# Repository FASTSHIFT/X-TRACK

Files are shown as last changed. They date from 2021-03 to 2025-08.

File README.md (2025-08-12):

# X-TRACK
> 开源GPS自行车码表。
> 
> 拥有可显示实时位置的离线地图。
> 
> 支持记录和显示实时轨迹以及导出标准GPX格式的轨迹文件。
> 
> 全新设计的["页面生命周期管理"](https://github.com/FASTSHIFT/X-TRACK/tree/main/Software/X-Track/USER/App/Utils/PageManager)和["消息订阅发布框架"](https://github.com/FASTSHIFT/X-TRACK/tree/main/Software/X-Track/USER/App/Utils/DataCenter)。
>
> 演示视频：https://www.bilibili.com/video/BV1GB4y1K7VV
>
> 二代版本：https://www.bilibili.com/video/BV1aS421X779

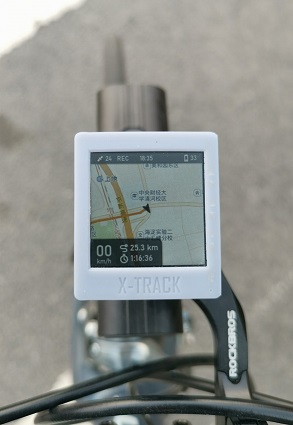
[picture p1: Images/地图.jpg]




## GUI
> [LVGL V8](https://github.com/lvgl/lvgl)

## 硬件配置
* 1.主控: AT32F435CGU7 (主频:288MHz RAM:512KB ROM:1MB)
* 2.屏幕: ST7789 IPS 1.54inch SPI接口 240x240分辨率 60Hz刷新率
* 3.储存器: Micro SD CARD 32GB 
* 4.输入设备: 旋转编码器
* 5.RTC: MCU内置RTC时钟
* 6.加速度计: LSM6DSM (支持硬件计步输出)
* 7.地磁计: LIS3MDL
* 8.GPS: ATGM336H (BDS + GPS + GLONASS + GALILEO + QZSS + SBAS)
* 9.电池: Li-ion 3.7V 683030 700mAh
* 10.电源管理: LP5907-3.3 + MCP73831
* 11.外壳: 3D打印 光固化

## 功能
* 1.支持速度、距离、时间、卡路里、航向显示
* 2.拥有**离线地图**，支持显示实时位置，支持缩放
* 3.支持计步
* 4.支持经纬度、海拔显示
* 5.支持RTC自动根据GPS校准
* 6.支持记录轨迹，可导出[GPX格式](https://zh.wikipedia.org/wiki/GPX)的文件
* 7.支持掉电自动保存数据(JSON格式文件)
* 8.四小时续航 (持续工作，始终亮屏)
* 9.支持在[PC模拟器](https://github.com/FASTSHIFT/X-TRACK/tree/main/Software/X-Track/Simulator)模拟，脱离硬件调试(配置为**Release x86**)
* 10.支持显示实时轨迹
* 11.待续...

## 实物演示
### 测速
https://user-images.githubusercontent.com/26767803/120889722-1f8d8e80-c631-11eb-8294-df79f151dedb.mp4

### 历史轨迹显示([GPXSee](https://github.com/tumic0/GPXSee))
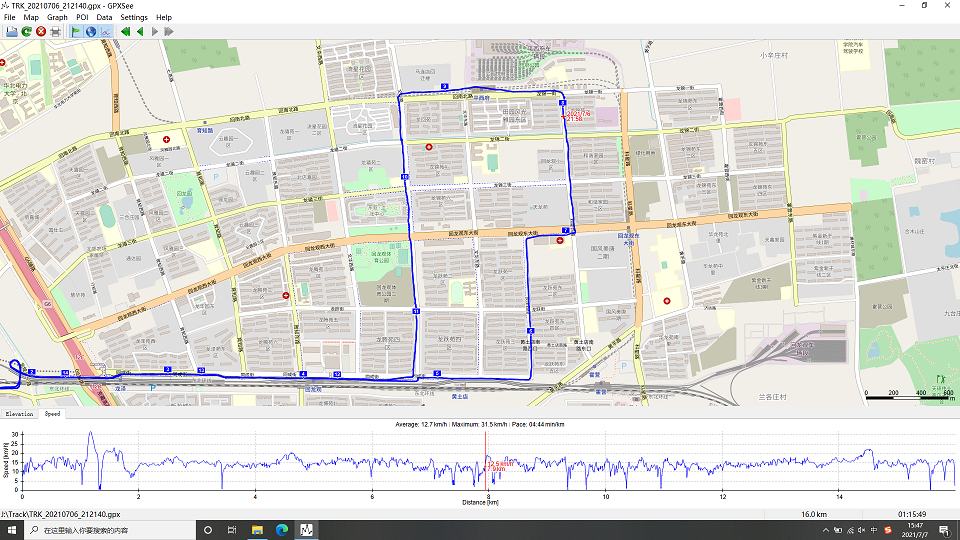
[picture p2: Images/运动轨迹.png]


## 常见故障
见文档: [常见故障排查](https://github.com/FASTSHIFT/X-TRACK/tree/main/Hardware#%E5%B8%B8%E8%A7%81%E6%95%85%E9%9A%9C%E6%8E%92%E6%9F%A5)

更细节的问题可以咨询DeepWiki -> 

## 致谢
> 感谢[@davidce](https://www.geek-workshop.com/home.php?mod=space&uid=204)贡献的参考设计“[自制基于arduino的GPS地图导航系统3.0](https://www.geek-workshop.com/thread-8835-1-1.html)”。

> 感谢[@W-Mai](https://github.com/W-Mai)改进的[地图下载链接生成工具](https://github.com/W-Mai/XLocateDownloader/releases/download/1.0.0/MapDownloader.zip)、[地图下载器](https://github.com/W-Mai/XLocateDownloader)、[LVGL图片转换器(Python版)](https://github.com/W-Mai/lvgl_image_converter)、[批量文件重命名工具](https://github.com/W-Mai/filename_renamer)。

> 感谢[@Trigger-CN](https://github.com/Trigger-CN)的[UI设计](https://github.com/FASTSHIFT/X-TRACK/tree/main/ArtDesign)。

> 感谢[@MouriNaruto](https://github.com/MouriNaruto)的LVGL Visual Studio模拟器[lv_sim_visual_studio](https://github.com/lvgl/lv_sim_visual_studio)。

> 感谢[@dj140](https://github.com/dj140)编写[地图下载教程](https://github.com/FASTSHIFT/X-TRACK/blob/main/Tools/README.md)。

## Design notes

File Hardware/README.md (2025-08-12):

## 编译
* 参见: [编译说明](https://github.com/FASTSHIFT/X-TRACK/blob/main/Software/README.md)

## 硬件修改
* PCB打样的厚度选择**0.8mm**或**1mm**。
* 去除**D4**二极管，防止充电时自动开机，导致充电变慢和发热。
* 注意**D2**二极管方向，方向是和其他二极管相反的。否则会发生开机一段时间自动关机的情况。
* GPS模块需要由**HT1818Z3G5L**更换为**ATGM336H**(购买链接在下方)，否则外壳放不下。关于接线，GPS模块的**TX**脚接板子的**T焊盘**,**RX**脚接板子的**R焊盘**。注意GPS的天线**不要**碰到旁边的法拉电容，否则导致模块发热且收不到信号。
* 地磁计**LIS3MDL**和加速度计**LSM6DSM**在该系统中作用不大，又由于芯片涨价导致整机成本过高，可以不安装。
* MCU:**AT32F435CGU7**或**AT32F403ACGU7**
如果定不到货，可以尝试[@johnsbark](https://github.com/johnsbark)设计的[改进版硬件](https://github.com/FASTSHIFT/X-TRACK/tree/main/Hardware/X-TRACK%20%E6%94%B9%E8%BF%9B%E7%89%88)方案（红框内的MCU都可以进行尝试）。

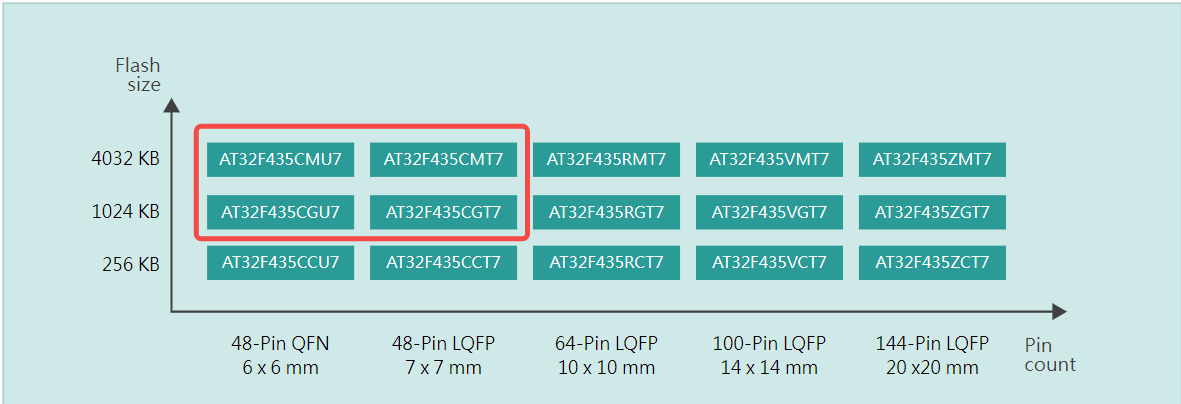
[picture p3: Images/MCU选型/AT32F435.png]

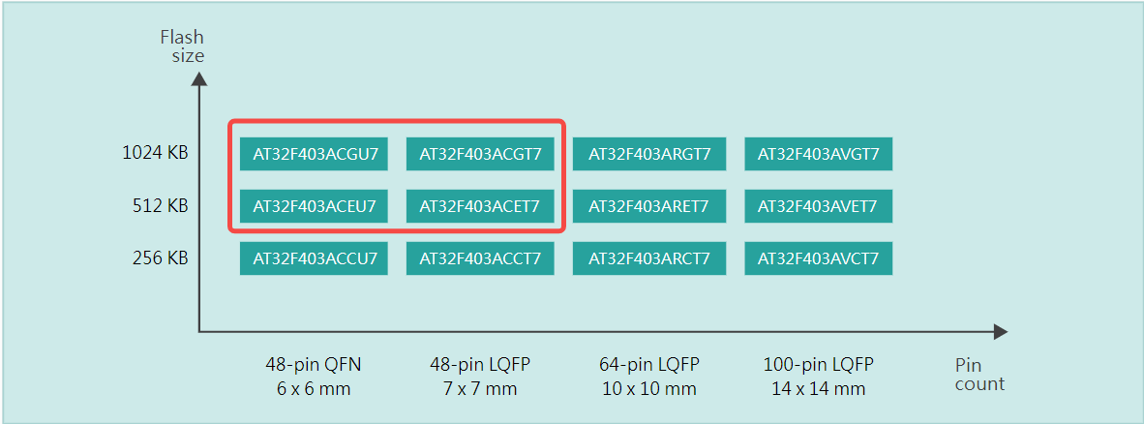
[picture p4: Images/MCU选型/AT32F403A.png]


* 关于其他品牌MCU替换的性能需求: 主频 >150M，RAM >=200K，FLASH >=512K，SPI速度 >=50Mbps。 

## 特殊器件购买链接
* 电池 (选择 683030) https://detail.tmall.com/item.htm?id=634173891714
* 旋转编码器 https://item.taobao.com/item.htm?id=598028191617
* 屏幕 (选择 裸屏) https://item.taobao.com/item.htm?id=600653923469
* 调试口 (选择 4P弯针) https://item.taobao.com/item.htm?id=522574977704
* 码表底座 (选择 竖向按装拓展片孔距M3*20~21mm[塑胶材料 3g]) https://item.taobao.com/item.htm?id=599529362799
* GPS模块 (ATGM336H) https://item.taobao.com/item.htm?id=603186739934
* AON3400 (AO3400 N沟道MOS管) https://item.taobao.com/item.htm?id=522574089119
* 侧盖螺丝 https://item.taobao.com/item.htm?id=522574685586
* Pad (焊接电池线的焊盘，非实体元件)

## 焊接
* [焊接教程](https://github.com/FASTSHIFT/X-TRACK/blob/main/Hardware/%E7%84%8A%E6%8E%A5%E8%B0%83%E8%AF%95%E6%8C%87%E5%8C%97.md)

## 常见故障排查
> GPS连不上
* 到开阔地带进行定位
* 进入系统信息页面查看GPS栏是否能获取到UTC时间
* 如果一直无法获取UTC时间，则检查GPS模块和MCU的硬件连接，确保通信波特率为9600
* 检查GPS天线朝向，参考下图

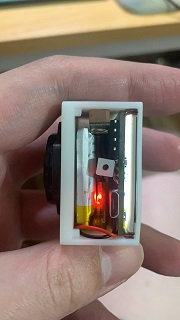
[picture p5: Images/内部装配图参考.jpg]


> 地图不显示
* 在首次定位成功前，默认加载的地图区域是北京，等待定位成功或者修改**SystemSave.json**里的经纬度配置
* 检查状态栏是否有SD卡图标
* 检查地图文件路径是否为`/MAP/z/x/y.bin`
* **不要使用旧版地图工具**

> 地图概率性显示异常/文件丢失
* SD卡到MCU的线路可能有虚焊或者短路，尝试重新焊接SD卡和MCU
* 尝试更换不同品牌或不同容量的SD卡

> 不开机、关不了机、程序烧录失败
* 长按编码器开关机（关机需要长按5秒以上）
* 检查供电是否正常，MCU和其他器件上的VCC脚上的电压是否是3.3V
* 检查所有二极管方向是否正确

> 长按编码器发出“嘟嘟”两声；无法启动轨迹记录
* 如果在主界面的选择光标停留在最中间的按钮，如果长按发出此声音表示：GPS未连接，无法开启轨迹记录。如果长按发出“哆来咪”，则表示：GPS已连接，轨迹记录开始。
* 到开阔区域等待GPS定位成功，再启动轨迹记录。

> 开机了但黑屏
* 检查屏幕排线和MCU间是否短路或虚焊
* 检查背光是否有电压

> SD卡无法读取
* 在系统信息页面查看"Storage"项，是否能正常读取到SD卡容量和类型
* 检查SD卡座和MCU间是否有短路或虚焊
* 检查SD卡格式是否为FAT32

> SD卡内没有生成**SystemSave.json**配置文件
* **SystemSave.json**在第一次关机后自动生成

> 地图坐标有恒定偏移
* 尝试修改SD卡根目录下的**SystemSave.json**里的**useWGS84**选项[配置地图坐标系统](https://github.com/FASTSHIFT/X-TRACK/tree/main/Software#%E7%B3%BB%E7%BB%9F%E9%85%8D%E7%BD%AE%E6%96%87%E4%BB%B6)

> 速度不准
* 不同厂家的GPS模块性能不一，测得的速度可能会有小幅度跳动(<±2KM/h)
* 检查GPS天线朝向，参考第一点
* 更换GPS模块

> PC模拟器上无法显示地图/显示颜色异常
* MAP地图文件夹放在X-TRACK工程的根目录`~/X-TRACK/MAP/`
* 修改**SystemSave.json**里的经纬度配置到希望显示地图的地方
* 确认生成的地图文件命名格式为`/z/x/y.png`
* 修改**SystemSave.json**的`"sysConfig.mapExtName"`项目，将`"bin"`改为`"png"`

> 怎么在PC端显示轨迹
* 找到SD中的`Track`目录下的对应日期的`.gpx`文件，导入[gpx.studio](https://gpx.studio/zh/app)即可展示轨迹。

更多问题可以咨询DeepWiki -> 

## 2.0寸屏版本
https://github.com/FASTSHIFT/X-TRACK/tree/2.0-inch by[@HanfG](https://github.com/HanfG)

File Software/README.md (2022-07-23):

## 编译说明
* MCU固件: 务必使用**Keil v5.25**或以上的版本进行编译（旧版本编译器不能完全支持**C++ 11**的语法），在Keil中编译器版本设置为ARM Compiler 5。
* 编译前需要安装[Artery](https://www.arterytek.com/cn/index.jsp)官方Pack，**为了确保顺利编译请安装[Software/Pack](https://github.com/FASTSHIFT/X-TRACK/tree/main/Software/Pack)目录下的指定版本**。

* 如果安装Pack后，Keil依然报以下这类错误，可能是之前安装了 Keil v4 兼容包 (MDK v4 Legacy Support) 导致的，请尝试**卸载此包或重新安装 Keil v5**。

`Error #540: 'Keil::Device:StdPeriph Drivers:ADC:1.0.1' component is not available for target 'X-Track'`
 
  ### 注意
  **不要修改芯片选型**，因为修改芯片选型后启动文件会重新生成，堆栈大小会恢复默认值，而使用默认的栈大小会导致**栈溢出**。现象是启动后立即蓝屏，提示发生**HardFault**(如下图所示)，串口会输出详细的错误信息。如果确实需要修改芯片选型，请参考工程原始的启动文件进行修改。



## VS模拟器配置
* 编译：使用`Visual Studio 2019`编译，配置为`Release` `x86`模式，`Debug`模式需要额外安装[ASAN](https://docs.microsoft.com/en-us/cpp/sanitizers/asan?view=msvc-170)插件。
* 文件配置：

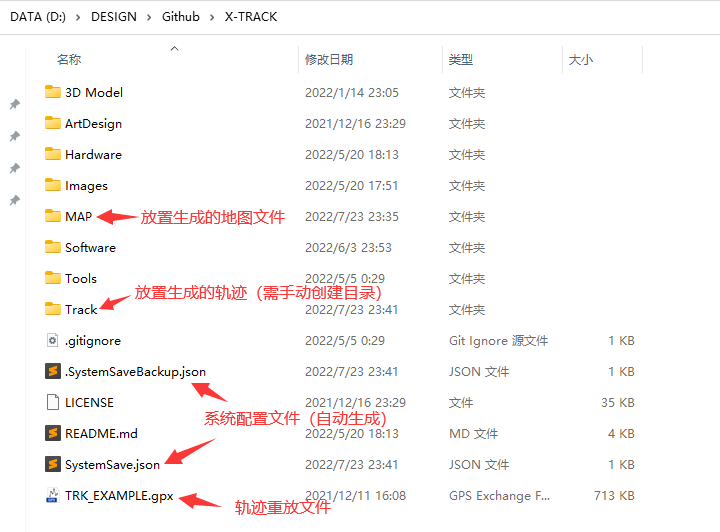
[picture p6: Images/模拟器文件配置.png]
images


## 系统配置文件
系统会在根目录下自动生成`SystemSave.json`的文件，用于储存和配置系统参数:
```javascript
{
  "sportStatus.totalDistance": 0,              // 总里程(m)
  "sportStatus.totalTimeUINT32[0]": 0,         // 总行驶时间(ms)，低32位
  "sportStatus.totalTimeUINT32[1]": 0,         // 总行驶时间(ms)，高32位
  "sportStatus.speedMaxKph": 0,                // 最高时速(km/h)
  "sportStatus.weight": 65,                    // 体重(kg)
  "sysConfig.longitude": 116.3913345,          // 上次开机记录的位置(经度)
  "sysConfig.latitude": 39.90741348,           // 上次开机记录的位置(纬度)
  "sysConfig.soundEnable": 1,                  // 系统提示音使能(1:开启，0:关闭)
  "sysConfig.timeZone": 8,                     // 时区(GMT+)
  "sysConfig.language": "en-GB",               // 语言(尚不支持多语言切换)
  "sysConfig.arrowTheme": "default",           // 导航箭头主题(default:全黑，dark:橙底黑边，light:橙底白边)
  "sysConfig.mapDirPath": "/MAP",              // 存放地图的文件夹路径
  "sysConfig.mapExtName": "bin",               // 地图文件扩展名
  "sysConfig.mapWGS84": 0                      // 坐标系统配置(0:GCJ02, 1:WGS84)
}
```

## 目录结构
```
 X-Track
    ├─ArduinoAPI                -- 通用 Arduino API 抽象层
    ├─Doc                       -- 芯片相关文档
    ├─Libraries                 -- 硬件驱动程序
    │  ├─Adafruit_GFX_Library   -- Adafruit_GFX轻量级图形库
    │  ├─Adafruit_ST7789        -- ST7789屏幕驱动
    │  ├─ButtonEvent            -- 按键事件库
    │  ├─cm_backtrace           -- ARM Cortex-M 系列 MCU 错误追踪库
    │  ├─LIS3MDL                -- LIS3MDL地磁计驱动
    │  ├─LSM6DSM                -- LSM6DSM陀螺仪加速度计驱动
    │  ├─MillisTaskManager      -- 合作式任务调度器
    │  ├─SdFat                  -- 文件系统
    │  ├─StackInfo              -- 栈空间使用统计库
    │  └─TinyGPSPlus            -- NMEA协议解析器
    ├─MDK-ARM_F403A             -- AT32F403A Keil工程
    ├─MDK-ARM_F435              -- AT32F435  Keil工程
    ├─Simulator                 -- Visual Studio LVGL PC模拟器
    ├─Tools                     -- 实用工具
    └─USER                      -- 用户程序
        ├─App                   -- 应用层
        │  ├─Common             -- 通用程序
        │  │  ├─DataProc        -- 应用后台数据处理
        │  │  ├─HAL             -- 硬件抽象层定义/Mock实现
        │  │  └─Music           -- 操作音管理
        │  ├─Config             -- 应用配置文件
        │  ├─Pages              -- 页面
        │  │  ├─Dialplate       -- 表盘页面
        │  │  ├─LiveMap         -- 地图页面
        │  │  ├─Startup         -- 开机页面
        │  │  ├─StatusBar       -- 状态栏
        │  │  ├─SystemInfos     -- 系统信息页面
        │  │  └─_Template       -- 页面模板
        │  ├─Resource           -- 资源池
        │  │  ├─Font            -- 字体
        │  │  └─Image           -- 图片
        │  └─Utils              -- 通用应用层组件
        │      ├─ArduinoJson    -- JSON库
        │      ├─DataCenter     -- 消息发布订阅框架
        │      ├─Filters        -- 常用滤波算法库
        │      ├─GPX            -- GPX生成器
        │      ├─GPX_Parser     -- GPX解析器
        │      ├─lv_allocator   -- 自定义allocator
        │      ├─lv_anim_label  -- 文本动画组件
        │      ├─lv_ext         -- lvgl功能扩展
        │      ├─lv_img_png     -- PNG显示组件
        │      ├─lv_poly_line   -- 多段线控件
        │      ├─MapConv        -- WGS84/GCJ02 地图坐标转换器
        │      ├─new            -- new/delete 重载
        │      ├─PageManager    -- 页面调度器
        │      ├─PointContainer -- 坐标压缩容器
        │      ├─ResourceManager-- 资源管理器
        │      ├─StorageService -- KV储存服务
        │      ├─Stream         -- Arduino Stream 流式库
        │      ├─TileConv       -- 瓦片坐标转换器
        │      ├─Time           -- 时间转换算法库
        │      ├─TonePlayer     -- 异步方波音乐播放器
        │      ├─TrackFilter    -- 流式轨迹坐标拐点/线段提取器
        │      └─WString        -- Arduino WString 字符串库
        ├─HAL                   -- 硬件抽象层
        └─lv_port               -- lvgl与硬件的接口
```

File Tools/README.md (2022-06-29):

# 地图下载说明

## 1.下载安装[Crimson/地图下载器](https://gitee.com/CrimsonHu/java_map_download/)

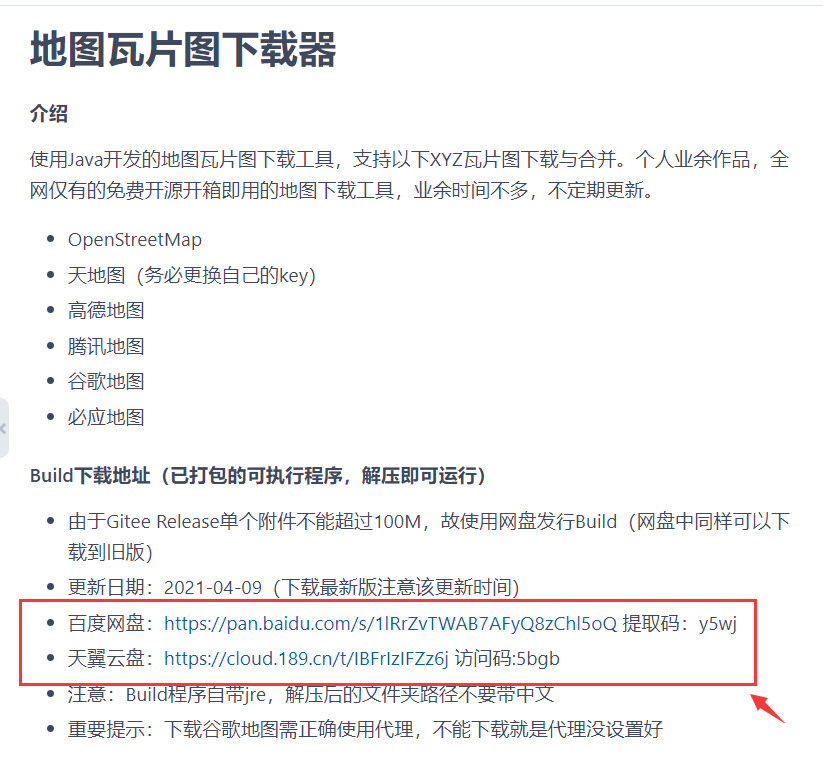
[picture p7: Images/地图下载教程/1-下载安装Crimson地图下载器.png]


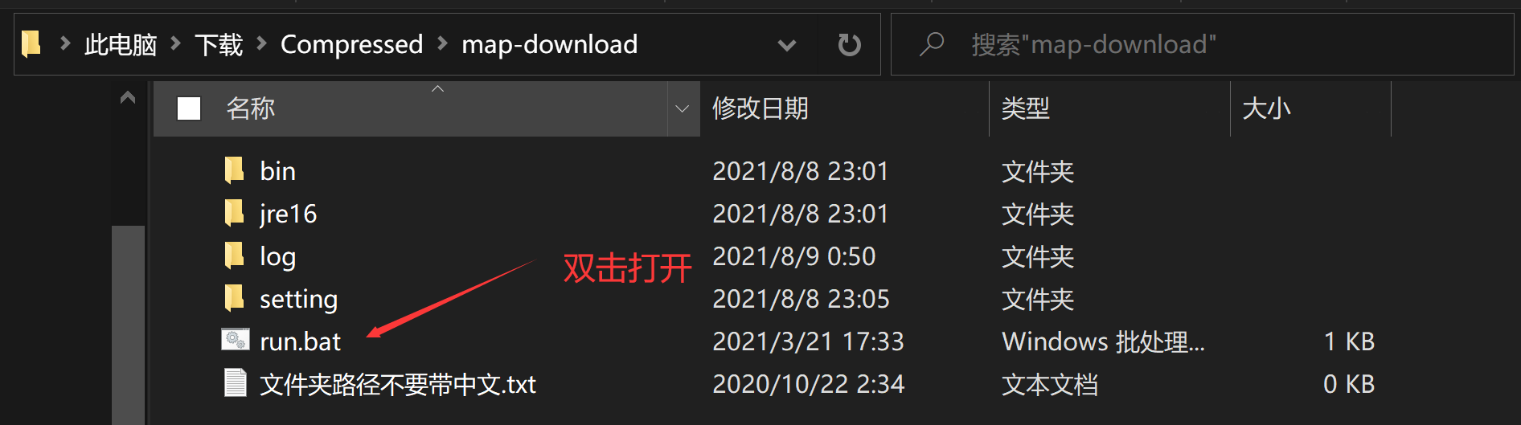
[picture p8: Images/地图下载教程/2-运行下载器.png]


## 2.选择要下载的地图区域
 * 选择自己所在区域下载即可，**切勿选择过大范围**，下载区域设置小一些后续下载会快很多。
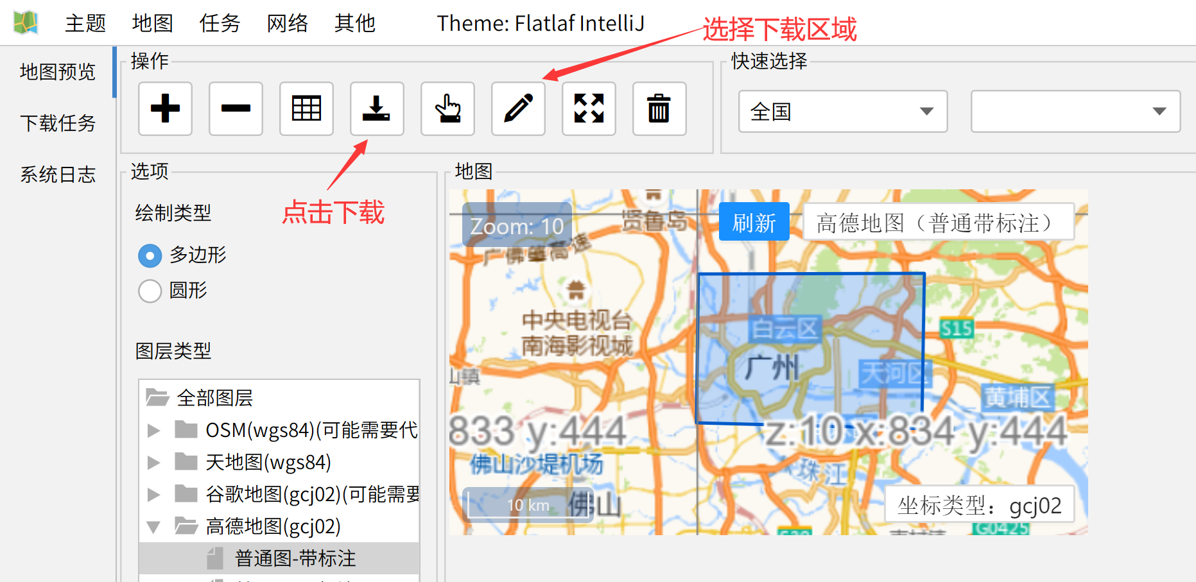
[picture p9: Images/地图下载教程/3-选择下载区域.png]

## 3.下载地图
 * 下载地图等级根据自己喜好选择，等级越高地图越详细，但是文件也越大（建议只勾选**0~16级**，如果出现0~2级下载失败的情况，可以不勾选）。命名格式为`/z/x/y.png`格式，保存路径新建一个`MAP`文件夹
 
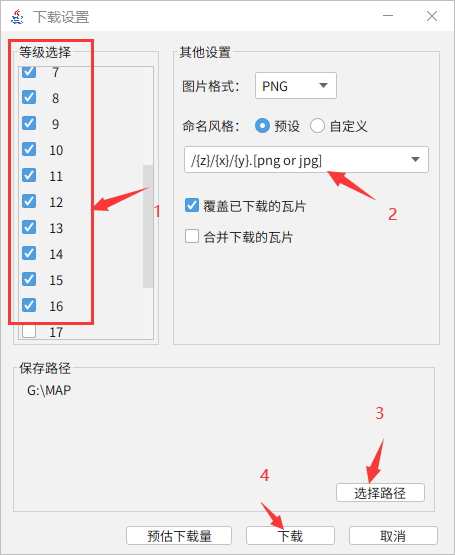
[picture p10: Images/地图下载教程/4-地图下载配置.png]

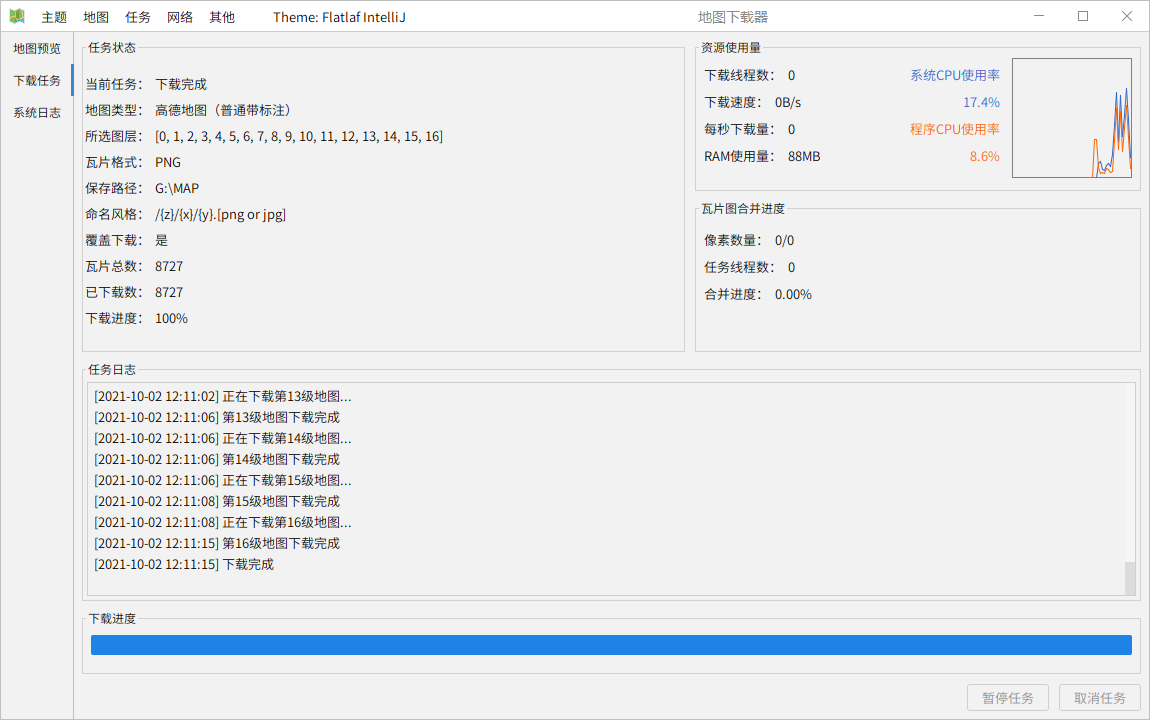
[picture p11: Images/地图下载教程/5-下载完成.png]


## 4.转换地图文件
* 下载完成后，使用`Tools`文件夹下的`TilesConverterForLVGL.exe`进行转换（[使用教程](https://github.com/FASTSHIFT/X-TRACK/tree/main/Images/MapConverter%E4%BD%BF%E7%94%A8%E6%95%99%E7%A8%8B)）
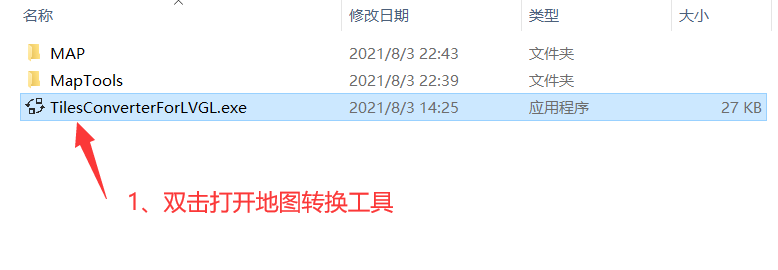
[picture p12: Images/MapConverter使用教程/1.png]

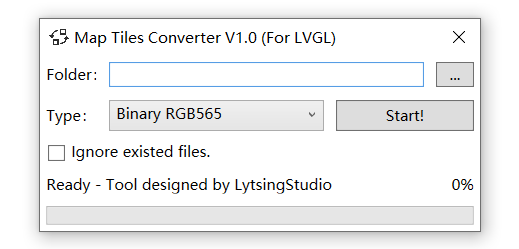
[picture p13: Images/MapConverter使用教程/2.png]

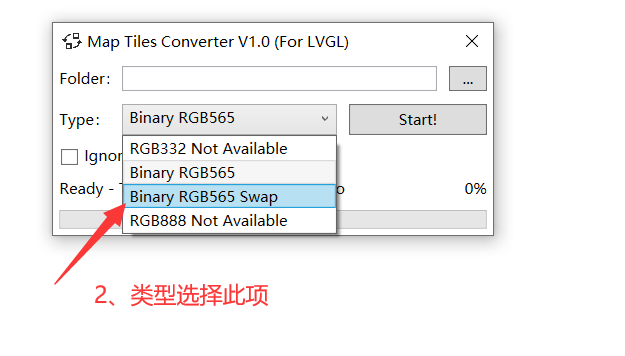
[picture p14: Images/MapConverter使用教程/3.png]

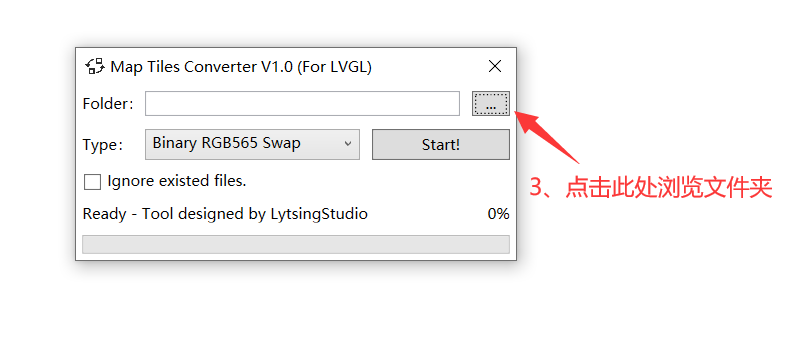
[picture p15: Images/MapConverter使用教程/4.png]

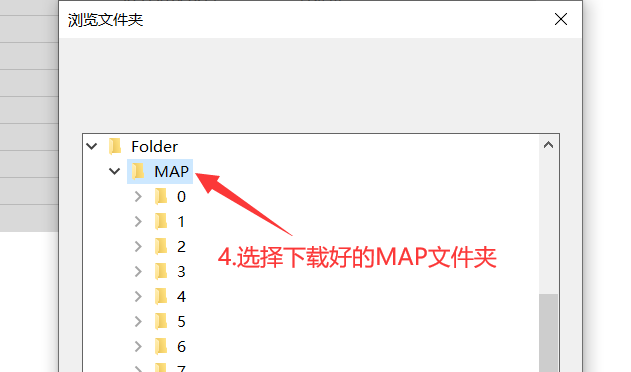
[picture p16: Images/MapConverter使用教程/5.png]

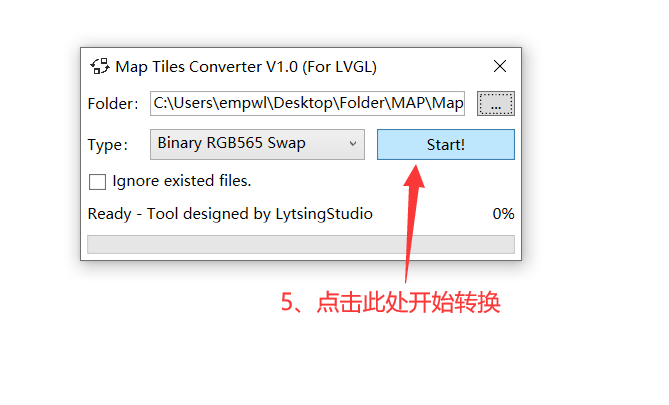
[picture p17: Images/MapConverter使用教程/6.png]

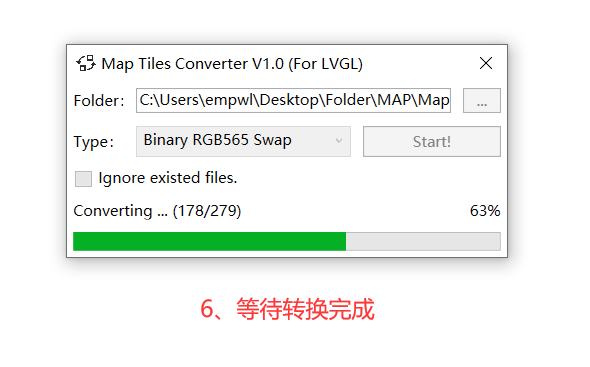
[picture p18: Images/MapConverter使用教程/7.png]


## 5.拷贝"MAP"文件夹至SD卡根目录
### 注意：
 * SD卡需要格式化为**FAT32格式**。
 * SD卡插入开机以后，会在第一次关机时自动创建`SystemSave.json`文件，其中：
 > 通过`"mapDirPath"`设置地图源文件夹，默认路径为`"/MAP"`（SD卡可以储存多个地图源，通过此选项切换）
 > 
 > 通过`"mapWGS84"`设置坐标系统，如果发现地图偏移请尝试修改。
 * `SystemSave.json`文件详细说明见[编译说明](https://github.com/FASTSHIFT/X-TRACK/blob/main/Software/README.md)。

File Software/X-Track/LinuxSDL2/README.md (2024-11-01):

# X-TRACK Linux SDL2

## 编译

```sh
make -j
```

## 执行

```sh
./xtrack
```

## 其他说明

* 1.可以通过修改Makefile的`LV_COLOR_DEPTH`配置屏幕的颜色深度，默认32bpp。
* 2.关机自动保存功能不支持。
* 3.轨迹记录功能未测试，可能不支持。

## Demo
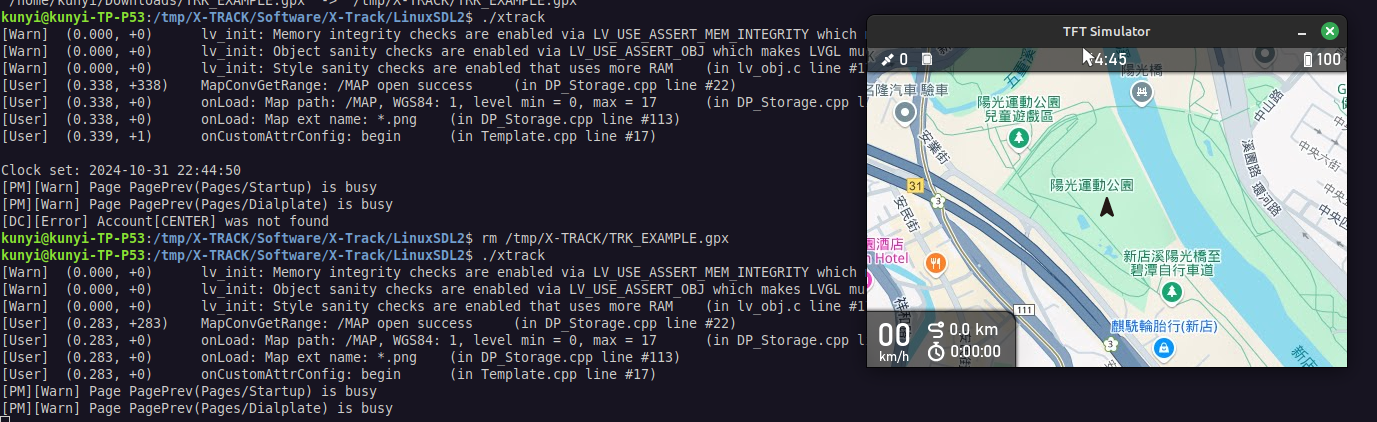
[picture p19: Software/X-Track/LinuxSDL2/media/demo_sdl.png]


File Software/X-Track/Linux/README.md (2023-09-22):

# X-TRACK Linux

## 编译

```sh
make -j
```

## 执行

```sh
sudo ./xtrack /dev/input/event0
```

注意这边的`/dev/input/event0`指的是设备上鼠标或者触摸屏event设备节点，不同设备ID是不同的，如果发现无法输入，可以使用`evtest`工具自行查询和调整。

UI目前是直接渲染framebuffer的，尝试按键盘的`CTRL`+`ALT`+ `F1` 到 `F6`按键，切换framebuffer显示即可看到UI。

## 其他说明

* 1.可以通过修改Makefile的`LV_COLOR_DEPTH`配置屏幕的颜色深度，默认32bpp。
* 2.关机自动保存功能不支持。
* 3.轨迹记录功能未测试，可能不支持。

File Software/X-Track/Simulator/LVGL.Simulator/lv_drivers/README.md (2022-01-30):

# Display and Touch pad drivers

Display controller and touchpad driver to can be directly used with [LittlevGL](https://littlevgl.com).

To learn more about using drivers in LittlevGL visit the [Porting guide](https://docs.lvgl.io/latest/en/html/porting/index.html).

If you used a new display or touchpad driver with LittlevGL please share it with other people!

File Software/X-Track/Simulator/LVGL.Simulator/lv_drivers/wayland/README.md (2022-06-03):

# Wayland display and input driver

Wayland display and input driver, with support for keyboard, pointer (i.e. mouse) and touchscreen.
Keyboard support is based on libxkbcommon.

Following shell are supported:

* wl_shell (deprecated)
* xdg_shell

> xdg_shell requires an extra build step; see section _Generate protocols_ below.

Basic client-side window decorations (simple title bar, minimize and close buttons)
are supported, while integration with desktop environments is not.

## Install headers and libraries

### Ubuntu

```
sudo apt-get install libwayland-dev libxkbcommon-dev libwayland-bin wayland-protocols
```

### Fedora

```
sudo dnf install wayland-devel libxkbcommon-devel wayland-utils wayland-protocols-devel
```

## Generate protocols

Support for non-basic shells (i.e. other than _wl_shell_) requires additional
source files to be generated before the first build of the project. To do so,
navigate to the _wayland_ folder (the one which includes this file) and issue
the following commands:

```
cmake .
make
```

## Build configuration under Eclipse

In "Project properties > C/C++ Build > Settings" set the followings:

- "Cross GCC Compiler > Command line pattern"
  - Add ` ${wayland-cflags}` and ` ${xkbcommon-cflags}` to the end (add a space between the last command and this)

- "Cross GCC Linker > Command line pattern"
  - Add ` ${wayland-libs}` and ` ${xkbcommon-libs}`  to the end (add a space between the last command and this)

- In "C/C++ Build > Build variables"
  - Configuration: [All Configuration]

  - Add
    - Variable name: `wayland-cflags`
      - Type: `String`
      - Value: `pkg-config --cflags wayland-client`
    - Variable name: `wayland-libs`
      - Type: `String`
      - Value: `pkg-config --libs wayland-client`
    - Variable name: `xkbcommon-cflags`
      - Type: `String`
      - Value: `pkg-config --cflags xkbcommon`
    - Variable name: `xkbcommon-libs`
      - Type: `String`
      - Value: `pkg-config --libs xkbcommon`

## Init Wayland in LVGL

1. In `main.c` `#incude "lv_drivers/wayland/wayland.h"`
2. Enable the Wayland driver in `lv_drv_conf.h` with `USE_WAYLAND 1` and
   configure its features below, enabling at least support for one shell.
3. `LV_COLOR_DEPTH` should be set either to `32` or `16` in `lv_conf.h`;
   support for `8` and `1` depends on target platform.
4. After `lv_init()` call `lv_wayland_init()`.
5. Add a display (or more than one) using `lv_wayland_create_window()`,
   possibly with a close callback to track the status of each display:
```c
  #define H_RES (800)
  #define V_RES (480)

  /* Create a display */
  lv_disp_t * disp = lv_wayland_create_window(H_RES, V_RES, "Window Title", close_cb);
```
  As part of the above call, the Wayland driver will register four input devices
  for each display:
  - a KEYPAD connected to Wayland keyboard events
  - a POINTER connected to Wayland touch events
  - a POINTER connected to Wayland pointer events
  - a ENCODER connected to Wayland pointer axis events
  Handles for input devices of each display can be get using respectively
  `lv_wayland_get_indev_keyboard()`, `lv_wayland_get_indev_touchscreen()`,
  `lv_wayland_get_indev_pointer()` and `lv_wayland_get_indev_pointeraxis()`, using
  `disp` as argument.
5. After `lv_deinit()` (if used), or in any case during de-initialization, call
  `lv_wayland_deinit()`.

### Fullscreen mode

In order to set one window as fullscreen or restore it as a normal one,
call the `lv_wayland_window_set_fullscreen()` function respectively with `true`
or `false` as `fullscreen` argument.

### Disable window client-side decoration at runtime

Even when client-side decorations are enabled at compile time, they can be
disabled at runtime setting the `LV_WAYLAND_DISABLE_WINDOWDECORATION`
environment variable to `1`.

### Event-driven timer handler

Set `LV_WAYLAND_TIMER_HANDLER` in `lv_drv_conf.h` and call `lv_wayland_timer_handler()`
in your timer loop (in place of `lv_timer_handler()`).

You can now sleep/wait until the next timer/event is ready, e.g.:
```
/* [After initialization and display creation] */
#include <limits.h>
#include <errno.h>
#include <poll.h>

struct pollfd pfd;
uint32_t time_till_next;
int sleep;

pfd.fd = lv_wayland_get_fd();
pfd.events = POLLIN;

while (1) {
    /* Handle any Wayland/LVGL timers/events */
    time_till_next = lv_wayland_timer_handler();

    /* Run until the last window closes */
    if (!lv_wayland_window_is_open(NULL)) {
        break;
    }

    /* Wait for something interesting to happen */
    if (time_till_next == LV_NO_TIMER_READY) {
        sleep = -1;
    } else if (time_till_next > INT_MAX) {
        sleep = INT_MAX;
    } else {
       sleep = time_till_next;
    }

    while ((poll(&pfd, 1, sleep) < 0) && (errno == EINTR));
}
```

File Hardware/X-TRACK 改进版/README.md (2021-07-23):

# X-TRACK_LQFP
感谢@FASTSHIFT的开源项目X-TRACK
鉴于问遍了淘宝都没有AT32F403ACGU7，为了白嫖强行更换封装

X-TRACK的LQFP封装版本，将原先的AT32F403ACGU7更换为AT32F403ACGT7（即STM32F103C8T6那个最常见的48-pin LQFP 7X7封装） 重新布线过，第一版亲测正常工作，之后又优化了部分布线，减少焊接时可能出现的问题
1626970879579 jpg
9F54E02A8FF0067CA164CD360D0CCE11
2DA712428BFF5B875828A8FB9A96AAC1
QQ图片20210723003431

焊接过程中极易出现短路等故障，需要重点注意的有：  
* 1.风枪必备，有锡浆更好。焊接注意顺序，背面不建议上风枪，手焊足以  
* 2.TF卡位置注意引脚焊接短路问题（用锡浆的要注意残留问题，容易引起短路），有问题的话插TF卡会低沉的发出滴滴两声，成功的话则是有一段插入音效  
* 3.编码器要焊牢！要焊牢！要焊牢！此板子大面积的铺铜带来的缺点就是焊接时温度上不去会造成虚焊，“尤其是用锡浆的”，我调试的时候掰下来了，干坏个焊盘，现版本编码器处的焊盘以进行加粗等优化处理。  
* 4.加速度计可以用低配版LSM6DS3代，因为引脚寄存器都一样，只是功耗高一倍，(买模块要便宜些大概16元——优信电子，磁罗盘在CJMCU长江智动58元)

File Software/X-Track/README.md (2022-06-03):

# X-TRACK 更新日志
> https://github.com/FASTSHIFT/X-TRACK

## [v0.1] - 2021-3-21
* 1.框架搭建完成，全新MVP(Model-View-Presenter)架构
* 2.更新3D Model，门板完美安装
* 3.修复串口缓冲队列过载导致GPS解析连续失败的BUG
* 4.添加长按开机功能
* 5.添加计步显示
* 6.速度显示使用kph为单位
* 7.添加新的ButtonEvent库
* 8.添加Filters数字滤波器库 
* 9.添加新的TonePlayer库
* 10.格式化LIS3DMDL库的代码
* 11.格式化LISM6DSM库的代码
* 12.添加新的简易表盘页面
* 13.为LiveMap页面添加group，优化Encoder交互
* 14.LiveMap已可以正常显示航向，使用GPS的航向信息
* 15.重新校准MapConv地图坐标
* 16.添加HAL_AHRS姿态解算
* 17.添加HAL_Encoder接口
* 18.添加HAL_GPS串口透传，可使用上位机对GPS模块进行配置
* 19.添加GNSSToolKit_Lite配置工程
* 20.添加lv_get_indev()
* 21.添加__wfi()，可能省点电

## [v0.2] - 2021-4-19
* 1.添加ArtDesign工程，使用Adobe Illustrator
* 2.添加异步无锁Buffer库：PingPongBuffer
* 3.删除离线图片和字体转换工具
* 4.修改页面ID格式：DialplatePage->Pages/Dialplate
* 5.添加消息发布订阅框架：DataCenter
* 6.将HAL.h转移至应用层
* 7.HAL: Clock_GetValue->Clock_GetInfo
* 8.在PC模拟器上使用PC的电量显示
* 9.更新PageManager
* 10.降低SD热插拔监控扫描速度
* 11.删除Music_Astronomia
* 12.在编码器按下时忽略滚动，减少误触
* 13.更新Dialplate页面
* 14.更新LiveMap页面

## [v0.3] - 2021-5-12
* 1.lvgl迁移至v8.0.0
* 2.PingPongBuffer转移至App/Utils/DataCenter，以提供无锁的线程安全的数据块访问，添加volatile关键字
* 3.VS工程在Debug下启用AddressSanitizer，捕获异常的内存操作
* 4.Heap和Stack调整
* 5.更新ButtonEvent库
* 6.更换新的文件系统接口lv_fs_if
* 7.系统配置文件SysConfig.h -> Config.h
* 8.Utils添加WString for PC
* 9.ResourceManager更新，使用std::vector作为资源池
* 10.PageManager更新，lvgl-v8适配，简化子模块命名，使用std::vector作为页面池，使用std::stack作为页面栈
* 11.地图坐标转换器MapConv更新，但未找到更精确的地图坐标换算算法
* 12.去除lv_theme_custom
* 13.添加GPX库，将来用于生成GPX格式的标准轨迹记录文件
* 14.使用C++ template重写Filters滤波器合集库
* 15.数据发布订阅处理中心DataCenter更新，添加错误码、通知、数据提交等功能
* 16.StatusBar更新，添加背景色柔和渐变、电池充电等特效
* 17.LiveMap页面更新，新的滚动条和info按钮
* 18.Dialplate页面更新，操作按钮已可以使用
* 19.数据处理节点DP_SportStatus更新，更新卡路里换算算法、距离、速度滤波等处理方法
* 20.添加新的数据处理节点DP_Recorder，用于记录轨迹于SD卡中
* 21.电池AD采样使用中断模式，而不使用DMA
* 22.文件系统SD对象不再全局共享
* 23.屏蔽开机启动时Encoder按键事件

## [v0.4] - 2021-5-16
* 1.lvgl更新
* 2.支持导出GPX格式的轨迹记录文件，推荐使用[GPXSee](https://github.com/tumic0/GPXSee)查看轨迹
* 3.Clock_info_t结构体成员单词全拼
* 4.LiveMap页面更新，改进的操作方式与显示特效
* 5.去除MAP数据映射宏，使用lv_map替代
* 6.SD支持时间戳记录，支持自动检测和创建缺失的文件夹

## [v0.5] - 2021-5-23
* 1.添加SystemInfos页面
* 2.添加IMU和地磁MAG数据处理节点
* 3.修改轨迹记录默认文件名
* 4.规范lv_event成员参数获取方式
* 5.修复DataCenter缓冲区读取释放BUG
* 6.添加Version.h存放版本信息
* 7.HAL::GPS_Info_t添加hour_utc成员

## [v0.6] - 2021-5-31
* 1.更新lvgl
* 2.添加App_Uninit()，绑定关机事件
* 3.添加DP_LIST.inc，更优雅的数据处理节点注册方式
* 4.添加IMU/MAG_Commit，向数据中心提交数据
* 5.添加StorageService数据储存服务，使用JSON格式储存数据
* 6.添加ArduinoJson解析库
* 7.运动数据处理节点 sportStatusInfo -> sportStatus，添加储存绑定
* 8.去除HAL::AHRS
* 9.GPS在未定位成功时，经纬度海拔统一置零
* 10.HAL::Power添加关机事件回调
* 11.CONTROLLER -> PRESENTER
* 12.添加Startup页面，展示开机动画
* 13.LiveMap地图页面，在未定位成功时的默认位置为天安门
* 14.StatusBar状态栏，函数AppearAnimStart -> Appear 
* 15.解决SystemInfos页面在自动管理Cache时退出页面造成的Crash
* 16.修复MAG数据显示的bug
* 17.DataCenter添加主账户AccountMain，自动订阅所有的子节点，用于发送通知
* 18.PageManager在删除root时需要使用异步删除lv_obj_del_async()，在root动画生命周期结束后删除
* 19.降低GPS和Sensor的数据更新频率，分别为5Hz和1Hz

## [v0.7] - 2021-6-5
* 1.更新拆分STL模型文件
* 2.TonePlayer转移至App/Utils
* 3.在关机时自动保存正在记录的轨迹文件
* 4.优化轨迹记录操作体验
* 5.DataCenter合并定时器回调到AccountEvent
* 6.AccountEvent添加Account* 参数
* 7.添加DATA_PROC_INIT_DEF节点定义
* 8.添加StatusBar状态栏、MusicPlayer播放器、TzConv时区转换器数据节点
* 9.优化电池电量滤波算法 Hysteresis + MedianQueue
* 10.转移STORAGE_VALUE_REG宏定义至DataProc_Def.h
* 11.在SD插入时自动加载JSON系统配置文件
* 12.添加Common/Music
* 13.优化DataCenter和PageManager日志输出等级
* 14.优化GPX库
* 15.优化PAGE_STASH_POP
* 16.去除PageManager::Pop函数的stash参数
* 17.添加Arduino Time时间转换库
* 18.去除GPS_Info_t的hour_utc成员，使用TzConv进行时区转换

## [v0.8] - 2021-6-15
* 1.格式化所有代码
* 2.APP_Init添加ACCOUNT_SEND_CMD，简化Account通知调用
* 3.dataCenter("Bilibili") -> dataCenter("CENTER")
* 4.添加SysConfig节点，用于保存系统设置
* 5.Power节点使用Account通知方式调用MusicPlayer，而不使用HAL::Audio_PlayMusic
* 6.去除HAL::Backlight_UpdateBKP()和Backlight_GetBKP()
* 7.DialplateModel添加节点名称验证
* 8.LiveMapModel添加节点名称验证
* 9.DataCenter添加Account双buffer动态内存申请检查
* 10.Account::GetPublisherLen() -> GetPublisherSize(), GetSubscribeLen() -> GetSubscribeSize()
* 11.更新lv_anim_timeline，支持设置progress，已提交至lvgl主线
* 12.去除lv_obj_ext_func不常用的函数
* 13.StorageService扩大JSON_BUFFER_SIZE 256 -> 512, 添加字符串类型参数读取返回值检查
* 14.添加硬件定时器配置到Config.h
* 15.修改版权声明遗留拼写错误

## [v0.9] - 2021-6-24
* 1.更新ButtonEvent，支持EVENT_LONG_PRESSED_RELEASED
* 2.调整lvgl内存池，32KB -> 64KB
* 3.HAL_GPS支持读取csv格式的文件，在PC上模拟位置变化
* 4.更新LiveMap页面，支持实时绘制运动轨迹，支持自适应分辨率动态加载地图
* 5.更新Startup页面，移除默认样式，并在开机动画过程中屏蔽Encoder事件
* 6.修复SystemInfos页面因为忘记释放style.focus导致的内存泄漏
* 7.优化DataCenter的Account的cache申请失败判断逻辑
* 8.添加lv_allocator，使用lvgl接管std::vector内存管理实现
* 9.更新MapConv，MapKeyRootName -> MapFilePath，ConvertMapTile() -> ConvertPosToTile()
* 10.添加TileConv，通用的瓦片动态加载算法实现
* 11.添加TrackFilter轨迹过滤器，包含TrackPointFilter曲线关键点提取算法和TrackLineFilter曲线区域裁剪算法
* 12.HAL::Encoder添加Encoder_SetEnable()方法

## [v1.0] - 2021-7-1
* 1.更新lvgl v8.1.0 dev
* 2.添加TrackFilter数据处理节点，储存过滤后的拐点坐标
* 3.优化DP_Clock RTC自动校准
* 4.优化DP_GPS提示音播放，添加cache，使用Publish向订阅者推送数据，减少定时轮询拉取
* 5.添加GPX_Parser，支持直接解析GPX数据还原轨迹
* 6.Config.h转移到App
* 7.页面添加namespace Page命名空间
* 8.优化LiveMap轨迹显示，在轨迹记录时显示轨迹，使用lambda表达式替换部分回调函数
* 9.优化StatusBar充电动画
* 10.DataCenter添加注释
* 11.PageManager添加注释
* 12.lv_allocater添加遗漏的运算符重载
* 13.添加Utils/Stream，来自Arduino
* 14.转移CommmonMacro.h到HAL，去除Basic文件夹

## [v1.1] - 2021-7-7
* 1.支持在GPX中记录海拔和时间，可在GPXSee查看爬升和速度统计
* 2.更新Startup页面，使用匿名函数回调
* 3.更新SystemInfos页面，添加Author署名和Build时间，电池状态 State -> Status
* 4.更新lvgl
* 5.更新GPX生成库，添加遗漏的time_成员
* 6.尝试将lvgl部分函数放在RAM中执行，但是执行速度提升不明显

## [v1.2] - 2021-7-11
* 1.添加StackInfo库，支持在裸机环境下测量栈使用情况
* 2.Stack_Size 0x2500 -> 0x1000
* 3.更新DP_Storage数据储存节点，支持拉取储存器使用情况
* 4.更新Config.h，添加显示器分辨率和缓冲区配置
* 5.添加触控逻辑
* 6.修复StatusBar充电动画闪烁的BUG，添加SD卡图标
* 7.SystemInfos页面添加SD卡状态监测显示

## [v1.3] - 2021-7-18
* 1.Config.h添加传感器使能配置选项
* 2.DataCenter添加cache自动初始化置0
* 3.添加Microsoft官方TileSystem解析库，供mapConv调用

## [v1.4] - 2021-7-24
* 1.更新lvgl
* 2.更新MapConv，统一使用GPS_Transform校准坐标
* 3.更新HAL::GPS模拟，支持航向和速度模拟
* 4.修改HAL::GPS_Info_t的 compass -> course
* 5.使用合入lvgl主线的lv_anim_timeline，使用lv_anim_timeline_wrapper封装动画组
* 6.更新Startup页面，新的开机动画
* 7.LV_IMG_CACHE_DEF_SIZE设置为0

## [v1.5] - 2021-8-1
* 1.lvgl更新
* 2.调整Stack size: 0x1500 -> 0x2000，处理更大的JSON文件
* 3.更新Storage节点，支持获取SD卡容量，支持自动获取地图缩放等级(OSM)
* 4.优化GPS节点，减少在GPS信号不稳定时频繁的提示音
* 5.优化SportStatus节点，支持在JSON文件中配置体重
* 6.优化SysConfig节点，支持在JSON配置默认经纬度，地图源(Bing/OSM)，soundDisable -> soundEnable
* 7.重构MapConv地图坐标转换器，支持动态配置地图源，地图坐标数据类型uint32_t -> int32_t，合并TileSystem和GPS_Transform
* 8.HAL添加SD_GetCardSizeMB()
* 9.更新Config.h，转移部分配置选项到JSON
* 10.更新Dialplate页面，卡路里单位cal -> k，优化编码器交互wrap = false
* 11.更新LiveMap页面，优化level自适应显示，使用SysConfig配置的默认位置
* 12.更新SystemInfos页面，支持显示SD卡容量
* 13.修复lv_fs_sdfat错误的指针类型转换，优化目录读取接口
* 14.lvgl内存池 64K -> 72K
* 15.WString使用lvgl的内存池
* 16.修复GPX轨迹文件<\ele>丢失问题(可能是内存碎片和heap过小导致WString realloc失败)

## [v1.6] - 2021-8-7
* 1.更新ArtDesign，新的导航箭头设计
* 2.更新lv_drivers，去除坐标超界警告
* 3.去除lv_examples，减少工程体积
* 4.调整模拟器的LV_FS_PC_PATH定义，指定到Software所在目录，方便读取地图
* 5.开机页面重命名: StartUp -> Startup
* 6.更新DP_SysConfig，mapSource -> mapDirPath指定地图目录，添加 WGS84/GCJ02 坐标系统切换，添加arrowTheme导航箭头主题切换
* 7.更新DP_Storage，适配新的MapConv，支持所有地图源缩放level范围自适应
* 8.更新DP_TrackFilter，适配新的MapConv
* 9.HAL添加Backlight_ForceLit()，支持强制点亮屏幕背光
* 10.更新模拟器的HAL_GPS，支持获取GPX点之间的时间差
* 11.更新Config.h，去除旧的Bing地图配置
* 12.更新LiveMap页面，支持修改导航箭头主题
* 13.更新GPX_Parser，添加海拔和时间解析
* 14.重构MapConv，废弃旧的Bing地图存放格式和地图下载器。使用[Crimson/地图下载器](https://gitee.com/CrimsonHu/java_map_download/)下载地图，文件存放格式为`/z/x/y.bin`
* 15.更新DisplayFault，在进入HardFault状态时强制点亮背光
* 16.更新HAL_Power，优化电压显示

## [v1.7] - 2021-9-3
* 1.调整Heap_Size 0x00002000 -> 0x00000200
* 2.调整lvgl内存池大小，LV_MEM_SIZE 72K -> 80K
* 3.更新lv_drivers
* 4.更新lvgl
* 5.DataCenter使用lvgl内存池
* 6.使用std::abs()替代宏实现的ABS()
* 7.更新DP_Storage
* 8.更新DP_SysConfig，调整结构体成员，添加timeZone和mapExtName，在关机时保存位置
* 9.更新DP_TrackFilter，使用地图上的Point格式替代旧的经纬度
* 10.更新DP_TzConv，GMT_OffsetHours -> sysCfg.timeZone
* 11.更新HAL.h，添加Memory_DumpInfo()堆栈使用统计
* 12.更新HAL_GPS模拟，修复diffTime = 0导致的gpsInfo.speed = inf
* 13.更新Config.h，添加LiveMap的Debug模式配置，PNG解码库使能配置等。转移Hardware Configuration至HAL_Config.h
* 14.更新Dialplate页面，使用lv_group_get_default()获取统一的group
* 15.重构LiveMap页面，添加LiveMap的Debug模式，使用lv_group_get_default()获取统一的group，适配新的轨迹过滤算法
* 16.更新StartUp页面，关闭LOGO滚动
* 17.更新SystemInfos，使用lv_group_get_default()获取统一的group
* 18.更新DataCenter，统一使用lv_allocator分配内存
* 19.添加lv_lib_png，限于内存大小暂不使用
* 20.添加lv_monkey，实现简单压力测试
* 21.添加lv_multi_line，实现轨迹的多段线绘制，提升lv_line复用率，极大节省内存
* 22.更新MapConv，支持自定义文件扩展名，添加ConvertMapPos实现不同level间的坐标换算
* 23.更新TileSystem，使用namespace替换class，免去无意义的实例化
* 24.添加new、delete重载，统一使用lvgl内存池
* 25.扩展StorageService的内存，JSON_BUFFER_SIZE 1024->2048
* 26.更新TrackFilter，修复二级滤波拐点丢失问题。使用TrackLineFilter实现可视区轨迹裁剪，节省内存，提升绘制效率。
* 27.更新lv_fs_sdfat接口，使用new和delete替换lv_mem_alloc和lv_mem_free
* 28.更新lv_port_indev，去除lv_port_indev_get()，创建全局默认group
* 29.添加HAL::Memory_DumpInfo()，由于要使用__heapstats()读取heap信息，关闭microlib
* 30.添加rt_sys.cpp，实现一些C底层接口
* 31.读取StackInfo从main.cpp转移至HAL::Memory_DumpInfo()

## [v1.8] - 2021-9-14
* 1.StackInfo库 StackInfo_GetSize -> StackInfo_GetTotalSize
* 2.移除多余的RTE/Device
* 3.Common/HAL模拟器实现转移到Simulator\LVGL.Simulator\HAL
* 4.VS模拟器HAL_GPS适配新的GPX_Parser
* 5.更新lv_conf.h LV_CIRCLE_CACHE_SIZE 8 -> 32
* 6.更新lv_fs_pc，去除无用代码
* 7.更新LVGL.Simulator，lv_png_init和lv_monkey_create转移至App_Init初始化
* 8.更新lvgl主程序
* 9.更新App初始化，调整Storage和SysConfig的初始化顺序，修复错误的全屏滑动
* 10.更新DataProc初始化，center实例化转移到函数外部，DP_DEF宏全大写
* 11.更新DataProc声明，ConvTime -> MakeTimeString，去除IMU_Commit和MAG_Commit
* 12.更新Storage_Basic_Info_t，添加type成员，支持获取SD卡类型
* 13.更新DP_Clock，ConvTime -> MakeTimeString
* 14.更新DP_IMU，去除IMU_Commit机制，使用回调进行数据提交
* 15.更新DP_MAG，同上
* 16.更新DP_Recorder，合并变量至Recorder_t结构体，添加RECORDER_GPX宏配置
* 17.更新DP_Storage，适配新的StorageService，添加SD卡类型获取
* 18.更新DP_TrackFilter，PointVector_t不再使用lv_allocator
* 19.更新HAL，添加Display和FaultHandle抽象层，以及IMU和MAG的CommitCallback，获取SD卡类型的函数
* 20.去除lv_allocator依赖，统一使用重载的new和delete进行分配
* 21.更新SystemInfos页面，SD卡状态指示 "Detect" -> "Status"，支持显示SD卡类型，在Sensor Config未开启时数据全部置0
* 22.调整ResourcePool的Font Default设置
* 23.ArduinoJson库的DynamicJsonDocument使用lvgl内存池分配内存
* 24.更新DataCenter/Account，"Push" -> "Publish"
* 25.更新DataCenter和PageManager的LOG写法
* 26.更新GPX_Parser，添加错误码
* 27.lv_lib_png使用lvgl内存池分配内存
* 28.更新lv_monkey，添加新的配置选项
* 29.更新MapConv，ConvertMapPos -> ConvertMapLevelPos
* 30.在VS模拟器上对new/delete进行重载，但是由于ASAN导致重定义冲突，只在Release下重载
* 31.更新PageManager，解决lv_anim_exec_xcb_t回调的lv_coord_t和int32_t混用问题，修复LOAD_ANIM_NONE页面切换的BUG
* 32.更新StorageService，支持静态和动态内存分配切换
* 33.去除USER/Display，转移至HAL层
* 34.优化lv_port，使用统一的初始化函数，与硬件驱动解耦，lv_fs_sdfat -> lv_port_fs_sdfat
* 35.修复HAL_Buzz静音模式下的错误开机音
* 36.更新HAL_Config，支持GPS缓冲区过载检测，支持配置Power的开关机延时时间
* 37.更新HAL_Power，合并变量到Power_t
* 38.更新HAL_SD_CARD，支持获取SD卡类型，SD_CardSizeMB -> SD_CardSize

## [v1.9] - 2021-10-1
* 1.修复ArduinoAPI中未初始化变量
* 2.去除lv_fs_pc中未使用的函数
* 3.去除unistd.h
* 4.更新lvgl主程序
* 5.Resource管理器，Resource. -> ResourcePool::
* 6.添加Utils/PointContainer组件
* 7.DP_Storage添加地图缩放级别错误检查
* 8.DP_TackFilter添加PointContainer组件适配，减少75%内存占用，极大提升轨迹录制容量
* 9.多段线组件lv_multi_line -> lv_poly_line
* 10.更新ArduinoJson
* 11.Display_DumpCrashInfo report -> info
* 12.更新HAL_Power，不使用ADC中断模式

## [v2.0] - 2021-11-14
* 1.Arduino API底层重构
* 2.添加MillisTaskManager任务调度器
* 3.lvgl使用标准memset和memcpy
* 4.更新lvgl v8.1.0
* 5.DataCenter错误码枚举 ERROR_XXX -> RES_XXX
* 6.修改DP节点的结构体初始化方式，不使用默认初始化
* 7.优化DP_SportStatus在临时信号丢时的数据统计处理
* 8.修复StorageService文件结尾读取错误导致的crash
* 9.添加lv_settings，暂未移植
* 10.添加传感器自动扫描，防止未安装传感器导致的开机卡死
* 11.使用event携带user_data
* 12.优化new重载
* 13.修复HAL_Power错误的关机处理
* 14.添加SystemSave.json自动备份功能

## [v2.1] - 2021-12-16
* 1.ArduinoAPI更新
* 2.将LVGL部分绘图函数放到RAM执行，提升运行效率，不删除.sct文件
* 3.Adafruit_ST778驱动更新，适配新的SPI库
* 4.更新lvgl v8.1.1 dev
* 5.lv_conf.h更新，使用新的缩进
* 6.lv_monkey合入LVGL主线
* 7.去除LiveMap进入时的透明度渐变动画，提升流畅度
* 8.更新HAL_Power，充电检测上下拉可选
* 9.优化IMU和MAG初始化

## [v2.2] - 2021-12-30
* 1.添加系统软件架构说明
* 2.去除弃用的_LIS3MDL
* 3.修复使用strncpy()遗漏的'\0'结束符
* 4.添加AT32F435移植
* 5.LV_DISP_DEF_REFR_PERIOD 20ms -> 16ms
* 6.LV_MEM_SIZE 78KB -> 70KB
* 7.默认开启PNG解码器，受限于内存MCU无法使用
* 8.添加轨迹记录状态指示渐变动画
* 9.添加文本动画组件lv_anim_label，替换旧的lv_label_anim_effect
* 10.去除lv_settings

## [v2.3] - 2022-1-30
* 1.Arduino API 更新
* 2.添加wdg看门狗，系统卡死时自动重启
* 3.lvgl主程序更新
* 4.添加低内存开销(<50KB)的PNGdec解码器（暂不启用）
* 5.更新LiveMap，适配新的PNGdec
* 6.更新StatusBar，调整字体，新的轨迹记录状态指示渐变动画
* 7.ResourceManager从PageManager分离
* 8.lv_anim_label组件从lv_ext分离
* 9.添加lv_img_png组件

## [v2.4] - 2022-2-27
* 1.添加指定的Pack
* 2.AT32F435 Pack更新 2.0.0 -> 2.0.6
* 3.__wfi() -> __WFI()
* 4.移除lv_demo_conf.h
* 5.更新lvgl v8.3.0 dev
* 6.AT32F403A Stack size 0x2000 -> 0x1000

## [v2.5] - 2022-3-18
* 1.更新Adafruit_ST7789，支持颜色大小端切换
* 2.更新CommonMacro库
* 3.更新lv_conf.h
* 4.去除lv_lib_png，使用lvgl内置PNG库
* 5.DataProc 添加 DATA_PROC_INIT_STRUCT() 结构体初始化
* 6.StatusBar 统一走 DataCenter 通信，只保留初始化API
* 7.规范 DataProc 的 onEvent 回调函数的返回值
* 8.去除 Page.h 公共空间的 ARRAY_SIZE() 宏定义
* 9.ResourcePool::Font 默认返回 LV_FONT_DEFAULT，关闭不必要的内置字体
* 10.更新PageManager，lv_event_get_target() -> lv_event_get_current_target()

## [v2.6] - 2022-4-10
* 1.ArduinoAPI更新
* 2.整理 Core，统一移动到 MDK-ARM_F4XX/Platform 中
* 3.更新lvgl主程序
* 4.LV_SPRINTF_CUSTOM使能，减少FLASH占用
* 5.account->Pull()操作全部添加返回值检查
* 6.PageManager更新
* 7.页面Template添加生命周期LOG
* 8.DataCenter添加ACCOUNT_DISCARD_READ_DATA
* 9.__WFI() -> __wfi()
* 10.main.cpp复用
* 11.修复[TscanCode](https://github.com/Tencent/TscanCode)静态扫描出来的漏洞
* 12.添加Linux移植

## [v2.7] - 2022-6-3
* 1.Adafruit_ST7789: 添加多分辨率支持; 去除drawRGBBitmap(); 删除Adafruit_ST7789V2
* 2.AT32F403A: 更新Platform; 更新链接脚本，将lv_tlsf和font_bahnschrift_13载入RAM提升访问性能
* 3.AT32F435: 更新Platform
* 4.lv_conf.h: 同步主线配置; 使能LV_COLOR_SCREEN_TRANSP; WIN平台 GetTickCount() -> timeGetTime()
* 5.lvgl: 同步 commit 941d95b0491a1e78fadeeb5ea8aa552f82669336
* 6.App.cpp: 自动创建未设置的默认group; 设置scr的透明度和颜色; 添加rootStyle
* 7.PageManager: 添加PageBase.cpp; 规范成员变量命名; 添加Replace()方法; 支持设置RootDefaultStyle; 修复PM_Drag不生效
* 8.Pages/_Tempalte: 添加LOG输出
* 9.Pages/Dialplate: 同步PageManager更新
* 10.Pages/LiveMap: 同步PageManager更新
* 11.Pages/Startup: 同步PageManager更新; 使用Replace()方法替换Push()方法，支持BackHome()
* 12.Pages/SystemInfos: 同步PageManager更新; 优化item自动添加AttachEvent()
* 13.ResourcePool: 移除无用的gps_pin图片
* 14.lv_anim_label: lv_anim_label_set_text() -> lv_anim_label_push_text()
* 15.lv_img_png: 添加多色深支持
* 16.USER: 添加benchmark.inc，方便测试lvgl以及对比性能

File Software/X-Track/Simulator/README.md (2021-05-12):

# LVGL - PC Simulator using Visual Studio

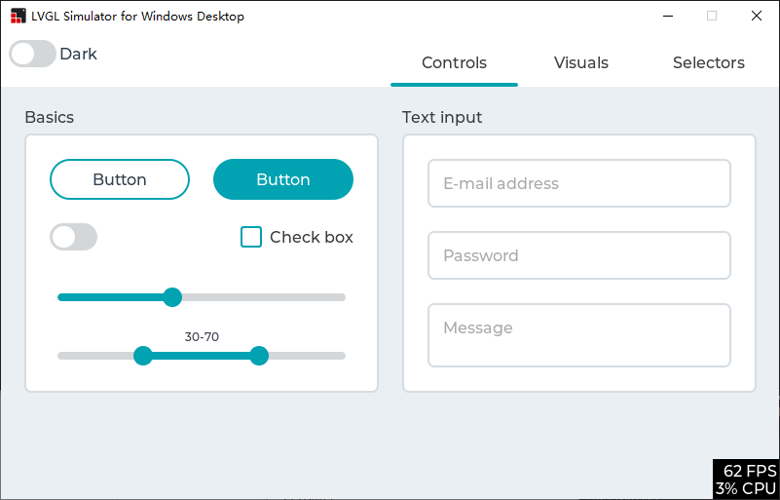
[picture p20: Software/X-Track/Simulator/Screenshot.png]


## Introduction

This is a pre-configured Visual Studio project to try LVGL on a Windows PC. The
project only depend on Win32 API, C Runtime and C++ STL, so you can compile it
without any extra dependencies.

The project is currently maintained using Visual Studio 2019. It may well work
without modification in Visual Studio 2017 but it is not actively supported 
with that version, so please install and test with Visual Studio 2019 before 
reporting any bugs.

Some one will notice that this repository had been renamed from 
`lv_sim_visual_studio_sdl` to `lv_sim_visual_studio`. You can read 
[here](https://github.com/lvgl/lvgl/issues/2043) and know why.

**This project is not for Visual Studio Code, it is for Visual Studio 2019.**

Instructions for cloning, building and running the application are found below.

## Supported Features

This repo is designed for keeping the simulator behavior. If you wonder to 
adapt your LVGL application to Windows, please visit 
[lvgl/lv_port_windows](https://github.com/lvgl/lv_port_windows).

- [x] Only depends on Win32 API, C Runtime and C++ STL.
- [x] Native support for x86, x64, ARM and ARM64 Windows.
- [x] Support compiling with [VC-LTL](https://github.com/Chuyu-Team/VC-LTL) 
      toolchain to make the binary size as smaller as using MinGW.
- [x] Support Per-monitor DPI Aware.
- [x] Support Windows keyboard and mouse wheel event in the HAL level.

## How to Clone

This repository contains other, necessary LVGL software repositories as 
[git submodules](https://git-scm.com/book/en/v2/Git-Tools-Submodules). Those 
submodules are not pulled in with the normal git clone command and they will be
needed. There are a couple of techniques to pull in the submodules.

### Everything at Once

This command will clone the lv_sim_visual_studio repository and all submodules
in a single step.

```
git clone --recurse-submodules https://github.com/lvgl/lv_sim_visual_studio.git
```

### Main Repository First, Submodules Second

If you've already cloned the main repository you can pull in the submodules 
with a second command. Both commands are shown below.

```
git clone https://github.com/lvgl/lv_sim_visual_studio.git
cd lv_sim_visual_studio
git submodule update --init --recursive
```

### Keeping Your Clone Up-To-Date

If you have cloned this repository and would like to pull in the latest 
changes, you will have to do this in two steps. The first step will pull in
updates to the main repo, including updated _references_ to the submodules. The
second step will update the code in the submodules to match those references.
The two commands needed to accomplish this are shown below, run these commands
from inside the main repository's directory (top level `lv_sim_visual_studio`
directory works fine).

```
git pull
git submodule update --init --recursive
```

If you have chosen to fork this repository then updating the fork from upstream
will require a different, more involved procedure.

## How To Build & Run

Open the `LVGL.Simulator.sln` solution file in Visual Studio. Set the 
`LVGL.Simulator` project as the startup project. Click on the `Local Windows
Debugger` button in the top toolbar.  The included project will be built and 
run, launching from a cmd window.

## Trying Things Out

There are a list of possible test applications in the 
[LVGL.Simulator.cpp](LVGL.Simulator/LVGL.Simulator.cpp) file. Each test or demo
is launched via a single function call.  By default the `lv_demo_widgets` 
function is the one that runs, but you can comment that one out and choose any
of the others to compile and run.

Use these examples to start building your own application test code inside the
simulator.

## A Note About Versions

This repository has its submodule references updated shortly afk with minor 
version updates. When submodule updates take place a matching version tag is
added tter the release of new, major releases of LittlevGL's core 
[lvgl](https://github.com/lvgl/lvgl) project. Occasionally it is updated to
woro this repository.

If you need to pull in bug fixes in more recent changes to the submodules you
will have to update the references on your own. If source files are added or
removed in the submodules then the visual studio project will likely need
adjusting. See the commit log for examples of submodule updates and associated
visual studio file changes to guide you.

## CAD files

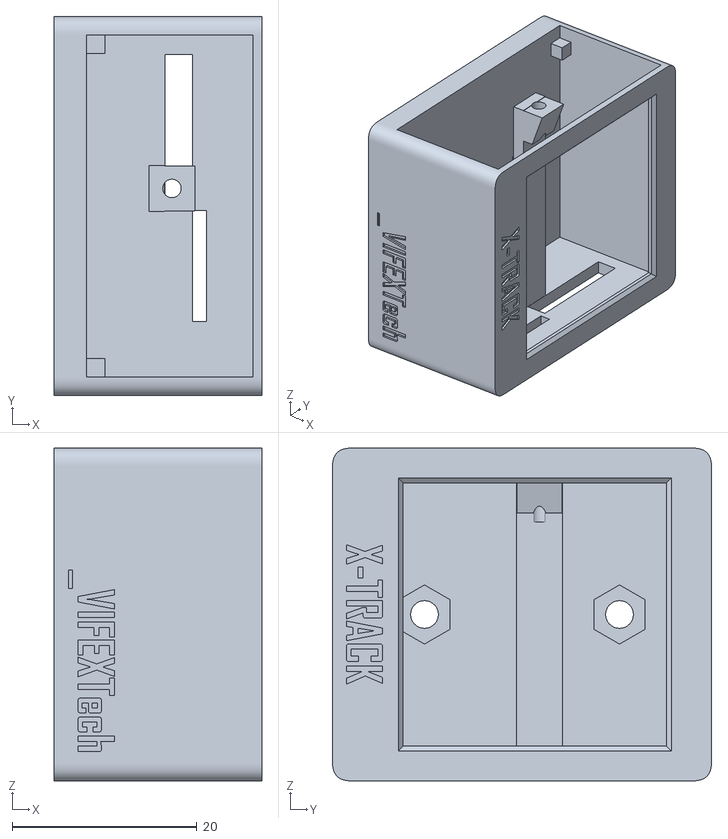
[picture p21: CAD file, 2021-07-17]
3D Model/外壳-主体.STL
22.5 x 41.0 x 36.0

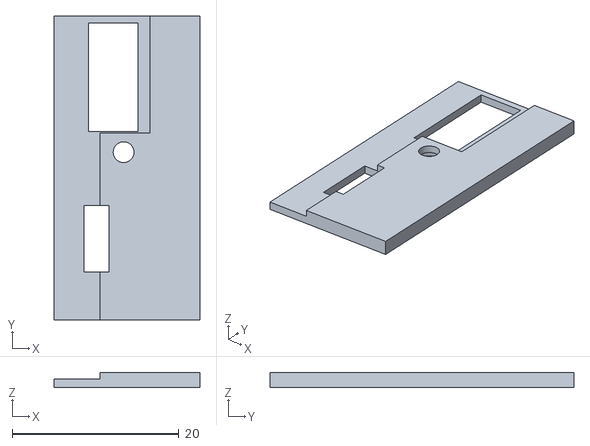
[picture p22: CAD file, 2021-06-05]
3D Model/外壳-侧盖.STL
17.5 x 36.5 x 1.80

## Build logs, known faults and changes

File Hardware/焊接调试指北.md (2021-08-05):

# 焊接调试指北
<!-- vscode-markdown-toc -->
* [1. 背景](#bg)
* [2. 准备工作](#prepare)
    * [2.1 物料&装备](#materials)
    * [2.2 焊接调试顺序](#rank)
* [3. 焊接与调试](#paste)
    * [3.1 CH340 & USB  **锡膏焊接**](#ch340)
    * [3.2 电源管理芯片 **锡丝焊接**](#chg)
    * [3.3 稳压芯片 & 开关控制](#lpo)
    * [3.4 MCU拖焊 **拖焊**](#mcu)
    * [3.5 编码器 & 蜂鸣器](#encoder)
    * [3.6 SD卡槽](#sd)
    * [3.7 屏幕](#lcd)
    * [3.8 GPS](#gps)
* [4. 整体测试](#debug)

<!-- /vscode-markdown-toc -->

## <a name="bg"> 1. 背景

骑行爱好者，略懂电子学的东西，加了一个DIY的群，发现很多老哥没有焊接的经验，焊接完之后也没有思路去debug，故写下这篇指北，希望能给新人提供一些帮助，也希望大家能够通过这个项目感受到电子制作的乐趣。

## <a name="prepare"> 2. 准备工作

### <a name="materials"> 2.1 物料&装备

首先大家需要按照[BOM表](./X-Track.pdf)去采购相应的物料，对于一些便宜的元件（MOSFET 阻容 二极管等）可以多买一些，另外USB串口芯片（CH340）、电源管理芯片（MCP73831）、线性稳压芯片（LP5907-3.3）相对难焊接，但是价格又不贵，如果你是新手可以多买一些这三个芯片作为练习，（毕竟JLC打板会有5片）。

工具的准备：  

- 烙铁刀头
- 烙铁尖头（可选）
- 细焊锡丝、助焊剂（松香）
- 锡膏（可选）
- 风枪（最好有）
- 芯片镊子
- 万用表（调试的最基本仪器了，配置尖头表笔，如果连万用表都没有真的不好调试）
- 可调直流电源（非必须）
- 导线
附上工具图片  
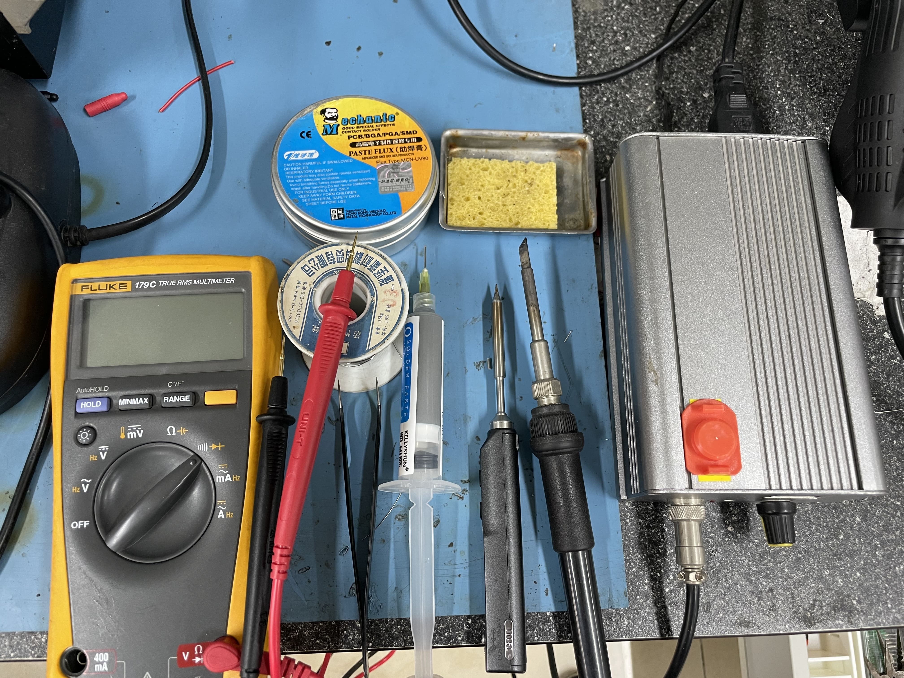
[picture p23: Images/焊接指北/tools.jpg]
我的工具


### <a name="rank"> 2.2 焊接调试顺序

在这里我首先假定大家是没有可调电源的，所以我计划首先焊接USB及CH340以及供电相关的芯片，上面也提到了CH340对于新手来说比较难焊接，同时有比较便宜，建议大家先焊接几个练练手。  

之后是主控芯片，主控芯片焊接完成之后就可以用仿真器烧录程序来判断是否成功了。  

紧接着可以焊接蜂鸣器、编码器。

焊接SD卡

焊接外屏

## <a name="paste"> 3. 焊接与调试

### <a name="ch340"> 3.1 CH340 & USB

在这里我首先演示的是用锡膏+风枪的焊接方法，刀头烙铁拖焊在后面展示。如果没有锡膏和风枪，建议先翻到后面。

#### 3.1.1 焊接

1. 首先要给焊盘上锡膏，轻轻挤入少量，主要不要覆盖全部焊盘，不然后面放置芯片时无法对齐！  
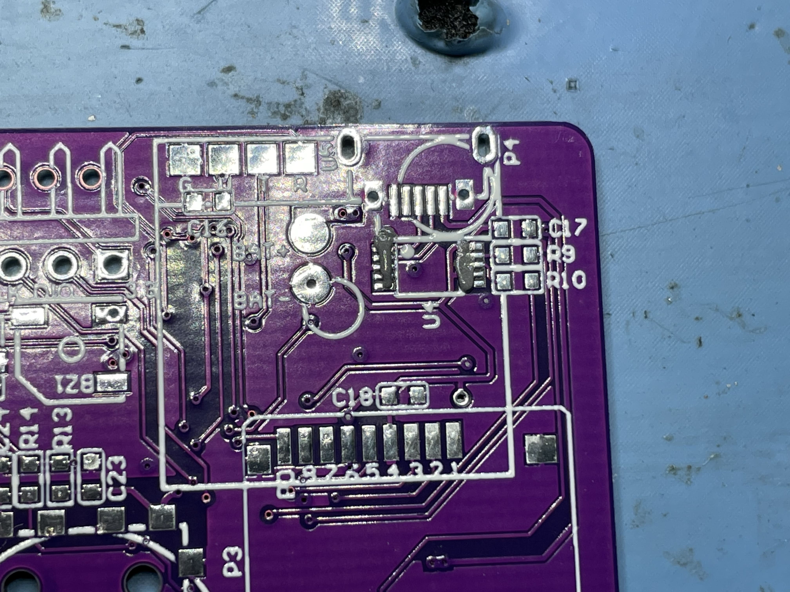
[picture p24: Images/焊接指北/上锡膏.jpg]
上锡膏


2. 放置芯片，注意芯片引脚要和焊盘平行对齐  
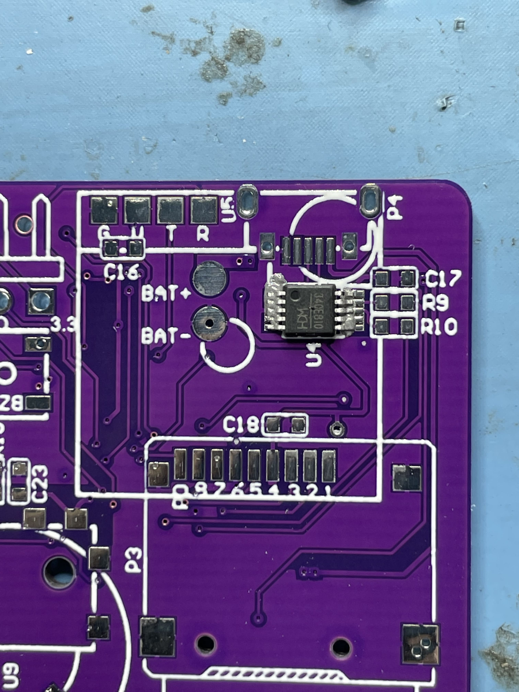
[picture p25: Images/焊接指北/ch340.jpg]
放芯片


3. 风枪加热，主要风枪风度调节在**310度**左右，均匀吹芯片的引脚，直到锡膏融化，变得有金属光泽，液态锡会因为表面张力自动“爬上”焊盘与芯片引脚。  
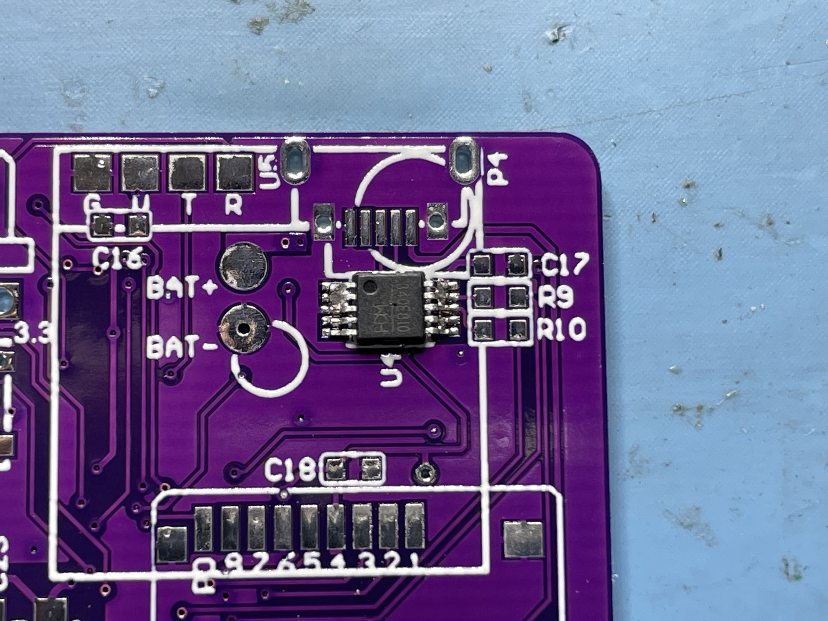
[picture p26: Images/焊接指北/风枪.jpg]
风枪


4. 如果你不小心放了过多的锡膏，会导致引脚短路，这时用刀头烙铁配合助焊剂，“刮”掉多余的锡，芯片周围的物质就是助焊剂的残留，最后可以用牙刷沾酒精刷掉。  
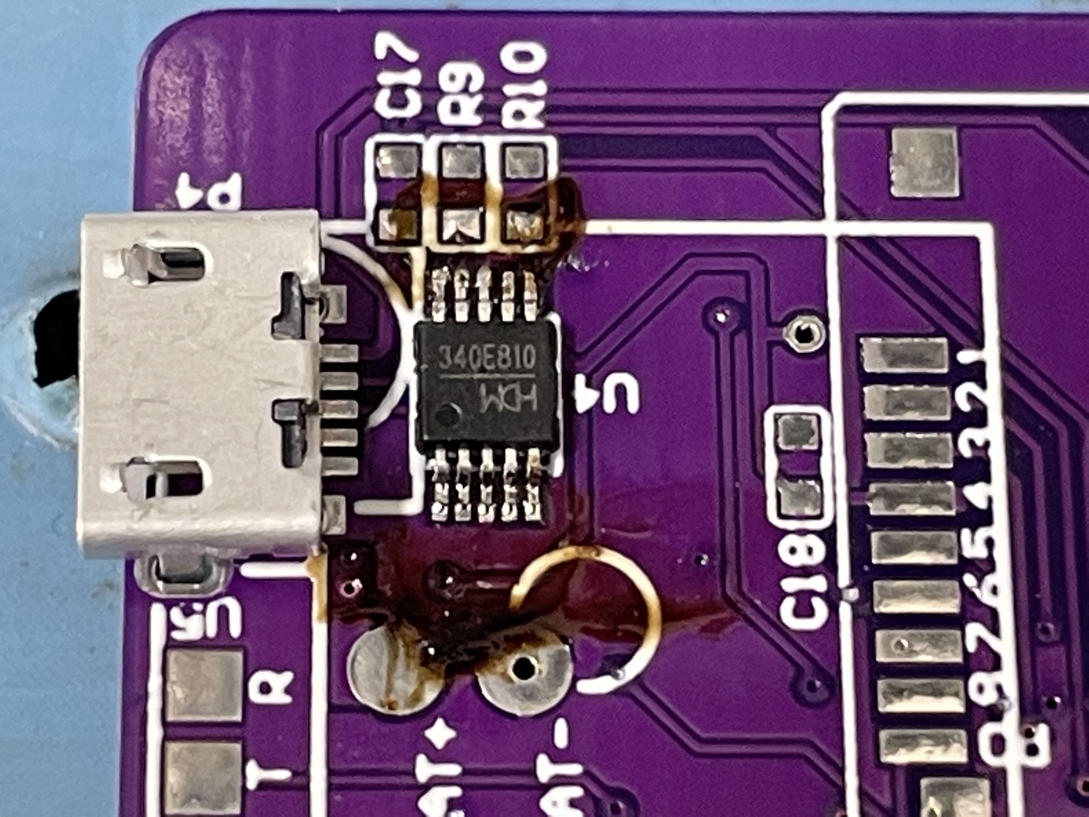
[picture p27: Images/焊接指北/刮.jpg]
刮锡


5. 同理焊接USB接口  
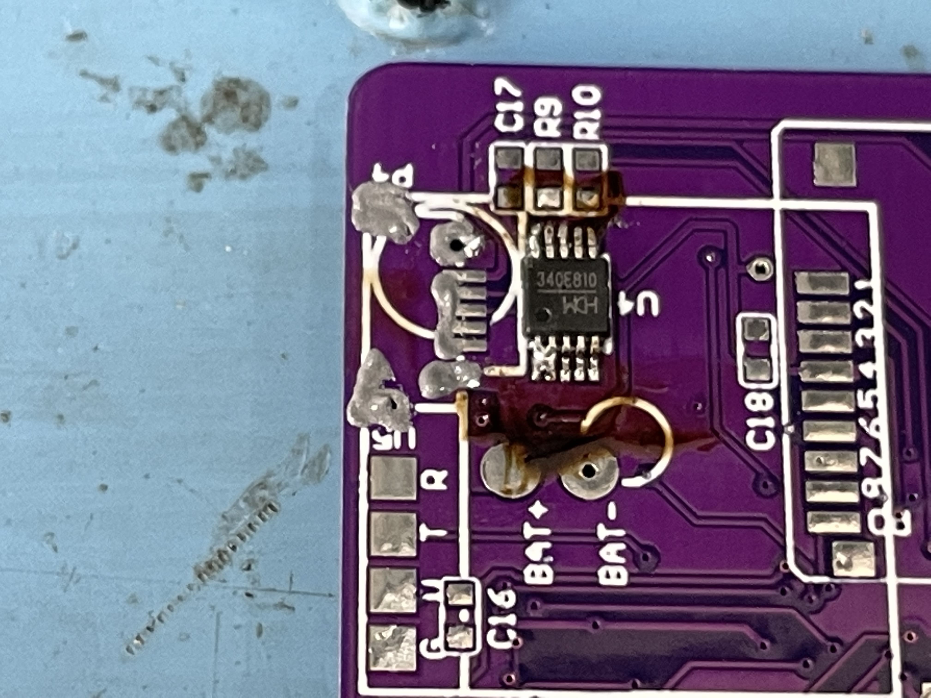
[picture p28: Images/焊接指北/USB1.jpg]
  
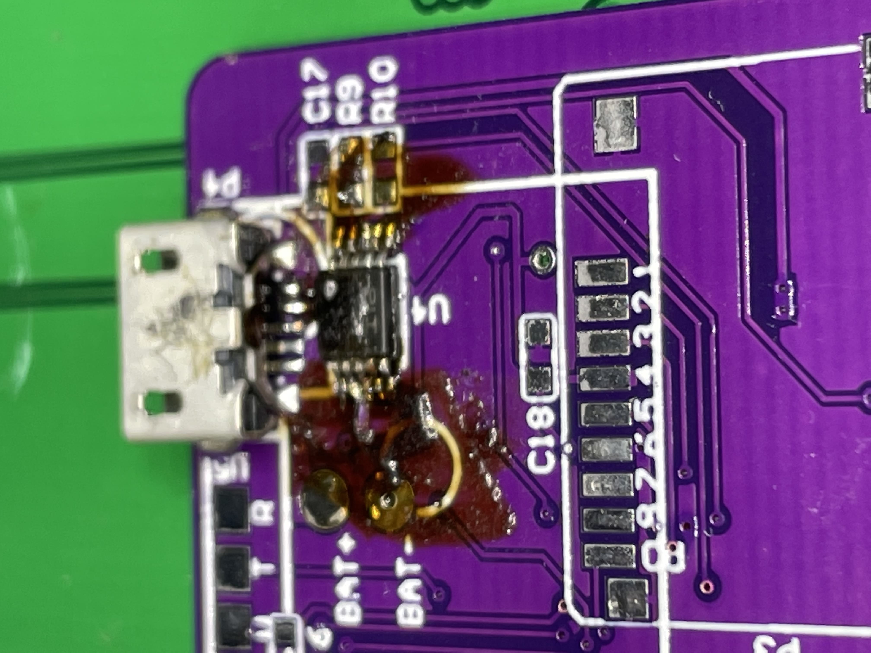
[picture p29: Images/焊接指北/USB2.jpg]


6. 清理助焊剂，用牙刷沾酒精（无水乙醇，如果是医用75%酒精效果不是很好，可能要多刷一会）刷一下，很容易就刷掉了  
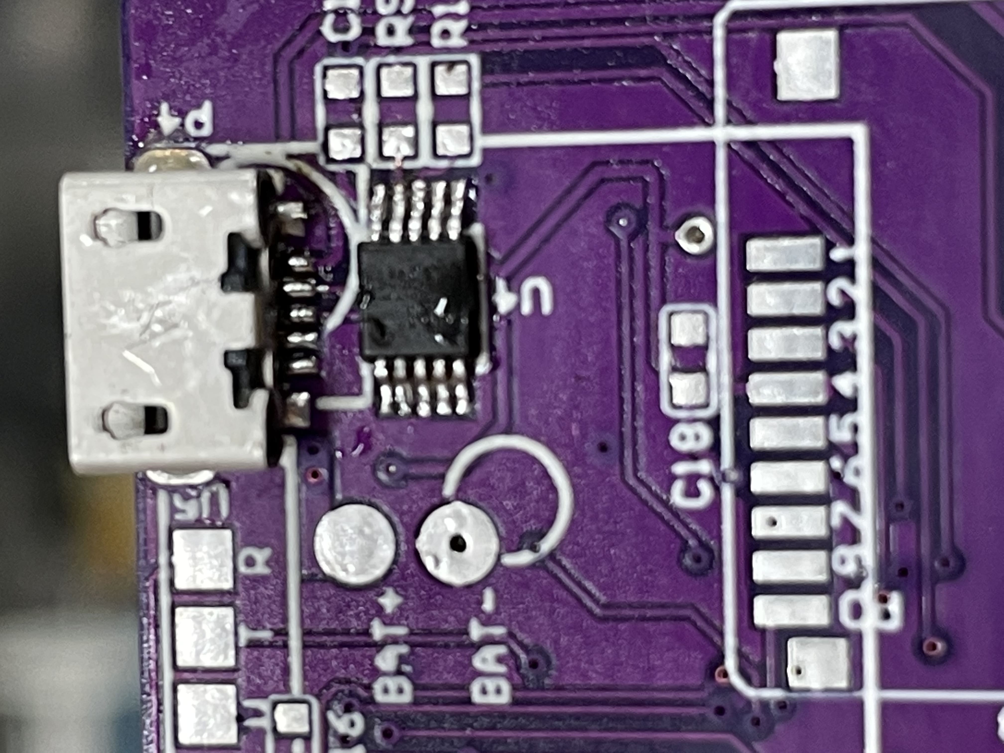
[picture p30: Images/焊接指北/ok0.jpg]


7. 把R9 R10 焊接上

#### 3.1.2 测试

根据原理图，发现CH340是由3V3供电，而不是USB，目前我们没有焊接稳压芯片，所以这里我们需要用调试器上的3.3V为芯片供电。  
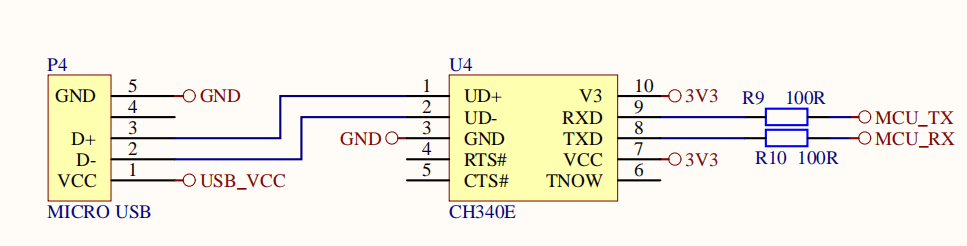
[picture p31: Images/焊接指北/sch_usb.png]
sch usb


我们使用杜邦线连接调试接口的3.3引脚（这里用手轻轻压住，因为是调试所以就不焊接了），并且用USB线连接电脑和板子，查看设备管理器是否出现了CH340 端口设备  
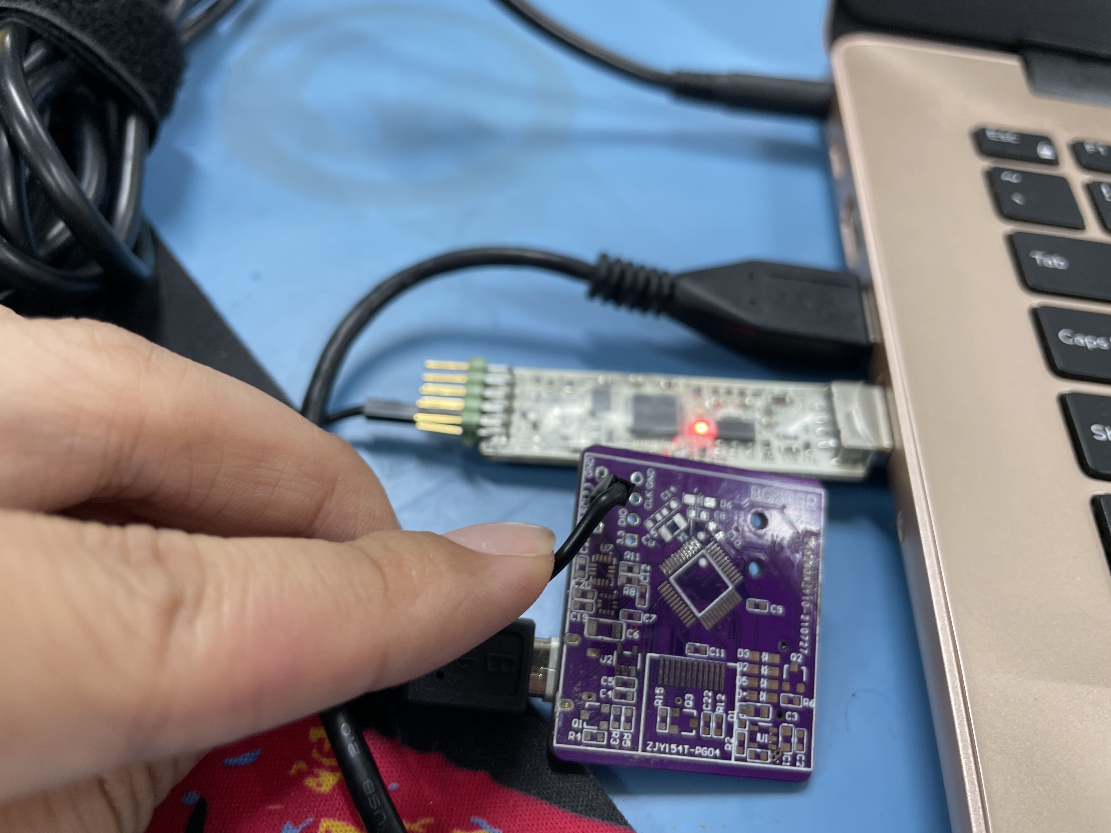
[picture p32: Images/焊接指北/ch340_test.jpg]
ch340 test
  
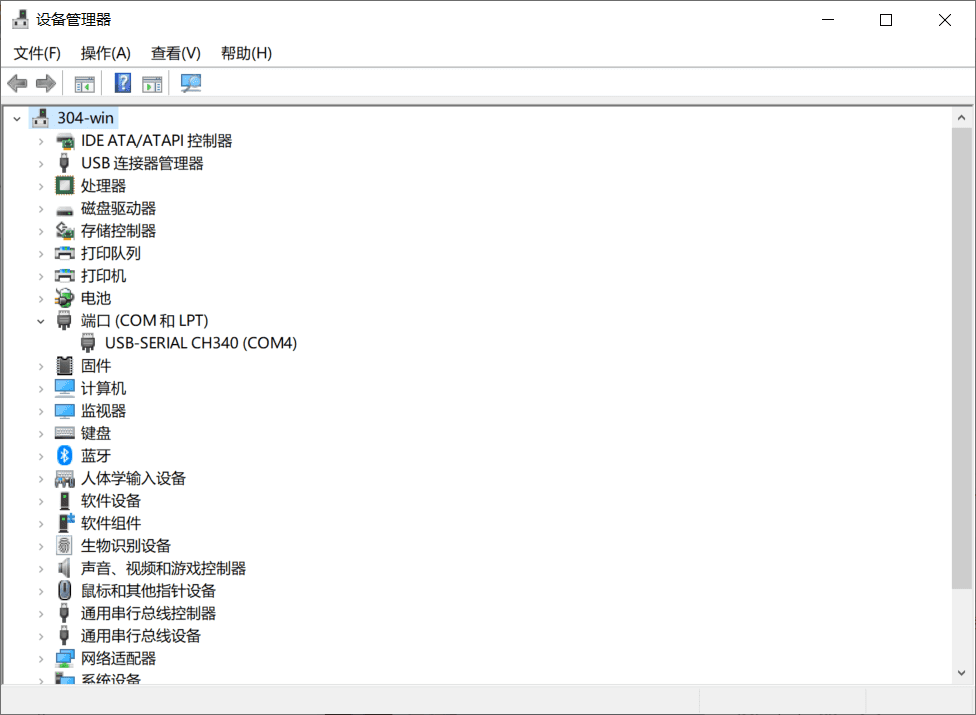
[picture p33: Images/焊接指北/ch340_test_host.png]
ch340 test host


**注意** 我USB线与STLink调试器连接了同一计算机的USB下，因此STLink到板子上没有接地线！如果你无法保证不同USB口是否共地，请额外连接一根GND线。

如果出现了USB未能识别该设备的提示，请检查USB接口的焊接是否把引脚短路！，如果CH340没有供电，是不会有任何提示的！请检查CH340的供电，并且检查USB D+ D-两个引脚到CH340的连通性，以及是否存在短路。

### <a name="chg"> 3.2 电源管理芯片

电源管理芯片用来管理对锂电池充电的，我们先焊接这个部分，然后就能测试电池充电是否正常了。原理图如下。  
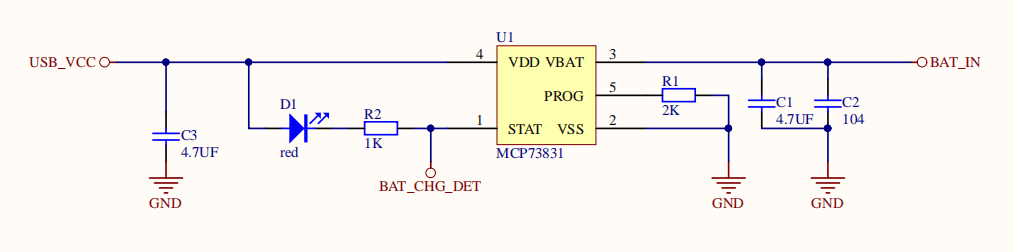
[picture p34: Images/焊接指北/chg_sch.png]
chg sch


#### 3.2.1 焊接

芯片的焊接方法

1. 向一个焊盘焊入少量的锡，保证覆盖整个焊盘  
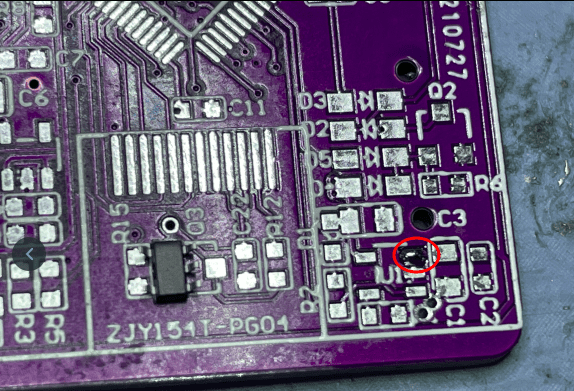
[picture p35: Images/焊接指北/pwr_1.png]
pwr_1


2. 加热上一步的焊盘，使焊锡融化，同时将芯片放入该焊盘，用镊子小心调整位置，使芯片与焊盘对齐  
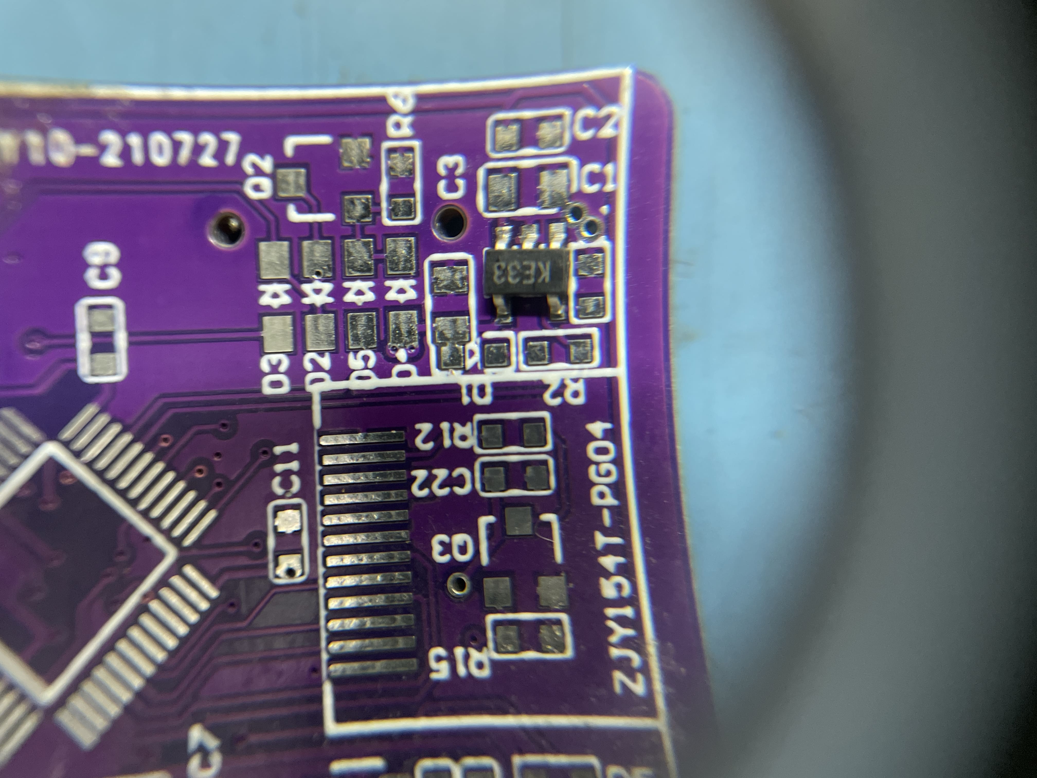
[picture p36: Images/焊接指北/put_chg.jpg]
put chg


3. 将其他引脚都焊入焊锡  
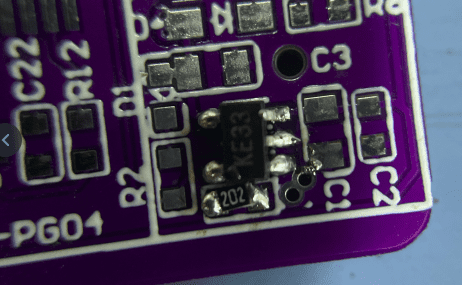
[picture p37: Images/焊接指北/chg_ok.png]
chg_ok


4. 焊接周围的元件  
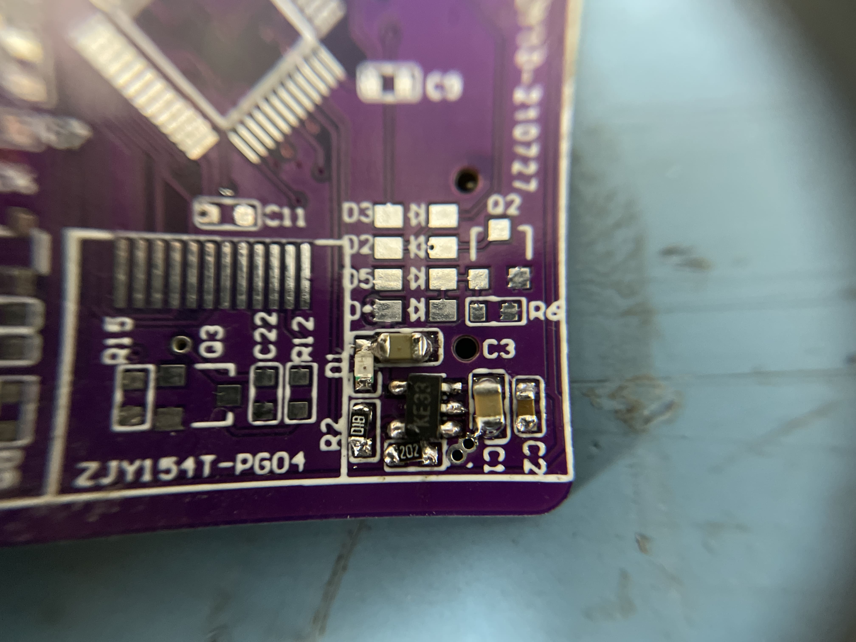
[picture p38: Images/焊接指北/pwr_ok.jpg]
pwr ok


（新手不要吐嘈我焊接水平差）

#### 3.2.2 测试

1. 插入USB线，用万用表测量C1的上端（远离PCB边缘一侧），查看电压是否为4.1V左右  
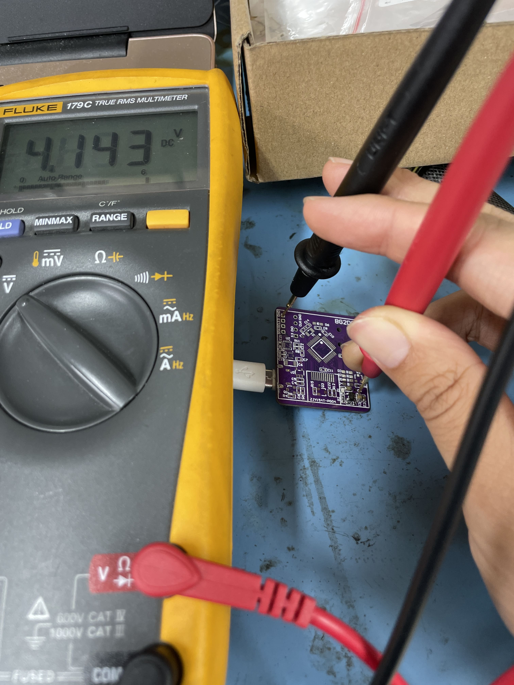
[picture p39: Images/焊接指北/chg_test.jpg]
chg test


2. 接入锂电池，观察充电指示灯是否亮起  
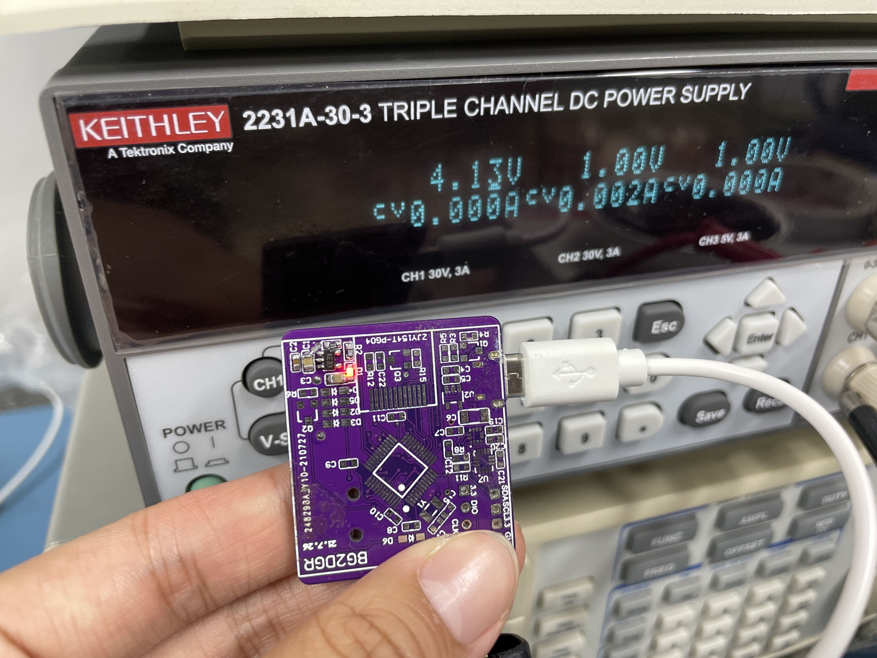
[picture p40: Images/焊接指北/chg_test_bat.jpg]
chg test
  
说明：如果有可调电源的小伙伴，可以把可调电源设置为3.7V，接入PCB背面的BAT+ BAT-，插入USB即可。（我这么做是因为没有多余的电池了）

3. **为了后续焊接的安全，拆掉锂电池**

### <a name="lpo"> 3.3 稳压芯片 & 开关控制

LP5907-3.3V是稳压芯片，作用是把电池的电压稳定到3.3V，以供板上其他芯片使用。其他的mosfet+二极管的组合，是用来实现电源控制的。其中我们要验证这部分电路是否工作正常，只需要给PWR_EN一个高电平信号，就可以导通Q1 与 Q2，实现BAT_IN到BAT的供电，再看U2一旦BAT导通到BAT_IN，芯片就会将电池的电压转换为3.3V。

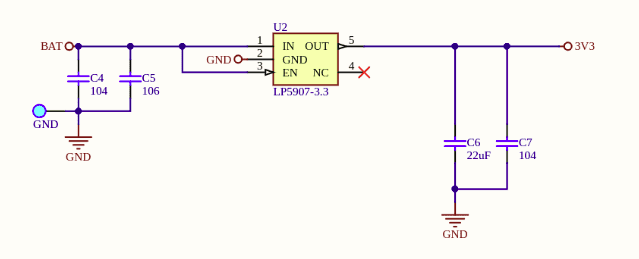
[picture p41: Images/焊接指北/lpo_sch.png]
lpo_sch

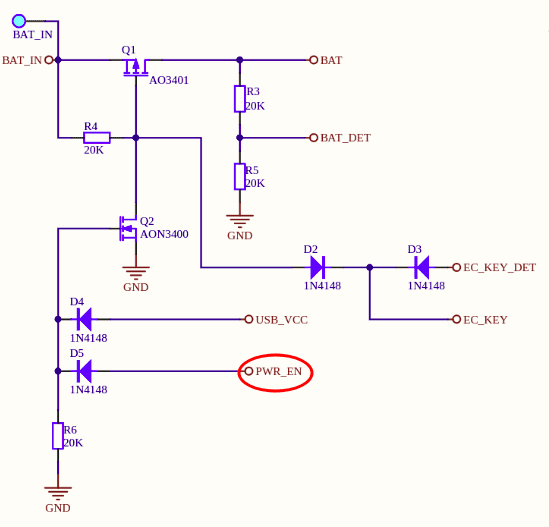
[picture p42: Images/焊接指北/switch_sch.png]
switch_sch


#### 3.3.1 焊接

这部分焊接的部分就不赘述了，下图中红色方框部分是稳压芯片，椭圆的二个红圈内为开关控制部分。  
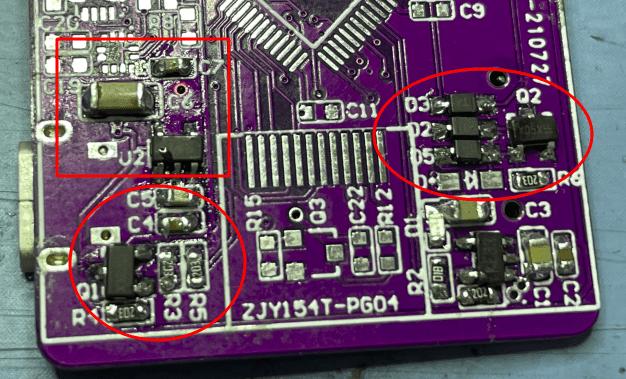
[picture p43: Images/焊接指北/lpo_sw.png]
lpo_sw


#### 3.3.2 测试

1. 接入电池
2. 利用调试器的3.3V输出引脚给D5正极（左侧）一个高电平信号，下图中，左下角的黑色杜邦线接到STLink的3.3V引脚，左上角GND要与STLink共地  
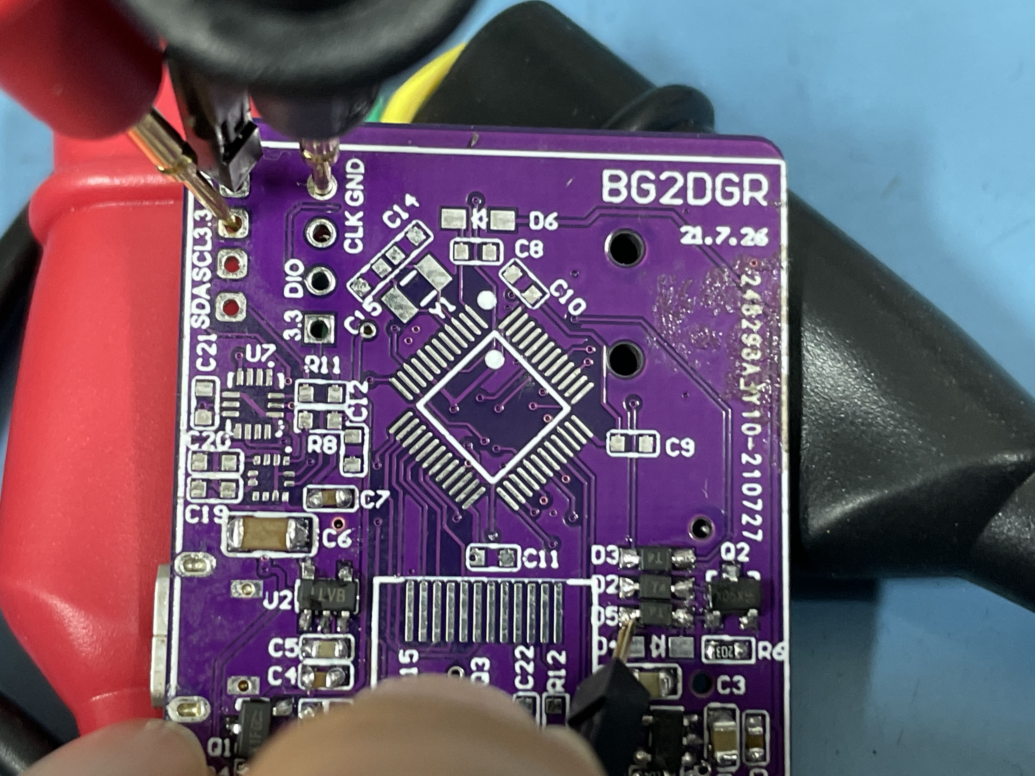
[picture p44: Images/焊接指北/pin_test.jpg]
lpo test


3. 用万用表测量板子左上角调试接口的3.3V，观察输出是否为3.3V，断开D5正极的高电平信号，观察万用表测量结果是否归零  
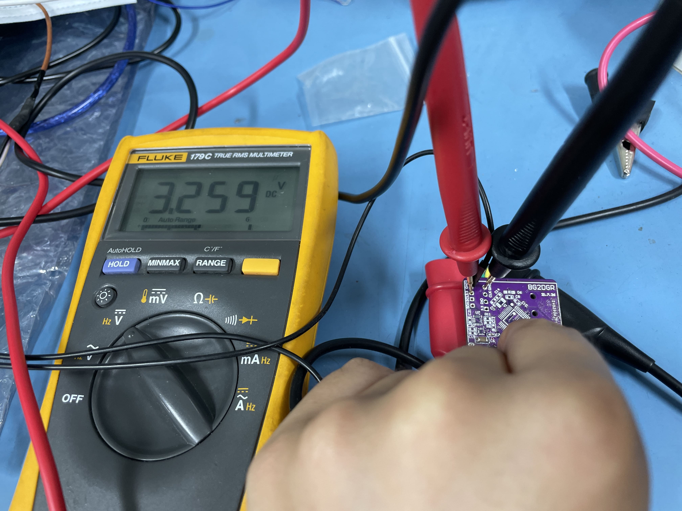
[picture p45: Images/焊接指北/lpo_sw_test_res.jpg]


4. 为了后续焊接的安全，拆掉锂电池

### <a name="mcu"> 3.4 MCU拖焊

当然如果你有锡膏和风枪，可以按照ch340的焊接方法焊接。但是对于类似LQFP这类引脚露出，紧密排列的用刀头烙铁拖焊也是不错的选择。

#### 3.4.1 芯片拖焊方法
1. 首先个一个焊盘上合适的锡  
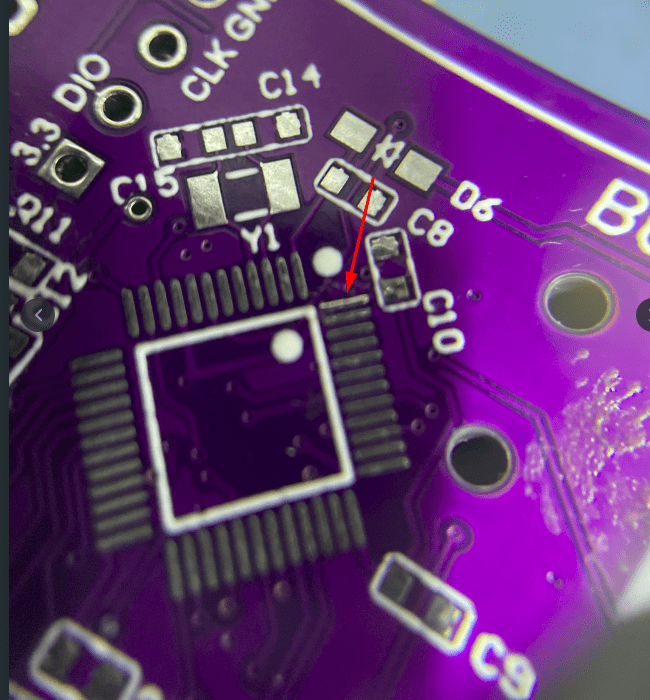
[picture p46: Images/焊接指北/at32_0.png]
at32_0


2. 用烙铁加热该焊盘，同时用镊子放置芯片，直到芯片与焊盘对齐，拿掉烙铁，为了防止一个焊盘固定不住，可以在另一个边再随意上点锡，如下图就有两个点固定。  
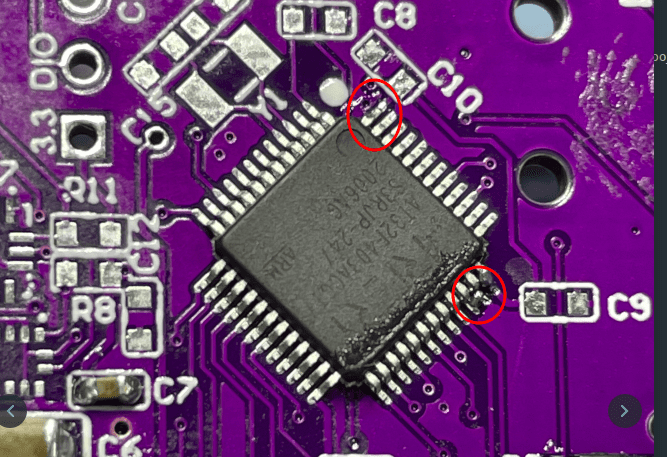
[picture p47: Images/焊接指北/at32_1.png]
at32_1


3. 用刀头烙铁的刀刃与芯片引脚相切，并用焊锡丝均匀涂抹芯片引脚上锡。

4. 通常上一步涂抹的时候你无法保证锡量的多少，会有个别引脚短路。这是需要用焊接海绵（焊接铜丝球）清除你的烙铁头，保证上面没有焊锡，并沾大量的助焊剂，用刀头刮芯片的引脚，使得短路的引脚上多余的锡被刀头刮掉。  
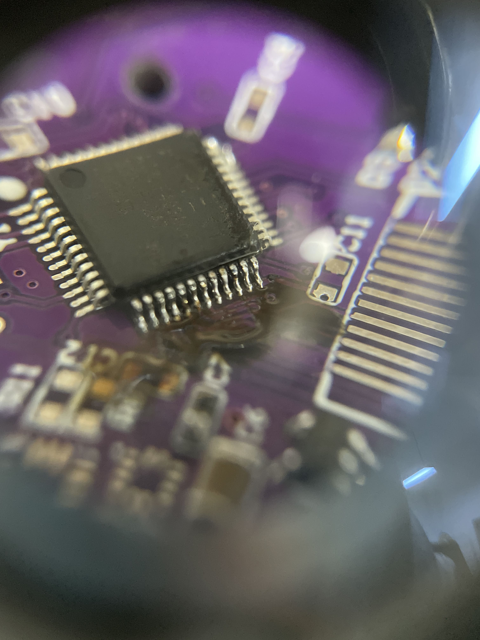
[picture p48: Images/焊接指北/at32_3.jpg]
at32_3


5. 重复3、4步，将剩下的3个边焊好，这时由于助焊剂的原因，你的板子和芯片会很恶心，用牙刷沾无水酒精刷掉即可。  
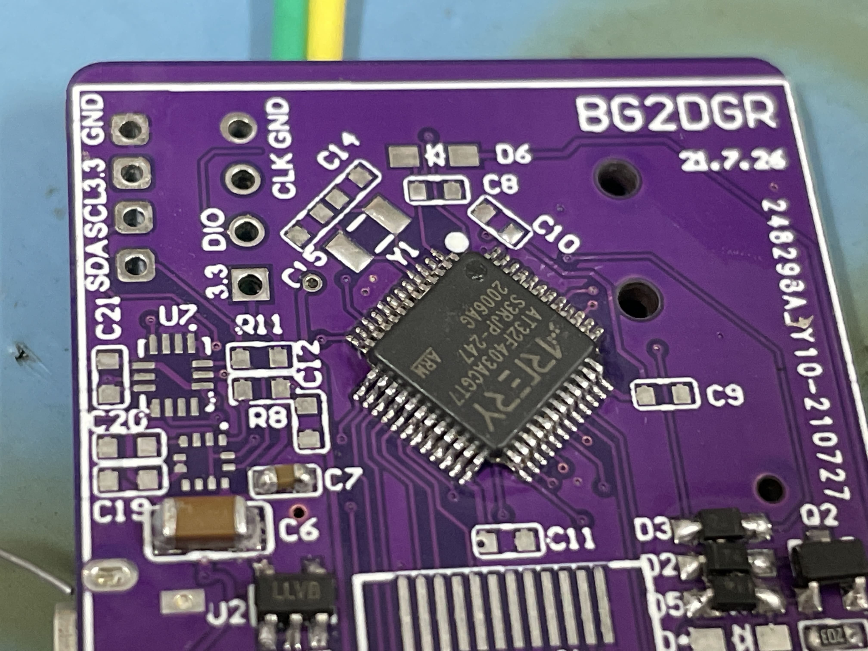
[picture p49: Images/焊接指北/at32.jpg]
at32


6. 焊接MCU周边的元件，主要是电源滤波电容C9~C12；RTC震荡电路Y1、C14、C15；复位电路K1、R7、C13；以及VBAT D6、C8。由于比较简单不再赘述。

#### 3.4.2 MCU测试

这里测试比较简单，用STLink（调试器）向MCU烧录程序即可。STLink的四个脚用杜邦线直接连接到板子的调试口，并用手轻轻按压就可充分接触，再在计算机上操作MDK下载程序。
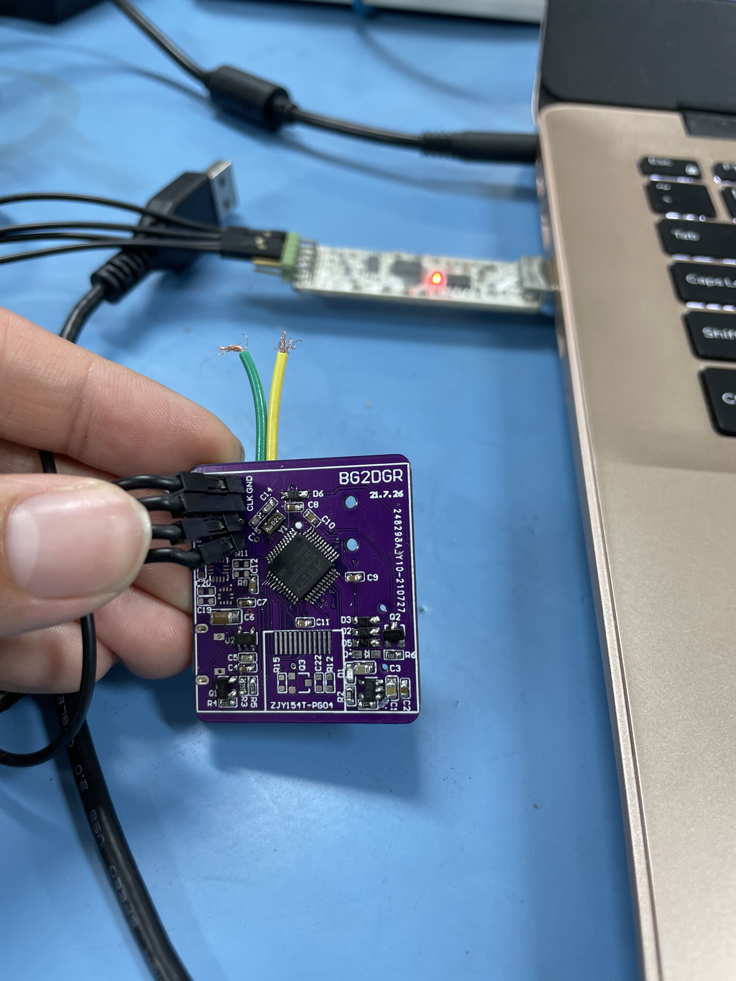
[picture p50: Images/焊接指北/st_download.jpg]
st_download

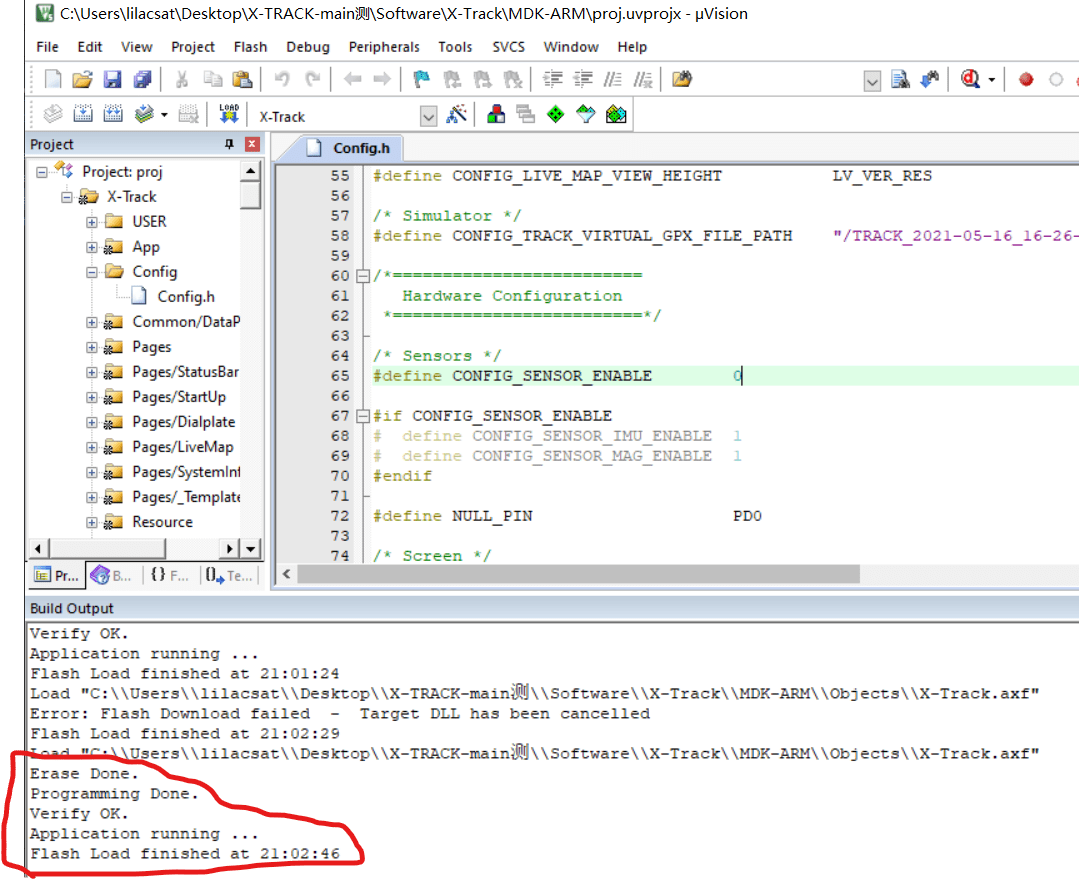
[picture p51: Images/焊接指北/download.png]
download


如果显示检测芯片失败，就要仔细检查芯片的焊接。

### <a name="encoder">  3.5 编码器 & 蜂鸣器

这里原理比较简单，也很容易焊接，注意这里的焊接顺序应该把编码器和蜂鸣器周边的元件先焊接好，最后再焊接蜂鸣器和编码器。
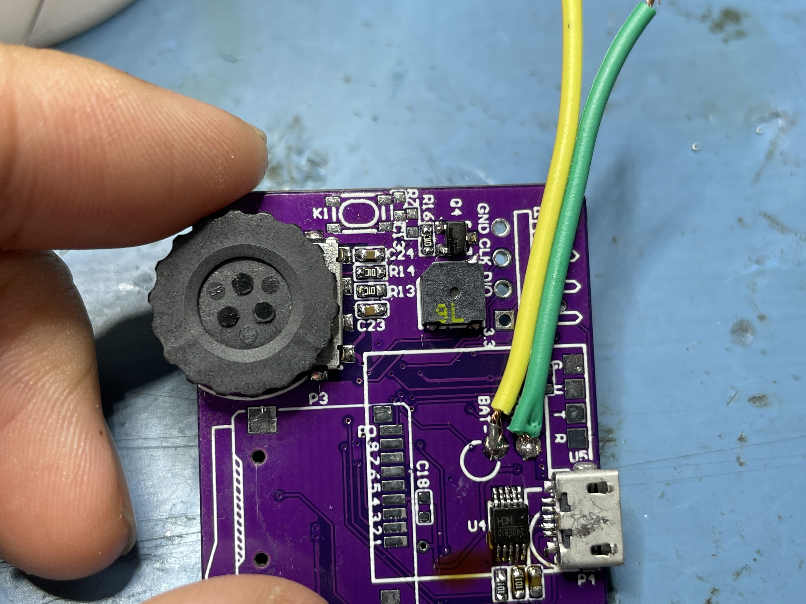
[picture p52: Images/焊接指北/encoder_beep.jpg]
encoder beep


### <a name="sd"> 3.6 SD卡槽

这里要注意最好用尖头烙铁一点点焊，信号引脚不建议拖焊，因为引脚容易和金属外壳短路。  
SD

### <a name="lcd"> 3.7 屏幕

首先要焊接背光控制电路  
led  
焊接屏幕排线时，先把所有焊盘加上锡，然后用刀头固定住，最后用尖头烙铁一个一个引脚加锡，使得排线的正反两面均有焊锡，保证牢固。  
screen  

### <a name="gps"> 3.8 GPS

最后焊接上GPS模块即可，模块上的字和PCB上的丝印一一对应（T-T R-R）

## <a name="debug"> 4. 整体测试

最终焊接上电池，就可以上电测试了，测试的效果就不放图了，跟主页上面的视频一样就说明功能都测试通过啦。

1. 长按按钮开机，开机后蜂鸣器会响。如果没有反应，首先通过万用表测试3.3V调试端口的电压，会不会在按下按钮时为3.3V，否则，检查编码器的焊接和电源开关部分的焊接情况。

2. 显示屏不亮，如果用手电筒从显示屏的背面照亮显示屏，如果有内容，说明背光电路有问题，检查背光电路，如果没有内容，检查屏幕焊接。

3. 屏幕空白或花屏，检查屏幕信号线及MCU的焊接情况。

4. 蜂鸣器不响，检查蜂鸣器电路和MCU焊接

5. 检测不到SD卡，检查SD格式是否正确，检查SD卡座焊接。

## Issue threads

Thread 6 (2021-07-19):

增加对蓝牙，ant+设备的支持，然后再增加strava live segment，然后续航再长一点就完美了

Pluto-leek, 2021-07-19:

Faultiness, 2021-07-19:
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

FASTSHIFT, 2021-07-19:
@Pluto-leek
ANT+协议不开源，如果要使用，每年要向佳明交几千美金授权费用。
strava live segment应该是佳明的收费服务。要浏览轨迹可以用免费的GPXSee。

liuxin27, 2021-07-22:
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
增加蓝牙是不是比较容易实现，迈金的速度踏频和心率带都支持双模

FASTSHIFT, 2021-07-22:
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

走BLE应该可以

arinport, 2021-07-23:
@FASTSHIFT

按照Garmin的官方说法，是你使用ANT+的商标，或者声称支持ANT+才需要缴纳费用。我们这个属于爱好者项目，犯不着：
https://www.thisisant.com/developer/ant-plus/certification-faq/category/258/

> No.  For authorization to apply ANT+ brands, logos or wordmarks to any product  or claim ANT+ compatibility in any way,  all implemented profiles must be certified.

我们并没有**最终做出来**一个产品，只是给一个图纸，至于兼容不兼容，你拿来做产品才需要考虑。正如Linux严格上来说不是UNIX，但没人否认一样。

第二，ANT+的芯片其实蛮多的：https://www.mouser.sg/Search/Refine?Keyword=nRF51422

https://www.nordicsemi.com/-/media/Software-and-other-downloads/Product-Briefs/nRF51422-product-brief.pdf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

我个人认为不是太大的问题。

第三，我认为考虑现在芯片大涨价的背景下，一些不那么主流的芯片可能可以考虑了，例如V3s，f1c100s，还有大热的K210。甚至于，可以开启省电模式，有省电功能屏幕或者UI只运行上面那个集成了Cortex-M0的ANT+芯片，以取得最佳的续航。

我个人会往这个方面考虑

FASTSHIFT, 2021-07-23:
@arinpo
不错的提议，后期会考虑的

FASTSHIFT, 2021-07-23:
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

不错的提议，后期会考虑的

zhangchunzhong, 2021-07-25:
附议。加入功率计，速度计，心率计，这样才比较专业。现在这些外设都是ant和蓝牙双协议的。如果ant不行，就只支持蓝牙就行。
另外，参考佳明的设计，显示页面可配置也非常重要。

zhangchunzhong, 2021-07-25:
如果你们加入蓝牙，我就参加开发。。。

arinport, 2021-07-26:
@zhangchunzhong

得先选型啥芯片吧。要考虑产量/供应链/生产难度/温湿度要求/功耗一系列问题。不然写了代码也是白写

ANT+我在官网只看到了nRF系列芯片支持，同时支持蓝牙。但是现在的供应链不是那么稳定。另外STM32现在的价格已经疯了，已经比很多其他类型的芯片要贵上10倍了。

至于写代码，这个反而是最稳定没啥疑虑的问题了。v3s/f1c100s都够上Linux了。

arinport, 2021-07-26:
@zhangchunzhong

https://www.nordicsemi.com/-/media/Software-and-other-downloads/Product-Briefs/nRF52832-product-brief.pdf

你看下这个，是Cortex-M4的CPU，硬件规格和 @FASTSHIFT 的版本差不多一致，多了蓝牙和ANT+的功能。某宝有SDK买（搜nRF52），不需要你做板子。

期待你能连上Garmin的功率计和速度计

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

FASTSHIFT, 2021-07-26:
@arinport
在当前体验不打折扣的情况下，MCU的性能：
主频 >= 200MHz（如果有GPU，主频要求可以降低，但不能低于100MHz）
RAM >= 200K（至少要有完整的帧缓冲保证显示不撕裂，lvgl需要至少32K~64K的内存池，保证完整的轨迹绘制的功能）
FLASH >= 512K （当前代码尺寸大约260KB）
之前也关注过这个芯片，但是受限于性能（应该是和功耗做了妥协），没有继续研究。

您会使用这个蓝牙芯片吗，欢迎向这个项目提交PR，完善蓝牙功能。

arinport, 2021-07-26:
@FASTSHIFT

价格上大概率会用便宜一点的。这个芯片太贵了。

我初步的构想会是

1. F1c100s/F1c200s 400MHz - 1.1GHz (集成32MiB/64MiB RAM)， 电流可能在100mA左右 （之所以电流低是因为28nm的工艺）
2.一个16MiB/32MiB的Flash
3. nRF51422， 电流约 10mA - 20mA，低功耗模式下只开这个MCU

_**但是这样子可能改动太大了**_。

硬件项目还是要您先沟通好。例如这个芯片的产能，板子的面积，功耗，散热等等问题。

FASTSHIFT, 2021-07-26:
@arinport
那您对F1c100s/F1c200s开发熟吗？倾向于上linux还是用裸机开发？
我之前也玩过这个芯片，但是开发资料太碎了，学习成本不低。

arinport, 2021-07-26:
@FASTSHIFT

我目前只试过Linux和RT-Thread。资料非常少。好处是Linux确实是可以跑起来的，速度还不算慢。我正式项目用过C++和Golang（GCC-go）的程序。不过我没做过您那么复杂的UI

arinport, 2021-07-26:
@FASTSHIFT

关键在于第三点nRF51422能否跑起来，连接ANT+设备（例如4个），连接以后的电量消耗，以及是否能带得动低功耗模式下的UI。

至于是不是f1c100s，换个其他芯片区别也不是很大。

FASTSHIFT, 2021-07-26:
@arinport
关于ANT+，如果就算能做出来，我不确定佳明是否允许开源，商业化的东西需要谨慎。

arinport, 2021-07-26:
@FASTSHIFT

做一个github repo不至于吧。Nordic的SDK可以随便下载。至于真的做成产品，我感觉更大的问题是有没有人买的问题。行者冲进去结果发现销量实在太小了。被Garmin追究反而是一个幸福的烦恼。

坦白说，最佳商业化路线应该是HUD，目前的汽车有HUD寥寥无几，选配费用很高，而且大部分HUD做得很烂。如果您真能做到GPS测速+导航+阳光下看清屏幕，做HUD岂不美哉？

Pluto-leek, 2021-07-27:
> @arinport
> 关于ANT+，如果就算能做出来，我不确定佳明是否允许开源，商业化的东西需要谨慎。

ANT+不支持，支持蓝牙也可以，现在自行车行业的主流感应器基本都是蓝牙，ant+双模的

doyou, 2021-07-27:
是不是可以建议采用e-ink屏幕以保障续航及高亮下清晰？

FASTSHIFT, 2021-07-28:
有谁会写App吗？或者有BLE开发经验?

FASTSHIFT, 2021-07-28:
> 是不是可以建议采用e-ink屏幕以保障续航及高亮下清晰？

墨水屏刷新体验不好，而且不适合在阳光下暴晒。

zhangchunzhong, 2021-07-28:
> 有会写App的吗？或者有BLE开发经验？愿意参与下一代的开发吗

我现在用的是佳明520，带有导航功能的佳明1030要4500+元，太太贵了。。。
我有c++开发经验，应该BLE并没有经验，但是感觉不是大问题。愿意。

FASTSHIFT, 2021-07-28:
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

第二代有计划加入导航功能，而且经过论证是完全可行的！
您可以尝试学习nRF52832，资料和现成的开发板都很多。

arinport, 2021-07-28:
@FASTSHIFT

导航功能我可感兴趣了。可否详细赐教？如果使用定制的App如高德地图需要手机支持。如果您用自己的算法/离线地图的话，那就真的是厉害了。。。

另外如果有声音就比较困难（毕竟户外的功率要求挺高的），不知道您是计划用蓝牙耳机还是直接公放。

屏幕您这边第二代有任何计划吗？是否会使用AMOLED屏幕？我有测试过AMOLED屏幕直接放到车内可以投影到挡风玻璃上（1000nit真不是盖的）

FASTSHIFT, 2021-07-28:
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

导航在手机上计算。
声音我觉得不是刚需，振动提示足够。但是加TTS也是可以的。
AMOLED分辨率多少？超过480*320不考虑，MCU带不动。

arinport, 2021-07-28:
@FASTSHIFT

如果是在手机上计算您这边是打算定制高德地图吗？

FASTSHIFT, 2021-07-28:
> @FASTSHIFT
>
> 如果是在手机上计算您这边是打算定制高德地图吗？

高德地图是待选之一

dankes, 2021-07-29:
参加开发

chenghongyao, 2021-07-30:
期待第二代，正学习工程，希望参与

HanfG, 2021-11-04:
希望可以参与第二代的开发！！！！
掌握java和python语言，开发过简单的安卓应用，但是UI太拉了；硬件懂一点点（软件工程自学硬件，基础功比较拉跨），AD熟练使用。

ZhongYic00, 2022-05-21:
> > 是不是可以建议采用e-ink屏幕以保障续航及高亮下清晰？
>
> 墨水屏刷新体验不好，而且不适合在阳光下暴晒。个人比较喜欢追求体验，续航可以通过增加电池容量解决。

墨水屏对比度很高，应该很适合阳光下使用吧。看了一下可能的问题是暴晒导致泛黄，但只是部分屏幕的材料问题
考虑到刷新慢可以把动画去掉，然后通过局部刷新能够大大降低对MCU性能的要求

FChong96, 2022-08-22:
NXP的RT1060感觉性能满足不知道功耗如何

1061875478, 2022-08-28:
第二代开发还在进行吗

l-jesse, 2022-09-01:
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

AMOLED 在哪里能买到？我在某宝搜了下有一家卖2.8寸，240*400带触摸，但是问客服说已经停产了。
还有 AMOLED 是不是都可以通过编程来调低刷新率到1HZ？这样的话可以放在省电模式对续航应该有帮助

vitrumzhu, 2024-01-12:
可以看看这个项目https://github.com/hishizuka/pizero_bikecomputer/

AlexZhang087, 2024-02-26:
各位大神们，这都24年，二代研发好了么

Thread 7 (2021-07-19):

BOM  配单问题

Leo204-LKY, 2021-07-19:
什么也不懂，没有经验，想拿这个项目练练手（是真的什么都不懂QwQ）
拿去淘宝 BOM 配单的时候店家说这些不够详细
大佬可以帮忙补充下吗，谢谢！

FootPrint | Comment | LibRef | Designator | Quantity | 问题
-- | -- | -- | -- | -- | --
Pad_B | BAT_IN | Pad | BAT+ | 1 | 型号？
Pad_B | GND | Pad | BAT- | 1 | 型号？
蜂鸣器 | Buzzer | BZ | BZ1 | 1 | 体积  多少V  有源无源
_SMD5020 |   |   |   |   | 什么感值
电容_C0805 | 4.7UF | cap | C1,   C3 | 2 |  
电容_C0603 | 104 | cap | C2,   C4, C7, C8, C13, C18, C19, C20, | 12 |  
电容_C0603 | 106 | cap | C5 | 1 |  
电容_C1206 | 22uF | cap | C6 | 1 |  
电容_C0603 | 105 | cap | C9,   C10, C11, C12, C16, C17 | 6 |  
电容_C0603 | 22pf | cap | C14,   C15 | 2 |  
LED_0603 | red | LED | D1 | 1 |  
二极管_SOD-323 | 1N4148 | Diode | D2,   D3, D4, D5 | 4 |  
二极管_SOD-323 | 1N4007 | Diode | D6 | 1 |  
开关按键 | SKRP | SW-PB | K1 | 1 | 体积 直插还是贴片
HDR1X4H | Header   4 | Header   4 | P2 | 1 | 排针还是排母
接插件 | Micro_SD | Micro_SD | P3 | 1 | 发图确认
接插件 | MICRO   USB | MICRO   USB | P4 | 1 | 发图确认
MOS_SOT-23 | AO3401 | MOSFET-P | Q1 | 1 |  
MOS_SOT-23 | AON3400 | MOSFET-N | Q2 | 1 |  
MOS_SOT-23 | AO3400 | MOSFET-N | Q3,   Q4 | 2 |  
电阻_R0603 | 2K | Res | R1 | 1 |  
电阻_R0603 | 1K | Res | R2 | 1 |  
电阻_R0603 | 20K | Res | R3,   R4, R5, R6 | 4 |  
电阻_R0603 | 10K | Res | R7,   R8, R11, R13, R14, R15, R16 | 7 |  
电阻_R0603 | 100R | Res | R9,   R10 | 2 |  
电阻_R0603 | 10R | Res | R12 | 1 |  
SOT23-5 | MCP73831 | MCP73831 | U1 | 1 |  
SOT23-5 | LP5907-3.3 | LP5907 | U2 | 1 |  
AT主控 | AT32F403ACGU | AT32F403CGU6 | U3 | 1 |  
串口 | CH340E | CH340E | U4 | 1 |  
GPS-HTZN | HT1818Z3G5L | HT1818Z3G5L | U5 | 1 |  
LGA- | LIS3MDL | LIS3DMDL | U6 | 1 |  
LGA- | LSM6DSM | LSM6DSM | U7 | 1 |  
ZJY154T- | IPS154-12 | IPS154-12 | U8 | 1 | 完整型号
SIQ-02FVS3 | Rotary   Encoder | Rotary   Encoder | U9 | 1 |  
晶振_3215 | 32.768K | XTAL_A | Y1 | 1 |  
Total |  |  |  | 67 |  

Hardware 文件夹里的 BOM pdf 里因为 Footfrint 的不同内容之间没有横线分割所以可能把一项当成两项了，比如那个蜂鸣器…不过还是问一下具体的吧

FASTSHIFT, 2021-07-20:
只能帮到你这里
https://github.com/FASTSHIFT/X-TRACK/blob/main/Hardware/README.md

Leo204-LKY, 2021-07-20:
十分感谢！

Leo204-LKY, 2021-07-22:
emmm碰到新问题了
AT32F403ACGU7这个芯片没货，有可以代替的吗

FASTSHIFT, 2021-07-22:
@Leo204-LKY
可以换LQFP封装的AT32F403A，但是得会修改板子。

Leo204-LKY, 2021-07-22:
> @Leo204-LKY
> 可以换LQFP封装的AT32F403A，但是得会修改板子。

AT32F403AVCT7可以吗？

FASTSHIFT, 2021-07-22:
不行，FLASH容量至少512K，AT32F403AVCT7的FLASH大小是256KB。
另外，尽选小封装的MCU。

Leo204-LKY, 2021-07-22:
> 不行，FLASH容量至少512K，AT32F403AVCT7的FLASH大小是256KB。
> 另外，尽选小封装的MCU。

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

在tb上找到一张这样的表，麻烦大佬看一下，哪些符合要求
改板子的事我可以找人
实在抱歉，问题比较多

FASTSHIFT, 2021-07-22:
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
这个范围，体积要尽量小

Leo204-LKY, 2021-07-22:
> 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
> 这个范围，体积要尽量小

好的，我去问问

zhihancn, 2021-07-24:
大佬有计算下来这些成本大致要多少钱呢？

FASTSHIFT, 2021-07-24:
@zhihancn
大概不到300

Leo204-LKY, 2021-07-24:
@zhihancn 嗯，差不多
但目前找不到 AT32F403A 芯片，建议要做的话先备好芯片

zhihancn, 2021-07-25:
@FASTSHIFT
@Leo204-LKY
哦哦哦，ok，谢谢大佬

zxuewu, 2021-08-05:
请问电路板是需要自己焊接吗？（本人不懂电路设计。）如果是，能把你上面提到的完善好的BOM配单发出来吗，我也想搞一下。谢谢！

Leo204-LKY, 2021-08-06:
> 请问电路板是需要自己焊接吗？（本人不懂电路设计。）如果是，能把你上面提到的完善好的BOM配单发出来吗，我也想搞一下。谢谢！

要自己焊接，不过tb也有加工的，不过价格就比较贵了
我最近没有时间做这个项目，所以只能暂时搁置了:/

zinwalin, 2021-08-12:
> @zhihancn
> 大概不到300

现在应该是不太够了

Closed 2021-09-07.

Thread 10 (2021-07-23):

大家组队一起搞X-TRACK，感兴趣的加群730459105

pengzi007, 2021-07-23:
一个人搞太不环保，而且有一定的门槛，大家一起来搞。Q群组队了：730459105

dankes, 2021-07-29:
有微信或钉钉群吗

wwzh2015, 2021-08-09:
这个群是卖成品的

wwzh2015, 2021-08-09:
> 有微信或钉钉群吗

微信群：X-TRACK技术交流

zinwalin, 2021-08-12:
> X-TRACK技术交流

帮忙发一下微信群的二维码，多谢。

arvidwen, 2021-09-16:
> > 有微信或钉钉群吗
>
> 微信群：X-TRACK技术交流

请问微信群怎么加入？

Stonekity, 2022-02-20:
我们大家一起自己建一个吧
加wx: Myseist 拉微信群[X-TRACK技术交流]

Stonekity, 2022-02-20:
群拉完了，及时更新微信群二维码

Stonekity, 2022-02-20:
![Uploading CE22B0DE-4C87-4279-BA8A-324B28624FAB.jpeg…]()

Stonekity, 2022-02-20:
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

xinmans, 2023-09-17:
这个群还在讨论吗？有新二维码吗

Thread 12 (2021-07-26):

keil5 编译源码错误，请教

polyGithub, 2021-07-26:
>

..\USER\App\Utils\ArduinoJson\src\ArduinoJson/Numbers/parseNumber.hpp(76): error:  #304: no instance of overloaded function "ArduinoJson6180_51::VariantData::setInteger" matches the argument list

..\Libraries\SdFat\src\SdFat.h(333): error:  #441: argument list for class template "SdFileSystem" is missing

polyGithub, 2021-07-26:
*** Using Compiler 'V5.05 (build 41)', folder: 'C:\Keil_v5\ARM\ARMCC\Bin'
*** Warning: Using Microlib and C++ file(s) might cause the linker to fail !

Rebuild target 'X-Track'
compiling DP_GPS.cpp...
compiling DP_Clock.cpp...
compiling DataProc.cpp...
compiling DP_SportStatus.cpp...
compiling App.cpp...
compiling DP_Power.cpp...
compiling DP_IMU.cpp...
compiling DP_MusicPlayer.cpp...
compiling DP_MAG.cpp...
compiling DP_Storage.cpp...
compiling DP_SysConfig.cpp...
compiling DP_TzConv.cpp...
compiling main.cpp...
compiling DP_Recorder.cpp...
..\Libraries\SdFat\src\SdFat.h(333): error:  #441: argument list for class template "SdFileSystem" is missing
             SdFileSystem::begin();
..\USER\App\Common\DataProc\DP_Recorder.cpp: 0 warnings, 1 error
compiling StartUpModel.cpp...
compiling StartUpView.cpp...
compiling DP_TrackFilter.cpp...
compiling StartUp.cpp...
compiling AppFactory.cpp...
compiling StatusBar.cpp...
compiling Dialplate.cpp...
compiling DialplateModel.cpp...
compiling DialplateView.cpp...
compiling SystemInfosModel.cpp...
compiling LiveMapModel.cpp...
compiling LiveMap.cpp...
compiling LiveMapView.cpp...
compiling TemplateModel.cpp...
compiling Template.cpp...
compiling SystemInfosView.cpp...
compiling font_bahnschrift_13.c...
compiling ResourcePool.cpp...
compiling TemplateView.cpp...
compiling font_bahnschrift_17.c...
compiling font_bahnschrift_32.c...
compiling font_bahnschrift_65.c...
compiling SystemInfos.cpp...
..\Libraries\SdFat\src\SdFat.h(333): error:  #441: argument list for class template "SdFileSystem" is missing
             SdFileSystem::begin();
..\USER\App\Pages\SystemInfos\SystemInfos.cpp: 0 warnings, 1 error
compiling font_agencyb_36.c...
compiling img_src_alarm.c...
compiling img_src_gps_arrow.c...
compiling img_src_gps_pin.c...
compiling img_src_battery.c...
compiling img_src_locate.c...
compiling img_src_menu.c...
compiling img_src_satellite.c...
compiling img_src_origin_point.c...
compiling img_src_stop.c...
compiling img_src_trip.c...
compiling img_src_pause.c...
compiling img_src_battery_info.c...
compiling img_src_bicycle.c...
compiling img_src_start.c...
compiling img_src_compass.c...
compiling img_src_gyroscope.c...
compiling img_src_map_location.c...
compiling img_src_system_info.c...
compiling img_src_storage.c...
compiling img_src_time_info.c...
compiling img_src_sd_card.c...
compiling lv_label_anim_effect.cpp...
compiling MapConv.cpp...
compiling lv_obj_ext_func.cpp...
compiling lv_anim_timeline_wrapper.c...
compiling PM_Anim.cpp...
compiling PM_Drag.cpp...
compiling ResourceManager.cpp...
compiling PM_State.cpp...
compiling PingPongBuffer.c...
compiling PM_Router.cpp...
compiling PM_Base.cpp...
compiling GPS_Transform.c...
compiling GPX.cpp...
compiling DataCenter.cpp...
compiling Account.cpp...
compiling GPX_Parser.cpp...
compiling TonePlayer.cpp...
compiling DateStrings.cpp...
compiling TileSystem.cpp...
compiling TileConv.cpp...
compiling TrackLineFilter.cpp...
compiling TrackPointFilter.cpp...
compiling Time.cpp...
compiling HAL.cpp...
compiling HAL_Clock.cpp...
compiling HAL_GPS.cpp...
compiling DisplayFault.cpp...
..\Libraries\SdFat\src\SdFat.h(333): error:  #441: argument list for class template "SdFileSystem" is missing
             SdFileSystem::begin();
..\USER\Display\DisplayFault.cpp: 0 warnings, 1 error
compiling Display.cpp...
compiling HAL_Backlight.cpp...
compiling StorageService.cpp...
..\USER\App\Utils\ArduinoJson\src\ArduinoJson/Numbers/parseNumber.hpp(76): error:  #304: no instance of overloaded function "ArduinoJson6180_51::VariantData::setInteger" matches the argument list
            argument types are: (ArduinoJson6180_51::Integer)
            object type is: ArduinoJson6180_51::VariantData
          result.setInteger(Integer(~mantissa + 1));
..\USER\App\Utils\ArduinoJson\src\ArduinoJson/Numbers/parseNumber.hpp(80): error:  #304: no instance of overloaded function "ArduinoJson6180_51::VariantData::setInteger" matches the argument list
            argument types are: (ArduinoJson6180_51::UInt)
            object type is: ArduinoJson6180_51::VariantData
        result.setInteger(UInt(mantissa));
..\USER\App\Utils\ArduinoJson\src\ArduinoJson/Variant/VariantCompare.hpp(164): error:  #70: incomplete type is not allowed
      Comparer<Integer> comparer(lhs);
          detected during:
            instantiation of "TVisitor::result_type ArduinoJson6180_51::VariantData::accept(TVisitor &) const [with TVisitor=ArduinoJson6180_51::Comparer<ArduinoJson6180_51::VariantConstRef, void>]" at line 16 of "..\USER\App\Utils\ArduinoJson\src\ArduinoJson/Variant/VariantFunctions.hpp"
            instantiation of "TVisitor::result_type ArduinoJson6180_51::variantAccept(const ArduinoJson6180_51::VariantData *, TVisitor &) [with TVisitor=ArduinoJson6180_51::Comparer<ArduinoJson6180_51::VariantConstRef, void>]" at line 245 of "..\USER\App\Utils\ArduinoJson\src\ArduinoJson/Variant/VariantRef.hpp"
            instantiation of "TVisitor::result_type ArduinoJson6180_51::VariantConstRef::accept(TVisitor &) const [with TVisitor=ArduinoJson6180_51::Comparer<ArduinoJson6180_51::VariantConstRef, void>]" at line 201
            instantiation of "ArduinoJson6180_51::CompareResult ArduinoJson6180_51::compare(const T1 &, const T2 &) [with T1=ArduinoJson6180_51::VariantConstRef, T2=ArduinoJson6180_51::VariantConstRef]" at line 205
..\USER\App\Utils\ArduinoJson\src\ArduinoJson/Variant/VariantCompare.hpp(169): error:  #70: incomplete type is not allowed
      Comparer<UInt> comparer(lhs);
          detected during:
            instantiation of "TVisitor::result_type ArduinoJson6180_51::VariantData::accept(TVisitor &) const [with TVisitor=ArduinoJson6180_51::Comparer<ArduinoJson6180_51::VariantConstRef, void>]" at line 16 of "..\USER\App\Utils\ArduinoJson\src\ArduinoJson/Variant/VariantFunctions.hpp"
            instantiation of "TVisitor::result_type ArduinoJson6180_51::variantAccept(const ArduinoJson6180_51::VariantData *, TVisitor &) [with TVisitor=ArduinoJson6180_51::Comparer<ArduinoJson6180_51::VariantConstRef, void>]" at line 245 of "..\USER\App\Utils\ArduinoJson\src\ArduinoJson/Variant/VariantRef.hpp"
            instantiation of "TVisitor::result_type ArduinoJson6180_51::VariantConstRef::accept(TVisitor &) const [with TVisitor=ArduinoJson6180_51::Comparer<ArduinoJson6180_51::VariantConstRef, void>]" at line 201
            instantiation of "ArduinoJson6180_51::CompareResult ArduinoJson6180_51::compare(const T1 &, const T2 &) [with T1=ArduinoJson6180_51::VariantConstRef, T2=ArduinoJson6180_51::VariantConstRef]" at line 205
..\USER\App\Utils\ArduinoJson\src\ArduinoJson/Variant/VariantCompare.hpp(61): error:  #304: no instance of overloaded function "ArduinoJson6180_51::arithmeticCompare" matches the argument list
            argument types are: (ArduinoJson6180_51::Integer, bool)
      return arithmeticCompare(lhs, rhs);
          detected during:
            instantiation of "ArduinoJson6180_51::CompareResult ArduinoJson6180_51::Comparer<T, ArduinoJson6180_51::enable_if<<expression>, void>::type>::visitSignedInteger(ArduinoJson6180_51::Integer) [with T=bool]" at line 60 of "..\USER\App\Utils\ArduinoJson\src\ArduinoJson/Variant/VariantData.hpp"
            instantiation of "TVisitor::result_type ArduinoJson6180_51::VariantData::accept(TVisitor &) const [with TVisitor=ArduinoJson6180_51::Comparer<bool, void>]" at line 16 of "..\USER\App\Utils\ArduinoJson\src\ArduinoJson/Variant/VariantFunctions.hpp"
            instantiation of "TVisitor::result_type ArduinoJson6180_51::variantAccept(const ArduinoJson6180_51::VariantData *, TVisitor &) [with TVisitor=ArduinoJson6180_51::Comparer<bool, void>]" at line 245 of "..\USER\App\Utils\ArduinoJson\src\ArduinoJson/Variant/VariantRef.hpp"
            instantiation of "TVisitor::result_type ArduinoJson6180_51::VariantConstRef::accept(TVisitor &) const [with TVisitor=ArduinoJson6180_51::Comparer<bool, void>]" at line 186
            instantiation of "ArduinoJson6180_51::CompareResult ArduinoJson6180_51::Comparer<T, ArduinoJson6180_51::enable_if<ArduinoJson6180_51::IsVisitable<T>::value, void>::type>::accept(TComparer &) [with T=ArduinoJson6180_51::VariantConstRef, TComparer=ArduinoJson6180_51::Comparer<bool, void>]" at line 175
            instantiation of "ArduinoJson6180_51::CompareResult ArduinoJson6180_51::Comparer<T, ArduinoJson6180_51::enable_if<ArduinoJson6180_51::IsVisitable<T>::value, void>::type>::visitBoolean(bool) [with T=ArduinoJson6180_51::VariantConstRef]" at line 66 of "..\USER\App\Utils\ArduinoJson\src\ArduinoJson/Variant/VariantData.hpp"
            instantiation of "TVisitor::result_type ArduinoJson6180_51::VariantData::accept(TVisitor &) const [with TVisitor=ArduinoJson6180_51::Comparer<ArduinoJson6180_51::VariantConstRef, void>]" at line 16 of "..\USER\App\Utils\ArduinoJson\src\ArduinoJson/Variant/VariantFunctions.hpp"
            instantiation of "TVisitor::result_type ArduinoJson6180_51::variantAccept(const ArduinoJson6180_51::VariantData *, TVisitor &) [with TVisitor=ArduinoJson6180_51::Comparer<ArduinoJson6180_51::VariantConstRef, void>]" at line 245 of "..\USER\App\Utils\ArduinoJson\src\ArduinoJson/Variant/VariantRef.hpp"
            instantiation of "TVisitor::result_type ArduinoJson6180_51::VariantConstRef::accept(TVisitor &) const [with TVisitor=ArduinoJson6180_51::Comparer<ArduinoJson6180_51::VariantConstRef, void>]" at line 201
            instantiation of "ArduinoJson6180_51::CompareResult ArduinoJson6180_51::compare(const T1 &, const T2 &) [with T1=ArduinoJson6180_51::VariantConstRef, T2=ArduinoJson6180_51::VariantConstRef]" at line 205
..\USER\App\Utils\ArduinoJson\src\ArduinoJson/Variant/VariantCompare.hpp(65): error:  #304: no instance of overloaded function "ArduinoJson6180_51::arithmeticCompare" matches the argument list
            argument types are: (ArduinoJson6180_51::UInt, bool)
      return arithmeticCompare(lhs, rhs);
          detected during:
            instantiation of "ArduinoJson6180_51::CompareResult ArduinoJson6180_51::Comparer<T, ArduinoJson6180_51::enable_if<<expression>, void>::type>::visitUnsignedInteger(ArduinoJson6180_51::UInt) [with T=bool]" at line 63 of "..\USER\App\Utils\ArduinoJson\src\ArduinoJson/Variant/VariantData.hpp"
            instantiation of "TVisitor::result_type ArduinoJson6180_51::VariantData::accept(TVisitor &) const [with TVisitor=ArduinoJson6180_51::Comparer<bool, void>]" at line 16 of "..\USER\App\Utils\ArduinoJson\src\ArduinoJson/Variant/VariantFunctions.hpp"
            instantiation of "TVisitor::result_type ArduinoJson6180_51::variantAccept(const ArduinoJson6180_51::VariantData *, TVisitor &) [with TVisitor=ArduinoJson6180_51::Comparer<bool, void>]" at line 245 of "..\USER\App\Utils\ArduinoJson\src\ArduinoJson/Variant/VariantRef.hpp"
            instantiation of "TVisitor::result_type ArduinoJson6180_51::VariantConstRef::accept(TVisitor &) const [with TVisitor=ArduinoJson6180_51::Comparer<bool, void>]" at line 186
            instantiation of "ArduinoJson6180_51::CompareResult ArduinoJson6180_51::Comparer<T, ArduinoJson6180_51::enable_if<ArduinoJson6180_51::IsVisitable<T>::value, void>::type>::accept(TComparer &) [with T=ArduinoJson6180_51::VariantConstRef, TComparer=ArduinoJson6180_51::Comparer<bool, void>]" at line 175
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
FASTSHIFT, 2021-07-26:
@polyGithub
您的Keil的版本是？
务必使用Keil v5.25版本以上进行编译，旧编译器不一定能识别较新的C++语法

polyGithub, 2021-07-26:
> @polyGithub
> 您的Keil的版本是？
> 务必使用Keil v5.25版本以上进行编译，旧编译器不一定能识别较新的C++语法

好的，我的版本刚好是5.24的  我安装一个新的版本试试 ths

polyGithub, 2021-07-27:
使用keil 5.27版本 编译无问题

Closed 2021-07-27.

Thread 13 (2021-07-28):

[PR/WIP] ANT+ and BLE support (With App/Cellphone)

arinport, 2021-07-28:
- [ ] Test under nRF52
- [ ] Magene speed/RPM/Heart-rate/Speedplay powermeter
- [ ] iPhone/Xiaomi BLE  & app test
- [ ] Chip selection (nRF52832/nRF51422/etc)
- [ ] SPI protocol definition

(...to be defined)

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

FASTSHIFT, 2024-07-24:
二代码表已支持BLE，使用 AT32F437 + NRF52832 方案。

Closed 2024-07-24.

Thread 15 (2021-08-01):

建了一个微信群，方便大家技术交流和经验分享

wwzh2015, 2021-08-01:
虚位以待，快来加入呀*_^
如果7天以后下面的二维码过期了，大家直接微信搜索”X-TRACK技术交流“加入。
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

jabezGit, 2021-08-09:
不是作者群，想探讨技术的，不建议加这群

wwzh2015, 2021-08-09:
> 不是作者群，想探讨技术的，不建议加这群
你是scooo?
这个群就是讨论技术和落地的，如果不喜欢你可以退出

saltfishh, 2021-08-21:
微信貌似搜不到,方便留个二维码吗

wwzh2015, 2021-08-22:
[](url)

> 微信貌似搜不到,方便留个二维码吗

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

wwzh2015, 2021-08-22:
[](url)

> 微信貌似搜不到,方便留个二维码吗

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

saltfishh, 2021-08-22:
已经加了，十分感谢。

wwzh ***@***.***> 于 2021年8月22日周日 11:34写道：

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

TaXue-DuBa, 2022-02-20:
> 虚位以待，快来加入呀*_^ 如果7天以后下面的二维码过期了，大家直接微信搜索”X-TRACK技术交流“加入。 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

搜不到啊，，留个二维码吧。。

Closed 2021-08-09.

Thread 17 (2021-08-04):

Keil 编译报错

stig3, 2021-08-04:
环境 win10 keil 5.30
AT32 DFP已经安装
然后报缺少库？

Error instantiating RTE components
Error #540: 'Keil::Device:Startup:1.0.1' component is not available for target 'X-Track'
Error #540: 'Keil::Device:StdPeriph Drivers:ADC:1.0.1' component is not available for target 'X-Track'
Error #540: 'Keil::Device:StdPeriph Drivers:BKPR:1.0.1' component is not available for target 'X-Track'
Error #540: 'Keil::Device:StdPeriph Drivers:DMA:1.0.1' component is not available for target 'X-Track'
Error #540: 'Keil::Device:StdPeriph Drivers:EXTI:1.0.1' component is not available for target 'X-Track'
Error #540: 'Keil::Device:StdPeriph Drivers:FMC:1.0.1' component is not available for target 'X-Track'
Error #540: 'Keil::Device:StdPeriph Drivers:Framework:1.0.1' component is not available for target 'X-Track'
Error #540: 'Keil::Device:StdPeriph Drivers:GPIO:1.0.1' component is not available for target 'X-Track'
Error #540: 'Keil::Device:StdPeriph Drivers:PWR:1.0.1' component is not available for target 'X-Track'
Error #540: 'Keil::Device:StdPeriph Drivers:RCC:1.0.1' component is not available for target 'X-Track'
Error #540: 'Keil::Device:StdPeriph Drivers:RTC:1.0.1' component is not available for target 'X-Track'
Error #540: 'Keil::Device:StdPeriph Drivers:SPI:1.0.1' component is not available for target 'X-Track'
Error #540: 'Keil::Device:StdPeriph Drivers:TIMER:1.0.1' component is not available for target 'X-Track'
Error #540: 'Keil::Device:StdPeriph Drivers:USART:1.0.1' component is not available for target 'X-Track'
Error #540: 'Keil::Device:System_AT32Fxx:1.0.1' component is not available for target 'X-Track'

ArtisticZhao, 2021-08-04:
Keil 版本多少？ 还有支持包能截个图么？

stig3, 2021-08-04:
> Keil 版本多少？ 还有支持包能截个图么？

Keil是5.30的
支持包截图如下
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

FASTSHIFT, 2021-08-04:
@stig3 使用这版本的pack
http://www.arterytek.com/download/Pack_Keil_AT32F4xx_CH_V1.3.4.zip

stig3, 2021-08-04:
> @stig3 请使用这版本的pack，新版本的标准库还没有验证过。
> http://www.arterytek.com/download/Pack_Keil_AT32F4xx_CH_V1.3.4.zip

不是这个问题，我之前就是安装的1.3.4，是报一样的问题，然后我去官网下载了1.3.7。还是一样的问题。

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

主要是这里报错
是不是还需要其他的软件包？能不能截一下你们的软件包，我逐个安装排查一下。

FASTSHIFT, 2021-08-04:
@stig3
我是keil v5.25 + v1.3.4标准库

ArtisticZhao, 2021-08-04:
@stig3 我之前见过keil 5.30 编译失败的  要不你换成 keil 5.25 试试。 我5.25编译没有问题

LiangtaoZhong, 2021-08-05:
我之前也遇到了，换个keil版本重装一次。目前5.35没问题

stig3, 2021-08-05:
> 我之前也遇到了，换个keil版本重装一次。目前5.35没问题

谢谢，重找了一台Keil 5.25的电脑编译没问题
就是还不知道具体原因是什么

OuyangIPC, 2021-08-05:
是设置的问题吧，编译器提示某个部件对这个目标不可用

Closed 2021-09-07.

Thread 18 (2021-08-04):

X-Track复位问题以及屏幕背光

LiangtaoZhong, 2021-08-04:
X-Track只有在用keil DEBUG的时候才能复位，但是要点三次run才能复位成功，然后屏幕停在主界面数秒后缓慢熄灭。平时上电则不能复位成功。我朋友的也是这样，不是焊接问题。麻烦了

FASTSHIFT, 2021-08-04:
请检查复位电路是否正确焊接，电容电阻有没有焊反

LiangtaoZhong, 2021-08-05:
> 请检查复位电路是否正确焊接，电容电阻有没有焊反

复位电路没有问题

LiangtaoZhong, 2021-08-05:
屏幕背光解决了，是因为一个二极管焊反了，但是复位问题没有解决

FASTSHIFT, 2021-08-05:
编码器可以正常交互吗，拨动和按压的时候都有操作音

gyy0814, 2021-08-05:
是不是没焊电池啊   要焊上电池才行 usb并不能给芯片供电

LiangtaoZhong, 2021-08-06:
谢谢，问题解决了，是因为boot0虚焊了。

Closed 2021-08-06.

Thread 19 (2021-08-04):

关于充电动画问题

gyy0814, 2021-08-04:
大神您好 我现在用您提供的PCB以及V1.5的程序 制作了这个码表 使用起来很不错 但是 我发现我在充电的时候 屏幕并没有显示充电 在菜单栏里面依旧显示放电 但是电池电压会逐渐升高 充电指示灯也会点亮 但是没有充电动画 这个不知道是我焊接的问题 还是说程序里面没有这个充电检测  大概测量了一下 这个BAT_CHG_DET脚不充电时电压为0.0V 充电时大概为0.3V左右 大概问了一下 好像别人做出了也没有充电动画或者显示 您看看这个大概是什么问题 :D

FASTSHIFT, 2021-08-04:
是有充电动画的，在充电时BAT_CHG_DET(PA11)脚一定是高电平，量出来的0.3v不是正常电压

gyy0814, 2021-08-04:
啊这

gyy0814, 2021-08-04:
不过如果充电时BAT_CHG_DET为高电平 LED就亮不了啊 led是负级连接的CHG_DET

FASTSHIFT, 2021-08-04:
好像也是，电路设计有点小问题。但是程序里确实靠读PA11脚的电平判断的，说明STAT不是完全接地。

gyy0814, 2021-08-04:
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

FASTSHIFT, 2021-08-04:
嗯，正确的做法应该是测量USB_VCC，加两个分压电阻降到3.3V。

gyy0814, 2021-08-04:
而且我看您这个程序好像是靠程序里面电池的百分比来检测是否充电的  为啥不用这个充电芯片的状态脚来检测呢  我个人感觉这个程序里面的百分比在充电时是不太准的  例如我现在90左右的电量 我插入充电  百分比就变成了100 应该是充电时电池电压升高了 导致测出来的不准 此时断开充电器 电量会回落

FASTSHIFT, 2021-08-04:
精确的电量检测需要库仑计，感觉没太大必要为了这个增加成本。

gyy0814, 2021-08-04:
我的意思是 充电动画就不判断电量了 只判断U1的STAT和USB_VCC两个脚 :D

gyy0814, 2021-08-04:
个人认为写成这样更好 然后把IO配置为上拉

gyy0814, 2021-08-04:
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

gyy0814, 2021-08-04:
测试了一下 感觉挺好的 :D

gyy0814, 2021-08-04:
把PA11配置成内部上拉  然后检测IO 为低电平即为充电 高电平即为充满

FASTSHIFT, 2021-08-04:
可以

gyy0814, 2021-08-04:
:D

gyy0814, 2021-08-04:
不知道大佬有没有准备把接口换成type-c 我尝试画了一个 但是本人不太会AD 所以说用立创EDA画了一个 布线乱七八糟的  希望大佬下次更新PCB的时候能考虑换成type-c

gyy0814, 2021-08-04:
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

FASTSHIFT, 2021-08-04:
下一代换Type-C，把调试脚也集成进去，厚度还能减一点。

gyy0814, 2021-08-04:
我把那个烧录排针换成四个贴片了啊哈哈  其实倒是想塞个st-link进去  不过 成本貌似....

gyy0814, 2021-08-04:
送去打板了  但愿不翻车

stig3, 2021-11-18:
看了一下，最新的程序充电检测那边还是没有改成pull-up
导致一直显示正在充电的状态
改成pull-up后充电状态显示正常
建议更新一下程序。

FASTSHIFT, 2021-11-18:
> 看了一下，最新的程序充电检测那边还是没有改成pull-up 导致一直显示正在充电的状态 改成pull-up后充电状态显示正常 建议更新一下程序。

已修复

Closed 2021-08-04.

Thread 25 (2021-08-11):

有可行性的stm32方案吗

Wss-20170929, 2021-08-11:
有可行性的stm32方案吗

FASTSHIFT, 2021-08-11:
ST同封装且引脚兼容的，没有替代方案，因为主频、RAM、FLASH差距都很大。可以用STM32F405试试，但是得重新设计PCB。

dotnfc, 2021-08-11:
[https://www.arterytek.com/download/ARTERY_AT32_MCU_Cross_Reference_Table_EN_V202011.xlsx](可以看看这个官方文档)

FASTSHIFT, 2021-08-11:
@dotnfc
AT32可以替代STM32，但是反过来不一定行，因为AT32的配置更高很多。

dotnfc, 2021-08-11:
的确，AT32 性能高。如果真的考虑换 STM32 的话，我觉得 STM32G4Rx 应该可以。但是太贵，还不好买，现在。

FASTSHIFT, 2021-08-11:
G4的RAM太小（最高128K）。当前程序FLASH占用260K，RAM占用200K。

Closed 2021-09-07.

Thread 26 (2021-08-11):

地图文件的优化

dotnfc, 2021-08-11:
用 1.6 的 java 地图下载器，下载地图后，再用 Tools\TilesConverterForLVGL.exe 工具进行转换，有两个问题：

- 这个工具可否改进一下，可指定输出目录，这样原图 .png 和 .bin 就可以分开，拷贝的时候，文件数量会少一半；
- 再一个，bin 文件一般是 256 * 256 * 2 = 128KB，有点浪费，特别是空图。是不是可以进行一个压缩处理？比如做一个 fs 的 filter。
我看 lv_lib_png 的 blog 说，'width x height x 4 byteRAM' 用 png/split-jpg 似乎 ram 不够。

FASTSHIFT, 2021-08-11:
lv_lib_png需要完整的图片缓冲，在屏幕上显示需要多个tile拼接，目前RAM只有224K，所以无法支持PNG图片。
保留.png图片的原因是为了方便预览，如果不喜欢可以手动删除。
新一代的码表会优化硬件，支持直接解码png图片。

dotnfc, 2021-08-11:
可否预告一下，大概思路？
'优化硬件' 是改 mcu 还是使用 st7789 的特性？

FASTSHIFT, 2021-08-11:
@dotnfc
AT32F435 + PSRAM

dotnfc, 2021-08-11:
了解了。但是，官网没见着 AT32F435 呢？
既然换 mcu，为何不考虑一下 ESP32 呢？

dotnfc, 2021-08-11:
真行。不知道什么时候能拿到样品。

algoideas, 2021-08-18:
新一代支持png直接解码的什么时候发布

Closed 2021-09-07.

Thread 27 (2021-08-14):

地图转换工具TilesConverterForLVGL.exe能否支持下ARGB8888

algoideas, 2021-08-14:
地图转换工具TilesConverterForLVGL.exe能否可以支持下ARGB8888，目前已经在嵌入式Linux设备上移植成功，效果也正常，设备的Linux framebuffer驱动支持ARGB8888（不支持RGB565）

FASTSHIFT, 2021-08-14:
可以分享视频吗？

FASTSHIFT, 2021-09-02:
@algoideas
 如果内存足够，可以考虑直接解码png图片进行显示，使用[lv_lib_png](https://github.com/lvgl/lv_lib_png)，省去转换过程。

Closed 2021-08-14.

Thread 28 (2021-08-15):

关于其他品牌MCU替换的性能需求：主频>150M，RAM>=200K，FLASH>=512K，SPI速度>=50Mbps。  有没有推荐的型号。

Wss-20170929, 2021-08-15:

stig3, 2021-08-16:
stm32f405rgt6

FASTSHIFT, 2021-08-16:
可以参考这个项目:
https://github.com/chenghongyao/X-TRACK

Linjieqiang, 2022-06-14:
SWM32S 系列, 内置 8MB SDRAM, FLASH 512 KB, 应该可以满足?

FASTSHIFT, 2022-06-14:
> SWM32S 系列, 内置 8MB SDRAM, FLASH 512 KB, 应该可以满足?

可以

GetFreedomPro, 2022-07-03:
1.ESP32-S3 搭载 Xtensa 32 位 LX7 双核处理器
2.主频 240 MHz
3.512 KB SRAM
4.8 位 ~16 位并行 RGB,I8080, MOTO6800）, 支持 RGB565
5.支持片外 8M PSRAM

Closed 2024-05-14.

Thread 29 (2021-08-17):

远程定位

mr-BY, 2021-08-17:
希望可以支持远程查看位置和轨迹

FASTSHIFT, 2021-08-17:
远程定位作用的是？防盗？

mr-BY, 2021-08-17:
对，主要是可以查看当前位置

mr-BY, 2021-08-17:
> 远程定位作用的是？防盗？

对，主要是可以查看当前位置

FASTSHIFT, 2021-08-17:
要加防盗功能需要增加防拆设计，现阶段个人觉得研究这个意义不大。

mr-BY, 2021-08-17:
> 要加防盗功能需要增加防拆设计，现阶段个人觉得研究这个意义不大。

可以在丢失后第一时间查看，或许有机会，至少比没有会好一些吧😄

FASTSHIFT, 2021-08-17:
寻找也需要时间，而且在室内能可靠定位也是个问题。
就算是iPhone这种有防丢设计的，也不可能在短时间内找回来。
养成下车就拔码表的习惯，是最好的防丢手段。

mr-BY, 2021-08-17:
好的，不过还是很期待后期可以加入

Closed 2021-08-17.

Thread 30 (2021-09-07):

请教一下获取到经纬度怎么确定瓦片地图tile的path

Yoke365, 2021-09-07:
请教一下知道对应的经纬度怎么确定瓦片地图tile的path，经纬度和tile路径名称的转换关系

FASTSHIFT, 2021-09-07:
https://docs.microsoft.com/en-us/bingmaps/articles/bing-maps-tile-system?redirectedfrom=MSDN
https://github.com/FASTSHIFT/X-TRACK/blob/main/Software/X-Track/USER/App/Utils/MapConv/MapConv.cpp

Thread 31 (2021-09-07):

Software/X-Track/MDK-ARM/Objects应该放到.gitignore吧？

zinwalin, 2021-09-07:
https://github.com/mrshrdlu/gitignore-keil/blob/master/keil.gitignore

FASTSHIFT, 2021-09-07:
Objects里有编译好的HEX，其他文件已清掉了。个人感觉没必要添加gitignore。

zinwalin, 2021-09-07:
一编译都是五百多个文件untracked，你那边可能不影响。

_VIFEXTech ***@***.***>于2021年9月7日 周二上午10:37写道：

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
--
-- Michael Lin Sent from mobile phone

FASTSHIFT, 2021-09-07:
明白你的意思了，回头我加上。

Closed 2021-09-07.

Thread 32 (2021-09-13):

HAL部分代码和STM32F4的std_periph_driver不兼容啊

shawnchain, 2021-09-13:
RT

FASTSHIFT, 2021-09-13:
往什么芯片移植，怎么修改的，报什么错，请详细说明。

shawnchain, 2021-09-14:
我想迁移到STM32F4，比对了Arduino-For-Keil项目里面的F4部分对应的Core/ArduinoAPI的代码，发现和这个项目中的代码有所出入。虽然这个版本KeilDuino版本是220，但是似乎代码逻辑更新一些。
请问有啥区别？
PS：我目前拿F429Discovery做开发板。

FASTSHIFT, 2021-09-14:
涉及到Arduino API的代码没有太大区别。但是涉及标准库的部分要重新自己写。

Closed 2021-09-14.

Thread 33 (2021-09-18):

可以详细介绍一下LVGL的UI界面设计吗，新手入门感觉难度比较大

gzyz9, 2021-09-18:

FASTSHIFT, 2021-09-18:
lvgl官方文档：
https://docs.lvgl.io/master/index.html

lvgl模拟器：
windows: https://github.com/lvgl/lv_sim_visual_studio
linux: https://github.com/lvgl/lv_sim_eclipse_sdl

gzyz9, 2021-09-18:
已经下载了模拟器，也写过最简单那种汽车仪表盘界面，想学习一下这个项目的ui设计逻辑框架，不知道是否有相关介绍文档

FASTSHIFT, 2021-09-18:
这个目前还没有写文档，设计时借鉴了MVP和iOS - ViewController的思路，可以结合代码的注释和[Template](https://github.com/FASTSHIFT/X-TRACK/tree/main/Software/X-Track/USER/App/Pages/_Template)学习一下。

gzyz9, 2021-09-18:
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
所有的ui相关都在这部分文件里面吗

FASTSHIFT, 2021-09-18:
这个是模拟器，应用层代码在`USER/App`

Closed 2022-06-15.

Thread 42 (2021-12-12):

请问缓存一个页面是在哪里实现的？

priceee, 2021-12-12:
大佬你好，我在学习你的PageManager代码，我看到当SwitchTo一个页面时，会判断这个页面的isCached是否为真，若为真，则更改状态为WILL_APPEAR，这时就会设置该页面可见并启动页面切换动画。而若isCached为假，则会进入LOAD状态，这时会创建页面的root并执行onViewLoad()；
我想问一下此处的Cached是指什么？我为什么没有找到具体的执行某个函数将某个页面Cach的代码，只是看到有些地方将isCached赋值为真，有些地方将isCached赋值为假。
不知道我能不能说明白我的意思，希望大佬能解答我的疑惑。

FASTSHIFT, 2021-12-12:
在这边解答https://github.com/FASTSHIFT/X-TRACK/issues/43

Closed 2021-12-12.

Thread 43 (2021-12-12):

请问缓存一个页面是在哪里实现的？

priceee, 2021-12-12:
大佬你好，我在学习你的PageManager代码，我看到当SwitchTo一个页面时，会判断这个页面的isCached是否为真，若为真，则更改状态为WILL_APPEAR，这时就会设置该页面可见并启动页面切换动画。而若isCached为假，则会进入LOAD状态，这时会创建页面的root并执行onViewLoad()；
我想问一下此处的Cached是指什么？我为什么没有找到具体的执行某个函数将某个页面Cach的代码，只是看到有些地方将isCached赋值为真，有些地方将isCached赋值为假。
不知道我能不能说明白我的意思，希望大佬能解答我的疑惑。

FASTSHIFT, 2021-12-12:
cache的意思是当此页面退出时，不删除页面，而且将页面隐藏。当页面重新进入时，页面可以还原之前退出时的状态。

cache功能是可配置的：
* `SetCustomCacheEnable()` 设置自定义cache使能 (默认关闭)，用户手动管理页面的生命周期，页面不会被调度器自动删除。
* `SetCustomAutoCacheEnable()` 设置自动cache使能 (默认打开)，由调度器自动管理页面的声明周期：当push页面时，上一个页面的cache被打开；当页面pop时，被退出页面cache失能，页面被彻底删除。

注意，这两个函数推荐在`onCustomAttrConfig()`里进行调用，cache有关配置的请求在这里被同步到调度器中，**不要直接访问cache相关标志位**，可能会导致内存泄漏。

priceee, 2021-12-12:
谢谢大佬!

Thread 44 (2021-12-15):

想请教一些有关于时钟的问题

eternityqjl, 2021-12-15:
您好，我在研究这个项目的DataProc的部分遇到一些疑问，想请教一下。系统上电初始化后Clock通过GPS (TzConv) 矫正RTC时钟，但矫正过程中DP_TzConv中首先更新了ArduinoTime库中的时间，然后使用ArduinoTime库中的时间返回给Clock。而之后的Recorder模块中直接通过Clock从RTC获取时间，那ArduinoTime库的时间还会在哪里用到呢？其他应用中为什么不直接使用RTC时间呢？

FASTSHIFT, 2021-12-15:
ArduinoTime库主要是用来做时区转换，把UTC时间换算成北京时间，RTC校正后就不会被调用了。

eternityqjl, 2021-12-15:
>

嗯嗯明白了，感谢。

eternityqjl, 2021-12-18:
还可以请教一下lvgl响应编码器按键和滚动的代码在哪里吗？我只看到在page中把组件加入了和input device相同的group，不太清楚lvgl是怎么调用page的onEvent的。

FASTSHIFT, 2021-12-18:
input事件上通过group自动转发到控件上的。page的onEvent触发时，表示控件已经接收到事件了，用户只需关心如何响应事件就好了。

Closed 2021-12-15.

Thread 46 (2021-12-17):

Help to convert this snippet to LVGL v7

bosiden, 2021-12-17:
Hi,
Can anyone help me get this snippet converted to lvgl v7? I spent a lot of time trying to port it to v7 but I couldn't get the scrolling and animation working.

```ruby
#define ITEM_HEIGHT_MIN   100
#define ITEM_PAD          ((LV_VER_RES - ITEM_HEIGHT_MIN) / 2)

void SystemInfosView::Create(lv_obj_t* root)
{
    lv_obj_remove_style_all(root);
    lv_obj_set_size(root, LV_HOR_RES, LV_VER_RES);
    lv_obj_set_style_bg_color(root, lv_color_black(), 0);
    lv_obj_set_style_bg_opa(root, LV_OPA_COVER, 0);
    lv_obj_set_style_pad_ver(root, ITEM_PAD, 0);

    lv_obj_set_flex_flow(root, LV_FLEX_FLOW_COLUMN);
    lv_obj_set_flex_align(
        root,
        LV_FLEX_ALIGN_START,
        LV_FLEX_ALIGN_START,
        LV_FLEX_ALIGN_CENTER
    );

    Style_Init();

    /* Item Sport */
    Item_Create(
        &ui.sport,
        root,
        "Sport",
        "bicycle",

        "Total trip\n"
        "Total time\n"
        "Max speed"
    );

    /* Item GPS */
    Item_Create(
        &ui.gps,
        root,
        "GPS",
        "map_location",

        "Latitude\n"
        "Longitude\n"
        "Altitude\n"
        "UTC Time\n\n"
        "Course\n"
        "Speed"
    );

    /* Item MAG */
    Item_Create(
        &ui.mag,
        root,
        "MAG",
        "compass",

        "Compass\n"
        "X\n"
        "Y\n"
        "Z"
    );

    /* Item IMU */
    Item_Create(
        &ui.imu,
        root,
        "IMU",
        "gyroscope",

        "Step\n"
        "Ax\n"
        "Ay\n"
        "Az\n"
        "Gx\n"
        "Gy\n"
        "Gz"
    );

    Group_Init();
}

void SystemInfosView::onFocus(lv_group_t* g)
{
    lv_obj_t* icon = lv_group_get_focused(g);
    lv_obj_t* cont = lv_obj_get_parent(icon);
    lv_coord_t y = lv_obj_get_y(cont);
    lv_obj_scroll_to_y(lv_obj_get_parent(cont), y, LV_ANIM_ON);
}

void SystemInfosView::Style_Init()
{
    lv_style_init(&style.icon);
    lv_style_set_width(&style.icon, 220);
    lv_style_set_bg_color(&style.icon, lv_color_black());
    lv_style_set_bg_opa(&style.icon, LV_OPA_COVER);
    lv_style_set_text_font(&style.icon, ResourcePool::GetFont("bahnschrift_17"));
    lv_style_set_text_color(&style.icon, lv_color_white());

    lv_style_init(&style.focus);
    lv_style_set_width(&style.focus, 70);
    lv_style_set_border_side(&style.focus, LV_BORDER_SIDE_RIGHT);
    lv_style_set_border_width(&style.focus, 2);
    lv_style_set_border_color(&style.focus, lv_color_hex(0xff931e));

    static const lv_style_prop_t style_prop[] =
    {
        LV_STYLE_WIDTH,
        LV_STYLE_PROP_INV
    };

    static lv_style_transition_dsc_t trans;
    lv_style_transition_dsc_init(
        &trans,
        style_prop,
        lv_anim_path_overshoot,
        200,
        0,
        nullptr
    );
    lv_style_set_transition(&style.focus, &trans);
    lv_style_set_transition(&style.icon, &trans);

    lv_style_init(&style.info);
    lv_style_set_text_font(&style.info, ResourcePool::GetFont("bahnschrift_13"));
    lv_style_set_text_color(&style.info, lv_color_hex(0x999999));

    lv_style_init(&style.data);
    lv_style_set_text_font(&style.data, ResourcePool::GetFont("bahnschrift_13"));
    lv_style_set_text_color(&style.data, lv_color_white());
}

void SystemInfosView::Item_Create(
    item_t* item,
    lv_obj_t* par,
    const char* name,
    const char* img_src,
    const char* infos
)
{
    lv_obj_t* cont = lv_obj_create(par);
    lv_obj_remove_style_all(cont);
    lv_obj_set_width(cont, 220);

    lv_obj_clear_flag(cont, LV_OBJ_FLAG_SCROLLABLE);
    item->cont = cont;

    /* icon */
    lv_obj_t* icon = lv_obj_create(cont);
    lv_obj_remove_style_all(icon);
    lv_obj_clear_flag(icon, LV_OBJ_FLAG_SCROLLABLE);

    lv_obj_add_style(icon, &style.icon, 0);
    lv_obj_add_style(icon, &style.focus, LV_STATE_FOCUSED);
    lv_obj_set_style_align(icon, LV_ALIGN_LEFT_MID, 0);

    lv_obj_set_flex_flow(icon, LV_FLEX_FLOW_COLUMN);
    lv_obj_set_flex_align(
        icon,
        LV_FLEX_ALIGN_SPACE_AROUND,
        LV_FLEX_ALIGN_CENTER,
        LV_FLEX_ALIGN_CENTER
    );

    lv_obj_t* img = lv_img_create(icon);
    lv_img_set_src(img, ResourcePool::GetImage(img_src));

    lv_obj_t* label = lv_label_create(icon);
    lv_label_set_text(label, name);
    item->icon = icon;

    /* infos */
    label = lv_label_create(cont);
    lv_label_set_text(label, infos);
    lv_obj_add_style(label, &style.info, 0);
    lv_obj_align(label, LV_ALIGN_LEFT_MID, 75, 0);
    item->labelInfo = label;

    /* datas */
    label = lv_label_create(cont);
    lv_label_set_text(label, "-");
    lv_obj_add_style(label, &style.data, 0);
    lv_obj_align(label, LV_ALIGN_CENTER, 60, 0);
    item->labelData = label;

    lv_obj_move_foreground(icon);

    /* get real max height */
    lv_obj_update_layout(item->labelInfo);
    lv_coord_t height = lv_obj_get_height(item->labelInfo);
    height = LV_MAX(height, ITEM_HEIGHT_MIN);
    lv_obj_set_height(cont, height);
    lv_obj_set_height(icon, height);
}

```

FASTSHIFT, 2021-12-18:
@bosiden
For better support, I recommend upgrading from LVGL V7 to LVGL V8.

bosiden, 2021-12-20:
> @bosiden
> For better support, I recommend upgrading from LVGL V7 to LVGL V8.

Thanks, I ended up upgrading my project to V8, Cheers.

Closed 2021-12-20.

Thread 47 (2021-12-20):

请问如果需要更换软件I2C的GPIO口需要如何修改才行？

bbear2, 2021-12-20:
你好，我这边在查看代码后发现代码中的I2C是使用的软件模拟的，我在自己的设计中由于一些其他原因需要更换I2C的IO口。
具体是从PB6/PB7更换为PB8/PB9。
我的具体做法是修改mcu_config.h中的WIRE_SDA_PIN/WIRE_SCL_PIN的内容。但是我发现修改后无法正常产生I2C波形。
期间我尝试过打开WIRE_USE_FULL_SPEED_I2C宏，这样虽然有波形了，但是用逻辑分析仪抓取波形后发现波形不对劲，另外也和我的外设无法通讯。另外我也尝试在关闭WIRE_USE_FULL_SPEED_I2C的情况下修改IO口的输出类型为OUTPUT(原始代码是OUTPUT_OPEN_DRAIN)，这样修改后也能产生波形，但是依旧通讯失败。
同一个外设，我在使用PB6/PB7时是可以正常通讯的。

因此这里想请教下是不是我有漏了什么需要修改的地方？
期待回复~

bbear2, 2021-12-20:
重复提交了，关闭多余的

Closed 2021-12-20.

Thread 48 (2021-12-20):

请问如果需要更换软件I2C的GPIO口需要如何修改才行？

bbear2, 2021-12-20:
你好，我这边在查看代码后发现代码中的I2C是使用的软件模拟的，我在自己的设计中由于一些其他原因需要更换I2C的IO口。
具体是从PB6/PB7更换为PB8/PB9。
我的具体做法是修改mcu_config.h中的WIRE_SDA_PIN/WIRE_SCL_PIN的内容。但是我发现修改后无法正常产生I2C波形。
期间我尝试过打开WIRE_USE_FULL_SPEED_I2C宏，这样虽然有波形了，但是用逻辑分析仪抓取波形后发现波形不对劲，另外也和我的外设无法通讯。另外我也尝试在关闭WIRE_USE_FULL_SPEED_I2C的情况下修改IO口的输出类型为OUTPUT(原始代码是OUTPUT_OPEN_DRAIN)，这样修改后也能产生波形，但是依旧通讯失败。
同一个外设，我在使用PB6/PB7时是可以正常通讯的。

因此这里想请教下是不是我有漏了什么需要修改的地方？
期待回复~

FASTSHIFT, 2021-12-21:
检查是否为PB8/PB9添加了上拉电阻(3.3K~10K)，或者发生了短路。
在主频较高时，不建议打开`WIRE_USE_FULL_SPEED_I2C`，器件不一定能追上。I2C必须使用`OUTPUT_OPEN_DRAIN`开漏输出，不要使用推挽输出。

bbear2, 2021-12-21:
> 检查是否为PB8/PB9添加了上拉电阻(3.3K~10K)，或者发生了短路。 在主频较高时，不建议打开`WIRE_USE_FULL_SPEED_I2C`，器件不一定能追上。I2C必须使用`OUTPUT_OPEN_DRAIN`开漏输出，不要使用推挽输出。

我有为这两个引脚添加4.7k的上拉电阻，另外可以确认两个引脚没有短路。

FASTSHIFT, 2021-12-21:
使用以下代码检查是否可以正常翻转IO(两边是一个相反的方波)

```c
pinMode(PB8, OUTPUT_OPEN_DRAIN);
pinMode(PB9, OUTPUT_OPEN_DRAIN);

digitalWirte(PB8, LOW);
digitalWirte(PB9, HIGH);

while(1)
{
    togglePin(PB8);
    togglePin(PB9);
    delay(100);
}
```

FASTSHIFT, 2021-12-21:
我这边测试的更换PB8/PB9通信是正常的，请继续排查硬件问题。

bbear2, 2021-12-21:
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

我有用c代码测试过这个反向的方波，看波形是正常的。仔细回忆了下，我在单步调试的时候发现一个异常点，当io口电平被置高时，io口的电压好像是1.8v，好像应该是3.3v才对

bbear2, 2021-12-21:
> 我这边测试的更换PB8/PB9通信是正常的，请继续排查硬件问题。

非常感谢你帮忙实际测试，我仔细检查后大致确认是硬件问题，后面做好新板子了再进一步测试。

Closed 2021-12-21.

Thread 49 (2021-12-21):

V2.1开机黑屏问题

jppang, 2021-12-21:
器件组合：

|GPS |IMU |MAG |开机|
|-----|------|------|-----|
|无     |   无     |  无      | 正常|
|无       | 有       |无       | 黑屏|
|有       | 无     | 无       |正常|
|有       | 有     |  无     |  黑屏|

另外使用V1.9版本的固件在上面的组合都开机正常。
请问各位有遇到相似的问题吗？

FASTSHIFT, 2021-12-21:
重新拉份代码，这个加处理了。

jppang, 2021-12-22:
更新新版固件后，已经可以正常开机了。
感谢。

Closed 2021-12-22.

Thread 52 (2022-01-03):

显示屏功耗问题

jppang, 2022-01-03:
X-TRACK在外面使用一段时间之后，SD卡壳有点烫手。
做了以下的基本功耗量测。所有的量测都是在USB接口5V供电且未接电池的前提之下：

|器件组合   | 电流|
|---|---|
|完整X-TRACK  |  210 mA |

完整X-TRACK是指：CH340E+MCP73831+LP5907+MCU+IMU+SD+ENCODER+GPS+显示屏。

拆解功耗量测结果如下：

|器件组合 |   电流|
|---|---|
|完整X-TRACK去掉GPS |   190 mA|
|完整X-TRACK去掉显示屏 |   60 mA|
|完整X-TRACK去掉显示屏、GPS | 40 mA|

也就是说显示屏的电流功耗为150 mA。
以3颗LED的标准电流值是60 mA来说应该是太大了。
上面的电流值是在背光控制电路原理图当中的R12=10欧姆的状况之下。
用手边有的电阻更换之后量测如下：

|器件组合 |  电流|
|---|---|
|完整X-TRACK@R12=10欧姆  | 210 mA|
|完整X-TRACK@R12=27欧姆 |  110 mA|

这样换算一下，如果显示屏的背光驱动电流要60 mA的话，再加上驱动IC的功耗需求，
那么R12的电阻值应该在20～25欧姆之间即可。
使用R12=27欧姆的X-TRACK在阳光下并无大碍，可用。
不知大家有没有遇到过相同的问题？

FASTSHIFT, 2022-01-03:
几点小建议：
* 1.不建议边充边用，因为会增加充电芯片负担。
* 2.功耗测量以电池输出端测更合适，个人测试正常使用电流100mA左右。
* 3.可以通过调节PWM来控制显示屏亮度，并不需要修改阻值

jppang, 2022-01-03:
感谢你的建议。
再补充一点，上面的量测值是在没有接电池的状况之下的。
电池输出端的电流量测我再来试看看。

jppang, 2022-01-04:
用万用表从电池端的量测结果如下：

|器件组合 |  电流 |
|---|---|
|完整X-TRACK@R12=10欧姆 |   大于200 mA |
|完整X-TRACK@R12=27欧姆 |  140 mA |

手边的万用表的电流档位最高到200 mA。
看起来数值远大于版主的。
我再来排查是否我的电源电路有问题。

Closed 2022-01-09.

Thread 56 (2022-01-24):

请问有使用开源工具的计划吗？

jppang, 2022-01-24:
如题，这个专案的开发有使用开源工具的可能性吗？
固件：Visual Studio Code + Platformio ?

FASTSHIFT, 2022-01-24:
暂时没有，目前主线还是以Keil为主，调试方便一点，ARMCC编译出来的代码运行速度也快一些。

jppang, 2022-01-24:
了解。
有点可惜了。
这么好的开源专案却只能使用AD+Keil。
硬体部分我尝试用开源工具KiCad重新画了原理图跟PCB，最近好不容易搞定了。
固件部分想尝试是否能用VS Code+Platformio的方式来复制，不过ARTERY好像在Platformio里面没有BSP这些支援，不知版主有没有建议的做法？在VS Code+Platformio平台上。

FASTSHIFT, 2022-01-24:
雅特力的pack中有标准库源码，直接将源码复制出来与一起参与编译。

jppang, 2022-01-24:
了解。
谢谢版主的建议。

wc7086, 2022-04-22:
> 如题，这个专案的开发有使用开源工具的可能性吗？ 固件：Visual Studio Code + Platformio ?
PlatformIO还是不够完善，我打算使用 GNU Arm Embedded Toolchain 、make 、OpenOCD 交叉编译，目前在尝试使用这几个工具。

jppang, 2022-04-23:
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

感谢建议。

FASTSHIFT, 2022-04-23:
更新了一个Linux平台的移植 https://github.com/FASTSHIFT/X-TRACK/commit/ef456bcb1c87f9dfcd0c3ab3b819614036129460 ，可以试试。

jppang, 2022-08-06:
尝试将X-Track源码使用VisualStudio Code和Platformio用Arduino平台移植到ESP32。

经过一番折腾，终于成功编译产生固件了，然而一启动，画面却呈现破碎的状态。

如下的照片所示：
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

现在还在查找是硬件设计还是固件参数设定问题。不知有能看出问题点的能给建议吗？先感谢了！

我的源码在这里：https://github.com/jppang/ESP32_X-Track.git

软件夹里面有firmware档案夹，里面有固件。我使用的是ESP32 WROOM 32E模组整合在自己设计的开发板内，照片内的显示屏是240x280分辨率的，一样是ST7789驱动IC。相同的硬件来试lvgl的一些范例看起来都不会有画面破碎的现象。
HAL_Display跟lv_port_disp里面的源码我是整个改写了，使用的是TFT_eSPI的库，用double buffer启用DMA。其实用double buffer或single buffer，启用或不启用DMA都没有影响启动画面破碎的问题，只是描绘快慢问题而已。

手边如果有ESP32开发板和显示模组的同好如果有兴趣的话可否能尝试一下是否有相同现象？管脚设定在/lib/HAL/HAL_Config.h里面。

FASTSHIFT, 2022-08-06:
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

试试用240*280分辨率跑一下

FASTSHIFT, 2022-08-06:
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

jppang, 2022-08-06:
昨天晚上终于找到导致画面破碎的问题点了。

原来是用TFT_eSPI库改写HAL_Display与lv_port_disp这两个源码其中设定描绘位置的setAddrWindow这个方法的引数，
Adafruit的库是定义左上角与右下角坐标，TFT_eSPI库是定义左上角坐标与宽长。由于方法名称与引数数目一摸一样，就放过没有改到，导致了这个查找好久甚至还求救各位的窘境。

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

上面的照片是换成240X240屏的组态，不过画面破碎问题跟屏的分辨率无关，是在找到上面的问题点之前怀疑所有可能的原因之下将240X280的屏换成240X240的。

不过，上面的画面周围有一圈白线，个别组件也有位移的状况。这个在用雅特力单片机与V2.1固件的时候是没有看到的，上面ESP32是用V2.7版源码，APP夹里面我都没有更动到。看来还有课题待解决了。

感谢版主的建议，谢谢。

FASTSHIFT, 2022-08-07:
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

白色边框和偏移是默认主题设置的pad和border导致的，关闭`lv_conf.h`中的`LV_USE_THEME_DEFAULT`即可。

jppang, 2022-08-07:
依版主的建议，修改lv_conf.h的设定后画面就正常了。

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

感谢版主的建议！

Closed 2024-05-14.

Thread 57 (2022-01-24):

switch 组件无法显示的问题？

bbear2, 2022-01-24:
你好。
我在使用模拟器进行开发时需要用到[switch](https://docs.lvgl.io/master/examples.html#simple-switch)这个组件。经过初步调试，代码可以正常工作，点击后event事件能够正常响应。
但是在屏幕上没有显示对应的组件，我尝试调整过不通的背景颜色，均无法显示该控件。
想请问下需要做什么工作才能让switch组件正常显示？
感谢~

bbear2, 2022-01-24:
> X-TRACK默认关闭了主题，所有控件默认样式都是透明的，可以尝试将`lv_conf.h`中的`LV_USE_THEME_DEFAULT`设置为1，重新启用默认样式。

刚刚测试了，可以正常显示了。
非常感谢~

Neomaic, 2022-01-28:
我的vs模拟器出现9个连接错误，无法运行

Closed 2022-01-24.

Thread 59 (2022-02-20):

X-TRACK技术交流微信群

Stonekity, 2022-02-20:
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

Stonekity, 2022-02-20:
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

Stonekity, 2022-02-20:
作者大佬，已经入群哦

Stonekity, 2022-02-28:
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

Stonekity, 2022-03-08:
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

kakajay, 2022-03-18:
> 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

大佬能传个新的二维码吗

johncruz-1, 2022-03-30:
最新

Stonekity, 2022-03-31:
#
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

ZhangBenChuang, 2022-04-09:
最新

Stonekity, 2022-04-10:
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

Stonekity, 2022-04-18:
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

Stonekity, 2022-08-27:
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

zhangningboo, 2022-12-05:
放个新二维码

Stonekity, 2022-12-05:
> 放个新二维码

已更新

317oldcaptain, 2022-12-13:
老哥需要更新一下二维码

Stonekity, 2022-12-13:
> 老哥需要更新一下二维码

已更新

JoyDaDa, 2022-12-27:
老哥求更新二维码

Stonekity, 2022-12-27:
> 老哥求更新二维码

> 老哥求更新二维码

已更新

Stonekity, 2022-12-27:
> 老哥求更新二维码

已更新

17367077569, 2023-02-02:
需更新

FanZB, 2023-03-14:
> 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

老哥，求更新

FanZB, 2023-03-14:
老哥，求更新二维码

chyouZA, 2023-08-29:
微信群还在吗？能不能更新下二维码？

Stonekity, 2023-08-29:
更新✅

Stonekity, 2023-09-17:
微信群200即将满员，需要加入的小伙伴请添加微信号 robot-xnn，邀请入群

HASACI, 2023-12-10:
可以更新一下吗

monkeywq, 2024-07-24:
能更新下二维码吗

w6c6x6, 2024-10-22:
老哥求更新二维码

Druidss, 2025-02-20:
求更新

daxiangpanda, 2025-06-12:
求更新

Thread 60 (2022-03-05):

请问在Power Off的状态之下充电完成时LED灯会熄灭吗？

jppang, 2022-03-05:
如题请问版主我的状况是充电完成后LED灯都不会熄灭。
但是如果把单片机解焊后，充电完成时LED灯就会熄灭了。
请问各位有遇到相同的问题吗？

量测BAT_CHG_DET这根信号的电压值如下：

| 状态 | Power ON | Power OFF |
|-----|-----|----|
|充电下 | 0.8V | 2V |
|未充电 | 3.3V | 0V |

jppang, 2022-03-15:
经过实验串接一个diode可以解决这个问题。

Closed 2022-03-15.

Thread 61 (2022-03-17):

消息订阅发布框架使用中遇到的问题咨询

bbear2, 2022-03-17:
你好，我这边想参考IMU数据的传输流程新建一个sensor数据的传输。但是在仿真时遇到问题。

添加步骤描述如下：
我在HAL层增加了对sensor的HAL层操作，同时在HAL层添加了相关的update函数周期性的向Datacenter提交数据。
然后是在DataProc中参考IMU的添加了DP_sensor.cpp文件，也在HAL_Def.h中添加了Datacenter中sensor数据类型的结构定义。还有在DP_LIST.inc中添加了sensor的相关代码。
最后是界面获取Datacenter的数据，我在Init函数中创建了一个account,然后添加了一个订阅者。最后在需要获取数据的地方通过Pull操作获取相关数据。

当我在visual studio中进行仿真时，每次都会在DataCenter.cpp中的Find函数处报错。具体如下图：
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

下面是我做过的调试工作：
1 通过单步调试发现，程序是在进入到App_Init();后的while循环中的lv_timer_handler();后崩溃的。具体是下面箭头标出的这行代码：
```
            next = _lv_ll_get_next(&LV_GC_ROOT(_lv_timer_ll), LV_GC_ROOT(_lv_timer_act));

            if(lv_timer_exec(LV_GC_ROOT(_lv_timer_act))) {//<<<<<<<<<<<<<<<---------------------
                /*If a timer was created or deleted then this or the next item might be corrupted*/
                if(timer_created || timer_deleted) {
```
2 考虑到代码是在datacenter相关的代码中发生异常的，我尝试寻找调用了Find函数的代码。
发现在我注释掉界面中的Pull函数后，该异常会消失。通过查看代码发现，Pull函数中也的确有
调用Find函数。于是我尝试恢复调用Pull函数并加上断点，但是程序运行过程中没有停在该断点处，
最后还是发生了异常。

基于以上情况，我想了解下是否是我在添加代码的过程中有什么纰漏导致了这个错误。
热切期盼你们的回复。

FASTSHIFT, 2022-03-18:
代码和发生错误的调用栈发一下

bbear2, 2022-03-18:
你好，相关代码我已经上传到了这个[仓库](https://github.com/bbear2/X-TRACK/tree/datacenter_issue_debug)里面，
使用的是datacenter_issue_debug分支。可以直接运行其中的仿真器代码复现问题。

另外关于异常时的调用栈，我这边截了图，供你们参考：
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

FASTSHIFT, 2022-03-18:
Model没初始化，访问了account野指针。
建议改成这样：
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

FASTSHIFT, 2022-03-18:
在Ninebot上班？

bbear2, 2022-03-18:
非常感谢答复，刚刚验证过了没有问题。
哈哈哈，我不是ninebot员工，是我自己基于ninebot做的一个改装。

Closed 2022-03-18.

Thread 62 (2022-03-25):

PageManager::Install相关问题

pockrt-m, 2022-03-25:
大佬好，我在`App.cpp`代码段中发现一次性加载了所有的page`manager.Install`，实际应用中发现这种操作会占用较多堆栈（我使用的单片机可操作堆栈较少），此处能否修改当某一page即将加载时在对其Install，随后page消失后对其Uninstall，尽可能减少堆栈的占用。如果可以该怎么操作？能否提供一个思路？

FASTSHIFT, 2022-03-26:
Install/Uninstall支持动态安装和卸载

pockrt-m, 2022-03-27:
请问是否还能从其他地方对程序进行精简呢，感觉这一套页面生命周期和订阅发布框架对内存占用较高，之前单纯使用LVGL可以同时使用SD卡和httpCilent，但是将其中的HAL驱动移植到本项目中后httpCilent便会报错`Memory allocation failed`，请大佬指点

FASTSHIFT, 2022-03-28:
有多少内存？
框架本身其实不太吃内存，可以先尝试把page cache关了。

pockrt-m, 2022-03-28:
我用的是ESP32，使用的是稚晖君peak的代码进行修改的；
之前一直用的Arduino IDE，因为能跑通就没太关注内存占用；
现在所有用到的page全部都`SetCustomCacheEnable(false)`；
目前使用`ESP.getFreeHeap()`函数获取空闲堆，如果不启用SD卡，`http.get()`操作前空闲堆为`126920`，操作后为`81608`；
如果开启SD卡，`http.get()`操作前空闲堆为`99472`，操作后为`98336`；
实测如果`http.get()`操作前空闲堆低于`110000`是不能成功的，只有大于`125000`的时候才能够百分百成功。

FASTSHIFT, 2022-03-28:
内存池使用太极限了，当碎片一多就很容易申请失败，系统稳定性无法保证。对于速度不敏感的地方考虑用PSRAM。

FASTSHIFT, 2022-03-28:
一个PageBase占用的内存只比一个lv_obj_t多十几个字节，远远比不上文件系统和协议栈的heap开销。可以用sizeof量一下你的Page类的内存占用，如果觉得占用较多，考虑使用动态分配用户数据。但是还是建议优先解决文件系统和协议栈内存开销过大的问题。

pockrt-m, 2022-03-29:
感谢，这部分计划加入PSRAM来解决了；
还想请问`AccountSystem::xxx_Commit(&xxx_info)`这一部分是需要在指定时间内刷新嘛，如果未在指定时间内刷新会出问题？若不刷新能否维持上一次的结果？

FASTSHIFT, 2022-03-29:
如果没有新的Commit提交，调用Pull会返回失败，需要在发起Pull那一端自己做个cache。

FASTSHIFT, 2022-04-28:
PSRAM只有SRAM十分之一的性能，不适合放draw buffer。如果追求帧率，考虑更换SRAM更大的MCU。

Closed 2022-06-15.

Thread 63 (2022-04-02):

结构与 PCB 形状如何完美耦合

zhbi98, 2022-04-02:
大佬我想问个问题，就是我知道使用建模软件导出外壳 DXF 文件提供给 PCB 可以约定 PCB 板子的形状，我知道底面怎么做但是侧面怎么办？所以我的疑问是怎么通过导入结构设计文件的方式使得外壳侧边开口和 PCB 上接口位置对应起来。（比如外壳侧边 USB 开口和 PCB 板子上的 USB 接口契合）

clz5100, 2022-04-16:
>
AD导出STP文件，然后在建模软件里面设计就行了

zhbi98, 2022-04-16:
> >
> 谢谢你的回答
> AD导出STP文件，然后在建模软件里面设计就行了

Closed 2022-04-16.

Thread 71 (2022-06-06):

中文加载问题

xiaoyi-hub, 2022-06-06:
您好，我用lvgl官方工具生成一些中文字体后用ResourceManager管理却无法显示中文？有解决方法吗

FASTSHIFT, 2022-06-06:
代码的文件编码用UTF8

xiaoyi-hub, 2022-06-06:
我用官方的工具生成的也是UTF8格式的，，字库直接定义在lv_config.h文件的宏是可以正常显示中文的[#define LV_FONT_CUSTOM_DECLARE LV_FONT_DECLARE(font_bahnschrift_18)],然而我把它添加至ResourceManager却无法显示，报的错误是 not found for U+4BB ，在生成的字库中所显示的字体对应的是U+4E00。是不是ResourceManager中Vector容器添加中文字模后再读出来会出了问题？(生成的字库文件除了中文其他数字和英文都是正常的)

FASTSHIFT, 2022-06-06:
ResourceManager其实就是一个简单的key-value匹配，是不是请求字体key的时候没有请求成功，返回了默认字体。

xiaoyi-hub, 2022-06-06:
请求成功了，字库中的英文和数字都显示正常，只有中文显示异常，楼主有空可以测试一下吗

xiaoyi-hub, 2022-06-07:
我可以确认生成的字库没有问题，你看如下图
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

我用自己生成的字库直接替换工程的font_bahnschrift_17，直接搞了一个demo中文显示是正常的

如下是运行x-track加载自己制作的中文字库运行结果
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

###
昨天我做了很多测试
1.我用一个网友移植好的lvgl vs工程直接添加制作的中文字库也可以正常显示
2.把pageManager ResourceManager 单独抽出来移植到1的工程中，中文也显示正常
这问题太诡异，不知道为啥。我给你发附带的字库，楼主有空看一下
###
/*******************************************************************************
 * Size: 18 px
 * Bpp: 4
 * Opts:
 ******************************************************************************/

#ifdef LV_LVGL_H_INCLUDE_SIMPLE
#include "lvgl.h"
#else
#include "lvgl/lvgl.h"
#endif

#ifndef FONT_BAHNSCHRIFT_18
#define FONT_BAHNSCHRIFT_18 1
#endif

#if FONT_BAHNSCHRIFT_18

 /*-----------------
  *    BITMAPS
  *----------------*/

  /*Store the image of the glyphs*/
static LV_ATTRIBUTE_LARGE_CONST const uint8_t glyph_bitmap[] = {
    /* U+0020 " " */

    /* U+0021 "!" */
    0x9f, 0x58, 0xf4, 0x8f, 0x37, 0xf2, 0x6f, 0x25,
    0xf1, 0x4f, 0x4, 0xf0, 0x3e, 0x2, 0xe0, 0x0,
    0x1, 0x31, 0xaf, 0x5a, 0xf5,

    /* U+0022 "\"" */
    0xbd, 0xe, 0xa9, 0xb0, 0xc8, 0x99, 0xc, 0x68,
    0x80, 0xa5,

    /* U+0023 "#" */
    0x0, 0x2f, 0x0, 0xb6, 0x0, 0x4, 0xd0, 0xd,
    0x40, 0x0, 0x6b, 0x0, 0xf2, 0x1, 0x18, 0xa1,
    0x2f, 0x20, 0xaf, 0xff, 0xff, 0xff, 0x73, 0x4c,
    0x94, 0x8e, 0x42, 0x0, 0xd4, 0x6, 0xb0, 0x1,
    0x2f, 0x32, 0xa9, 0x20, 0xaf, 0xff, 0xff, 0xff,
    0x73, 0x8e, 0x55, 0xe8, 0x52, 0x5, 0xc0, 0xe,
    0x30, 0x0, 0x7a, 0x0, 0xf1, 0x0, 0x9, 0x80,
    0x2f, 0x0, 0x0,

    /* U+0024 "$" */
    0x0, 0x1, 0x60, 0x0, 0x0, 0x2, 0xd0, 0x0,
    0x0, 0x6e, 0xfe, 0x40, 0x5, 0xfa, 0xec, 0xf1,
    0xb, 0xc2, 0xd2, 0xf6, 0xc, 0xc2, 0xd0, 0x84,
    0x8, 0xf6, 0xd0, 0x0, 0x1, 0xcf, 0xe1, 0x0,
    0x0, 0x8, 0xfe, 0x30, 0x0, 0x2, 0xee, 0xf2,
    0x3, 0x12, 0xd3, 0xf8, 0xf, 0x82, 0xd0, 0xea,
    0xe, 0xb2, 0xd0, 0xf8, 0x7, 0xfa, 0xeb, 0xf3,
    0x0, 0x8f, 0xfd, 0x40, 0x0, 0x2, 0xd0, 0x0,
    0x0, 0x2, 0xd0, 0x0,

    /* U+0025 "%" */
    0x0, 0x0, 0x0, 0x0, 0x0, 0xbe, 0x40, 0x7,
    0x20, 0x6c, 0x7c, 0x0, 0xa0, 0x8, 0x93, 0xe0,
    0x45, 0x0, 0x88, 0x3e, 0xa, 0x0, 0x7, 0xb5,
    0xc2, 0x80, 0x0, 0x1e, 0xf5, 0x81, 0x0, 0x0,
    0x1, 0x9, 0x5e, 0x80, 0x0, 0x6, 0x4e, 0x5f,
    0x20, 0x0, 0xa1, 0xf0, 0xc5, 0x0, 0x36, 0x2f,
    0xc, 0x50, 0x9, 0x1, 0xf0, 0xc5, 0x1, 0x90,
    0xe, 0x5e, 0x20, 0x62, 0x0, 0x6e, 0x90,

    /* U+0026 "&" */
    0x0, 0x4d, 0xe8, 0x0, 0x0, 0x1f, 0xa8, 0xf3,
    0x0, 0x4, 0xf1, 0xf, 0x50, 0x0, 0x3f, 0x12,
    0xf3, 0x0, 0x0, 0xf6, 0xbc, 0x0, 0x0, 0xb,
    0xfb, 0x0, 0x0, 0x2, 0xef, 0x30, 0x0, 0x1,
    0xe8, 0xcc, 0x5, 0xc0, 0x7f, 0x3, 0xf8, 0x8e,
    0x8, 0xf0, 0x7, 0xfe, 0xa0, 0x7f, 0x20, 0xb,
    0xf8, 0x1, 0xee, 0x77, 0xfe, 0xf6, 0x2, 0xbe,
    0xe8, 0x8, 0x10,

    /* U+0027 "'" */
    0xdb, 0xc9, 0xb7, 0xa5,

    /* U+0028 "(" */
    0x0, 0x0, 0x0, 0x0, 0xc2, 0x0, 0xbb, 0x0,
    0x5d, 0x0, 0xd, 0x50, 0x4, 0xd0, 0x0, 0x98,
    0x0, 0xc, 0x40, 0x0, 0xd3, 0x0, 0xe, 0x20,
    0x0, 0xc4, 0x0, 0xb, 0x60, 0x0, 0x6b, 0x0,
    0x1, 0xf1, 0x0, 0x9, 0xa0, 0x0, 0x1e, 0x60,
    0x0, 0x3f, 0x20, 0x0, 0x20,

    /* U+0029 ")" */
    0x0, 0x0, 0x4, 0xa0, 0x0, 0x1d, 0x70, 0x0,
    0x2f, 0x20, 0x0, 0x8a, 0x0, 0x1, 0xf1, 0x0,
    0xb, 0x60, 0x0, 0x88, 0x0, 0x6, 0xa0, 0x0,
    0x6a, 0x0, 0x7, 0x90, 0x0, 0x97, 0x0, 0xe,
    0x30, 0x4, 0xd0, 0x0, 0xd5, 0x0, 0x9c, 0x0,
    0x5e, 0x10, 0x0, 0x20, 0x0,

    /* U+002A "*" */
    0x0, 0x2, 0xf2, 0x0, 0x0, 0x10, 0x2f, 0x20,
    0x10, 0x6e, 0x51, 0xf1, 0x5e, 0x62, 0xaf, 0xbf,
    0xbf, 0xa2, 0x0, 0x3e, 0xfe, 0x30, 0x0, 0x4d,
    0xff, 0xfd, 0x40, 0x6f, 0xb3, 0xf3, 0xbf, 0x61,
    0x60, 0x2f, 0x20, 0x61, 0x0, 0x2, 0xf2, 0x0,
    0x0, 0x0, 0x19, 0x10, 0x0,

    /* U+002B "+" */
    0x0, 0x1, 0x90, 0x0, 0x0, 0x0, 0x3f, 0x0,
    0x0, 0x0, 0x3, 0xf0, 0x0, 0x0, 0x0, 0x3f,
    0x0, 0x0, 0xaf, 0xff, 0xff, 0xff, 0x71, 0x33,
    0x5f, 0x33, 0x31, 0x0, 0x3, 0xf0, 0x0, 0x0,
    0x0, 0x3f, 0x0, 0x0, 0x0, 0x3, 0xf0, 0x0,
    0x0,

    /* U+002C "," */
    0x5a, 0x18, 0xf1, 0xc, 0x5, 0x60,

    /* U+002D "-" */
    0x0, 0x0, 0x0, 0x0, 0xa, 0xff, 0xff, 0xff,
    0xf6, 0x13, 0x33, 0x33, 0x33, 0x10,

    /* U+002E "." */
    0x6a, 0x9, 0xf0,

    /* U+002F "/" */
    0x0, 0x0, 0x0, 0x0, 0x0, 0x0, 0x0, 0x0,
    0xa3, 0x0, 0x0, 0x0, 0x2c, 0x0, 0x0, 0x0,
    0xa, 0x40, 0x0, 0x0, 0x3, 0xb0, 0x0, 0x0,
    0x0, 0xb3, 0x0, 0x0, 0x0, 0x3b, 0x0, 0x0,
    0x0, 0xc, 0x20, 0x0, 0x0, 0x4, 0xa0, 0x0,
    0x0, 0x0, 0xc2, 0x0, 0x0, 0x0, 0x59, 0x0,
    0x0, 0x0, 0xc, 0x10, 0x0, 0x0, 0x6, 0x90,
    0x0, 0x0, 0x0, 0xd1, 0x0, 0x0, 0x0, 0x68,
    0x0, 0x0, 0x0, 0x3, 0x10, 0x0, 0x0, 0x0,

    /* U+0030 "0" */
    0x0, 0x3c, 0xfc, 0x20, 0x0, 0x3f, 0xd8, 0xdd,
    0x0, 0xb, 0xe1, 0x1, 0xf7, 0x1, 0xf7, 0x0,
    0xa, 0xc0, 0x3f, 0x30, 0x0, 0x7f, 0x5, 0xf1,
    0x0, 0x5, 0xf0, 0x6f, 0x10, 0x0, 0x5f, 0x5,
    0xf1, 0x0, 0x5, 0xf0, 0x4f, 0x20, 0x0, 0x6f,
    0x1, 0xf6, 0x0, 0x9, 0xd0, 0xd, 0xc0, 0x0,
    0xe8, 0x0, 0x5f, 0x93, 0xaf, 0x20, 0x0, 0x7f,
    0xff, 0x50, 0x0, 0x0, 0x14, 0x10, 0x0,

    /* U+0031 "1" */
    0x0, 0xd, 0x50, 0xb, 0xf5, 0xb, 0xef, 0x55,
    0xc2, 0xf5, 0x10, 0x1f, 0x50, 0x1, 0xf5, 0x0,
    0x1f, 0x50, 0x1, 0xf5, 0x0, 0x1f, 0x50, 0x1,
    0xf5, 0x0, 0x1f, 0x50, 0x1, 0xf5, 0x0, 0x1f,
    0x50,

    /* U+0032 "2" */
    0x0, 0x0, 0x0, 0x0, 0x0, 0x8e, 0xfe, 0x60,
    0x8, 0xfa, 0x6b, 0xf4, 0x1f, 0x70, 0x0, 0xea,
    0x27, 0x0, 0x0, 0xbc, 0x0, 0x0, 0x0, 0xe9,
    0x0, 0x0, 0x5, 0xf3, 0x0, 0x0, 0xe, 0xb0,
    0x0, 0x0, 0x9f, 0x10, 0x0, 0x5, 0xf5, 0x0,
    0x0, 0x2f, 0x90, 0x0, 0x1, 0xec, 0x0, 0x0,
    0xc, 0xf7, 0x55, 0x55, 0x1f, 0xff, 0xff, 0xff,

    /* U+0033 "3" */
    0x0, 0x1, 0x31, 0x0, 0x0, 0x8, 0xff, 0xfa,
    0x0, 0x6, 0xf5, 0x17, 0xf7, 0x0, 0xe7, 0x0,
    0xc, 0xb0, 0x3, 0x0, 0x0, 0xbb, 0x0, 0x0,
    0x0, 0x3f, 0x60, 0x0, 0x3, 0xaf, 0x90, 0x0,
    0x0, 0x3b, 0xfb, 0x0, 0x0, 0x0, 0x3, 0xf9,
    0x0, 0x0, 0x0, 0xa, 0xe0, 0x19, 0x10, 0x0,
    0x9e, 0x0, 0xf8, 0x0, 0xe, 0xa0, 0x7, 0xfa,
    0x7c, 0xf3, 0x0, 0x7, 0xdf, 0xb3, 0x0,

    /* U+0034 "4" */
    0x0, 0x0, 0x6, 0xf0, 0x0, 0x0, 0x1, 0xff,
    0x0, 0x0, 0x0, 0xaf, 0xf0, 0x0, 0x0, 0x5f,
    0x9f, 0x0, 0x0, 0xe, 0x96, 0xf0, 0x0, 0x9,
    0xe0, 0x6f, 0x0, 0x3, 0xf4, 0x6, 0xf0, 0x0,
    0xda, 0x0, 0x6f, 0x0, 0x7e, 0x10, 0x6, 0xf0,
    0xc, 0xff, 0xff, 0xff, 0xfa, 0x23, 0x33, 0x38,
    0xf3, 0x20, 0x0, 0x0, 0x6f, 0x0, 0x0, 0x0,
    0x6, 0xf0, 0x0,

    /* U+0035 "5" */
    0x2, 0xff, 0xff, 0xf8, 0x0, 0x5f, 0x55, 0x55,
    0x30, 0x8, 0xc0, 0x0, 0x0, 0x0, 0xb9, 0x0,
    0x0, 0x0, 0xf, 0xce, 0xfc, 0x40, 0x2, 0xfd,
    0x76, 0xdf, 0x30, 0x27, 0x0, 0x1, 0xea, 0x0,
    0x0, 0x0, 0x9, 0xe0, 0x0, 0x0, 0x0, 0x8f,
    0x6, 0x80, 0x0, 0xa, 0xd0, 0x7f, 0x20, 0x3,
    0xf9, 0x1, 0xee, 0x99, 0xfe, 0x10, 0x2, 0xbf,
    0xe9, 0x10, 0x0,

    /* U+0036 "6" */
    0x0, 0x0, 0x6f, 0x30, 0x0, 0x0, 0x1e, 0xa0,
    0x0, 0x0, 0x9, 0xf1, 0x0, 0x0, 0x3, 0xf6,
    0x0, 0x0, 0x0, 0xce, 0x44, 0x0, 0x0, 0x6f,
    0xfe, 0xfe, 0x40, 0xd, 0xe2, 0x1, 0xbf, 0x12,
    0xf6, 0x0, 0x2, 0xf6, 0x4f, 0x30, 0x0, 0xf,
    0x83, 0xf4, 0x0, 0x1, 0xf7, 0xf, 0xa0, 0x0,
    0x7f, 0x30, 0x7f, 0xa6, 0x9f, 0xb0, 0x0, 0x5c,
    0xfe, 0x90, 0x0,

    /* U+0037 "7" */
    0x3f, 0xff, 0xff, 0xff, 0x41, 0x55, 0x55, 0x59,
    0xf2, 0x0, 0x0, 0x0, 0xca, 0x0, 0x0, 0x0,
    0x4f, 0x20, 0x0, 0x0, 0xb, 0xa0, 0x0, 0x0,
    0x2, 0xf3, 0x0, 0x0, 0x0, 0x9d, 0x0, 0x0,
    0x0, 0xf, 0x70, 0x0, 0x0, 0x5, 0xf1, 0x0,
    0x0, 0x0, 0xac, 0x0, 0x0, 0x0, 0xf, 0x80,
    0x0, 0x0, 0x3, 0xf4, 0x0, 0x0, 0x0, 0x7f,
    0x0, 0x0, 0x0,

    /* U+0038 "8" */
    0x0, 0x9e, 0xfc, 0x50, 0x0, 0x9e, 0x76, 0xbf,
    0x40, 0xf, 0x50, 0x0, 0xda, 0x1, 0xf3, 0x0,
    0xc, 0xa0, 0xd, 0xa0, 0x3, 0xf6, 0x0, 0x3e,
    0xed, 0xf9, 0x0, 0x6, 0xfb, 0x9e, 0xb1, 0x2,
    0xf6, 0x0, 0xc, 0xb0, 0x6f, 0x0, 0x0, 0x6f,
    0x7, 0xf0, 0x0, 0x7, 0xf0, 0x5f, 0x50, 0x1,
    0xde, 0x0, 0xef, 0xcb, 0xff, 0x60, 0x2, 0xbe,
    0xfd, 0x70, 0x0,

    /* U+0039 "9" */
    0x0, 0x8e, 0xfc, 0x30, 0xb, 0xfa, 0x9e, 0xf3,
    0x4f, 0x60, 0x1, 0xfb, 0x8f, 0x0, 0x0, 0xbe,
    0x9d, 0x0, 0x0, 0xae, 0x8f, 0x10, 0x0, 0xea,
    0x2f, 0xb1, 0x1a, 0xf4, 0x4, 0xef, 0xff, 0xc0,
    0x0, 0x1, 0x8f, 0x40, 0x0, 0x0, 0xeb, 0x0,
    0x0, 0x6, 0xf3, 0x0, 0x0, 0xe, 0xa0, 0x0,
    0x0, 0x7f, 0x10, 0x0,

    /* U+003A ":" */
    0x7f, 0x25, 0xa1, 0x0, 0x0, 0x0, 0x0, 0x0,
    0x0, 0x0, 0x5, 0xa1, 0x7f, 0x20,

    /* U+003B ";" */
    0x7f, 0x25, 0xa1, 0x0, 0x0, 0x0, 0x0, 0x0,
    0x0, 0x0, 0x5, 0xa1, 0x7f, 0x20, 0xd0, 0x47,
    0x0,

    /* U+003C "<" */
    0x0, 0x0, 0x0, 0x7, 0x0, 0x0, 0x0, 0xa,
    0xb0, 0x0, 0x0, 0xa, 0xb0, 0x0, 0x0, 0xa,
    0xb0, 0x0, 0x0, 0xa, 0xb0, 0x0, 0x0, 0xb,
    0xa0, 0x0, 0x0, 0xb, 0xa0, 0x0, 0x0, 0x2,
    0xe5, 0x0, 0x0, 0x0, 0x2, 0xe5, 0x0, 0x0,
    0x0, 0x2, 0xe6, 0x0, 0x0, 0x0, 0x2, 0xe6,
    0x0, 0x0, 0x0, 0x2, 0xd7, 0x0, 0x0, 0x0,
    0x1, 0xd8, 0x0, 0x0, 0x0, 0x1, 0xc1, 0x0,
    0x0, 0x0, 0x0, 0x0,

    /* U+003D "=" */
    0xaf, 0xff, 0xff, 0xff, 0x61, 0x33, 0x33, 0x33,
    0x31, 0x0, 0x0, 0x0, 0x0, 0x0, 0x0, 0x0,
    0x0, 0x0, 0x0, 0x0, 0x0, 0x0, 0xa, 0xff,
    0xff, 0xff, 0xf6, 0x13, 0x33, 0x33, 0x33, 0x10,

    /* U+003E ">" */
    0x17, 0x0, 0x0, 0x0, 0x1, 0xd8, 0x0, 0x0,
    0x0, 0x1, 0xd8, 0x0, 0x0, 0x0, 0x1, 0xc8,
    0x0, 0x0, 0x0, 0x1, 0xc8, 0x0, 0x0, 0x0,
    0x1, 0xc9, 0x0, 0x0, 0x0, 0x0, 0xc9, 0x0,
    0x0, 0x0, 0x7, 0xd1, 0x0, 0x0, 0x7, 0xd1,
    0x0, 0x0, 0x8, 0xd1, 0x0, 0x0, 0x8, 0xd1,
    0x0, 0x0, 0x9, 0xc1, 0x0, 0x0, 0xa, 0xc0,
    0x0, 0x0, 0x3, 0xb0, 0x0, 0x0, 0x0, 0x0,
    0x0, 0x0, 0x0, 0x0,

    /* U+003F "?" */
    0x0, 0x6d, 0xfc, 0x40, 0x5, 0xfb, 0x7d, 0xf2,
    0xd, 0xd0, 0x2, 0xf8, 0xf, 0x90, 0x1, 0xfa,
    0x2, 0x10, 0x4, 0xf7, 0x0, 0x0, 0x1d, 0xe0,
    0x0, 0x0, 0xce, 0x20, 0x0, 0x4, 0xf4, 0x0,
    0x0, 0x6, 0xe0, 0x0, 0x0, 0x0, 0x0, 0x0,
    0x0, 0x0, 0x0, 0x0, 0x0, 0x7, 0xd0, 0x0,
    0x0, 0x8, 0xf0, 0x0,

    /* U+0040 "@" */
    0x0, 0x2a, 0x9a, 0x70, 0x0, 0x2a, 0x0, 0x6,
    0x60, 0xb, 0x2, 0xca, 0xbb, 0x3, 0x80, 0xd3,
    0x99, 0x73, 0x64, 0x5b, 0x9, 0x65, 0x59, 0x2b,
    0x50, 0xc4, 0x46, 0x91, 0xe2, 0xe, 0x15, 0x69,
    0x1f, 0x11, 0xf0, 0x74, 0x82, 0xe5, 0x6e, 0xc,
    0x5, 0x57, 0xfb, 0xcf, 0x50, 0xa, 0x0, 0x0,
    0x0, 0x0, 0x67, 0x0, 0x7, 0x0, 0x0, 0x5a,
    0x9a, 0x30, 0x0,

    /* U+0041 "A" */
    0x0, 0x6, 0xf4, 0x0, 0x0, 0x0, 0xaf, 0x80,
    0x0, 0x0, 0xe, 0xfd, 0x0, 0x0, 0x3, 0xfa,
    0xf1, 0x0, 0x0, 0x7f, 0x3f, 0x50, 0x0, 0xc,
    0xc0, 0xea, 0x0, 0x0, 0xf8, 0xb, 0xe0, 0x0,
    0x4f, 0x62, 0x8f, 0x20, 0x9, 0xff, 0xff, 0xf7,
    0x0, 0xdd, 0x55, 0x5f, 0xb0, 0x1f, 0x90, 0x0,
    0xbf, 0x6, 0xf4, 0x0, 0x6, 0xf3, 0xaf, 0x0,
    0x0, 0x2f, 0x80,

    /* U+0042 "B" */
    0x3f, 0xff, 0xfd, 0x60, 0x3, 0xfa, 0x77, 0xcf,
    0x50, 0x3f, 0x60, 0x0, 0xec, 0x3, 0xf6, 0x0,
    0xb, 0xe0, 0x3f, 0x60, 0x0, 0xdd, 0x3, 0xf7,
    0x22, 0x8f, 0x60, 0x3f, 0xff, 0xff, 0x90, 0x3,
    0xf9, 0x55, 0x9f, 0x80, 0x3f, 0x60, 0x0, 0x9f,
    0x23, 0xf6, 0x0, 0x7, 0xf4, 0x3f, 0x60, 0x0,
    0xaf, 0x23, 0xfa, 0x77, 0xbf, 0xc0, 0x3f, 0xff,
    0xfd, 0x81, 0x0,

    /* U+0043 "C" */
    0x0, 0x2b, 0xfe, 0x70, 0x0, 0x1e, 0xe7, 0xaf,
    0x80, 0x9, 0xf2, 0x0, 0xaf, 0x0, 0xfa, 0x0,
    0x5, 0xf3, 0x2f, 0x70, 0x0, 0x3b, 0x34, 0xf5,
    0x0, 0x0, 0x0, 0x5f, 0x50, 0x0, 0x0, 0x5,
    0xf5, 0x0, 0x0, 0x31, 0x4f, 0x60, 0x0, 0x4f,
    0x51, 0xf9, 0x0, 0x6, 0xf3, 0xc, 0xe1, 0x0,
    0xbe, 0x0, 0x3f, 0xd7, 0xbf, 0x60, 0x0, 0x3c,
    0xfe, 0x60, 0x0,
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

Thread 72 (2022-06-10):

关于页面管理器 页面状态 （PageState） 切换的问题

zilongmix, 2022-06-10:
## 问题总结
在 `systeminfosView.cpp` 中存在函数 `onFocus` ,用于选项卡的切换。
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

我加入调试信息  `LV_LOG_USER("SYSTEMP-ONFOCUS\r\n");` 发现只有在每次键盘或鼠标输出时，才能进入到该函数中。而 `onFocus` 在如下函数中被调用。
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
查询代码最终在 `void PageManager::StateUpdate(PageBase* base)` 发现了页面状态切换的过程。
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

### 问题1：
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
在 `StateDidAppearExecute` 中返回的 **State** 为 `PAGE_STATE_ACTIVITY` ,按道理来说下次进入 `StateUpdate` 函数时，应该执行 `case PageBase::PAGE_STATE_ACTIVITY:` 分支，但调试发现，执行的一直是 `case PageBase::PAGE_STATE_DID_APPEAR:` 分支。
我想问问在哪里导致了状态的变化?

### 问题2：
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

为什么只有在鼠标键盘输出时，才会进入 `onViewDidAppear();` 函数，并打印我添加的信息。这个页面过程的具体代码在哪里？

FASTSHIFT, 2022-06-10:
`onFocus()`在第一次页面进入显示完成时被`onViewDidAppear()`调用一次，是为了让`group`的第一个`obj`进入`focus`状态。后面的`onFocus()`都是在拨动鼠标滚轮的时候被`group`调用。

zilongmix, 2022-06-10:
> `onFocus()`在第一次页面进入显示完成时被`onViewDidAppear()`调用一次，是为了让`group`的第一个`obj`进入`focus`状态并且移动到对应位置。后面的`onFocus()`都是在拨动鼠标滚轮的时候被`group`调用。
感谢！！

最终找到 `group` 回调函数如下：
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

**页面调度器理解**
`PageManager` 给用户提供的调度接口一共有三个
1. Pop
2. Push
3. BackHome
用户通过手动调用这三个接口，在不同页面之间切换。
页面 `Page` 的状态如下
```c
    /* Page state */
    typedef enum
    {
        PAGE_STATE_IDLE,
        PAGE_STATE_LOAD,
        PAGE_STATE_WILL_APPEAR,
        PAGE_STATE_DID_APPEAR,
        PAGE_STATE_ACTIVITY,
        PAGE_STATE_WILL_DISAPPEAR,
        PAGE_STATE_DID_DISAPPEAR,
        PAGE_STATE_UNLOAD,
        _PAGE_STATE_LAST
    } State_t;
```

不开启页面缓存下的切面调度流程如下图，所有页面都保存在一个 `页面栈` 中，栈顶为当前显示的页面。
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
如果开启页面缓存，主要是少了 `PAGE_STATE_LOAD` 和 `PAGE_STATE_UNLOAD` 的两个状态，不用每次切换页面时，重新构造组件，但也增加了内存开销。
这样理解没错吧！

FASTSHIFT, 2022-06-10:
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

是的，页面缓存的意义是为了保持页面上下文信息，切回的时候可以保持原样而不是被重置。

Closed 2022-06-10.

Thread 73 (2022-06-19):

About GPS Accuracy on Live MAP

AhmadPanogari, 2022-06-19:
I've successfully run this program with ESP32 and Ili9341 3.2 TFT LCD with Ublox-M8N GPS module.

However I have a problem with the result showing in Live Map (ARROW point), it doesn't look like what I see with the web based map even though it's the same longitude and latitude.

when viewed in Live View from Tile X and Y it does give the correct image but gives the wrong ARROW point.

is there any configuration to be able to adjust it?

may provide an offset configuration or other to match the actual situation.

Thanks very much.

FASTSHIFT, 2022-06-19:
@AhmadPanogari
The program uses the [GCJ-02](https://en.wikipedia.org/wiki/Restrictions_on_geographic_data_in_China#GCJ-02) coordinate system by default, and you need to switch to the [WGS-84](https://en.wikipedia.org/wiki/World_Geodetic_System#WGS84)  coordinate system in your country.
Modification method:
Modify the `X-Track/USER/App/Config/Config.h` file in
`#define CONFIG_MAP_USE_WGS84_DEFAULT true`
or
Modify the `SystemSave.json` file in the SD card
`"sysConfig.mapWGS84": 1`

AhmadPanogari, 2022-07-02:
I've changed those settings and now it's accurate.

Thank you, sorry for the late response

Closed 2022-07-02.

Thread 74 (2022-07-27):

编译linux源码生成xtrack后运行提示[DC][Error] Account[CENTER] was not found

xxzling, 2022-07-27:
希望大佬解答，谢谢。

FASTSHIFT, 2022-07-27:
程序提示了`input event device path`，需要加event设备的路径参数，例如`sudo ./xtrack /dev/input/event0`.

xxzling, 2022-07-27:
感谢大佬回复，程序已经可以运行了，但显示似乎异常是和颜色深度有关吗，另外显示了以下日志
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

FASTSHIFT, 2022-07-27:
修改`lv_conf.h`
```c
#define LV_COLOR_DEPTH 32
#define LV_COLOR_16_SWAP 0
```

FASTSHIFT, 2022-07-27:
文件系统适配不是太完美，可能得摸索一下。

xxzling, 2022-07-27:
感谢，已经成功在fb0设备上输出了
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

Closed 2022-10-05.

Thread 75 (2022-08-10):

希望可以加入车头朝上功能

Aleer-Keer, 2022-08-10:
自己不会写代码，希望可以加入车头朝上功能

FASTSHIFT, 2022-08-10:
下一代加

json9666, 2022-10-12:
@FASTSHIFT  话说 磁仪计和陀螺仪 好像在箭头 转向的地方没有用到嘛？ 只有gps数据么？

json9666, 2022-10-13:
@FASTSHIFT  大佬，这个理论上是可以结合磁计和陀螺仪 实现 实时摆动设备 引导 箭头变化么？

FASTSHIFT, 2022-10-13:
> @FASTSHIFT 大佬，这个理论上是可以结合磁计和陀螺仪 实现 实时摆动设备 引导 箭头变化么？

能做，新版本会加这个功能。

json9666, 2022-10-13:
@FASTSHIFT  大佬新版本大概多久出哈？ 嘿嘿，好期待

json9666, 2022-10-13:
@FASTSHIFT  我试了下把 陀螺仪打开后， imu数据就乱了，或者根本不动了。。能力有限，期待大佬

Closed 2025-09-01.

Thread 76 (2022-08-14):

地图无法显示

dyufeimen, 2022-08-14:
按照教程的方法，模拟器里地图页面无法显示。请问是什么问题呢？
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

FASTSHIFT, 2022-08-14:
https://github.com/FASTSHIFT/X-TRACK/tree/main/Software#vs%E6%A8%A1%E6%8B%9F%E5%99%A8%E9%85%8D%E7%BD%AE

> PC模拟器上无法显示地图/显示颜色异常
* MAP地图文件夹放在X-TRACK工程的根目录`~/X-TRACK/MAP/`
* 修改**SystemSave.json**里的经纬度配置到希望显示地图的地方
* 确认生成的地图文件命名格式为`/z/x/y.png`
* 修改**SystemSave.json**的`"sysConfig.mapExtName"`项目，将`"bin"`改为`"png"`

dyufeimen, 2022-08-14:
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

按照这几点修改了也不行，而且我通过调试发现在LiveMap.cpp中的MapTileContReload方法里给View.SetMapTileSrc(i, path);传入的path路径也是正确的，但是就是无法显示。
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

dyufeimen, 2022-08-14:
>

我好像看了看path：/ovMAP/16/51705/x693w.png，但是我打开的路径是ovMAP/16/51705/26932/tile.png。难道是我转行地图图片的时候略过了那一步？

FASTSHIFT, 2022-08-14:
> >
>
> 我好像看了看path：/ovMAP/16/51705/x693w.png，但是我打开的路径是ovMAP/16/51705/26932/tile.png。难道是我转换地图图片的时候略过了那一步？

命名风格配错了，参考：
https://github.com/FASTSHIFT/X-TRACK/blob/main/Images/%E5%9C%B0%E5%9B%BE%E4%B8%8B%E8%BD%BD%E6%95%99%E7%A8%8B/4-%E5%9C%B0%E5%9B%BE%E4%B8%8B%E8%BD%BD%E9%85%8D%E7%BD%AE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

dyufeimen, 2022-08-14:
果然是这个原因，感谢作者

Closed 2022-10-05.

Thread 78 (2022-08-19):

行者新出了个码表辰，我拆开看了一下它用的芯片，希望能给2代芯片选型一些参考

liyang5945, 2022-08-19:
600mAh电池号称能续航30h，应该是在不开启蓝牙和背光的情况下，即使这样它的工作电流也只有20mA左右，GPS+CPU+屏幕做到这个功耗，可以说是非常惊人了。我最近在尝试使用esp32-s3移植本项目，跑了下官方的蓝牙demo，工作电流都有100mA左右，然后买了个ATGM336H模块，发现它的工作电流也得50mA，再加上屏幕的话工作电流至少也要200mA了。辰刚发布我就参加了盲订活动，最近刚到货就把它拆开了，看看它用的是什么芯片

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

通过芯片上的编码查询之后，GPS芯片用的是这个: https://www.u-blox.com/en/product/ubx-m10050-chip
CPU则是这个NRF52840: https://www.nordicsemi.com/products/nrf52840 Cortex™-M4 CPU 64MHz RAM只有256KB ，虽然性能有点低，但是只用它做个蓝牙芯片也是不错的。芯片价格我在淘宝也查了下，GPS那个只要二十多块，52840只要十几块钱，希望能给2代芯片选型一些参考。

greatws88, 2023-04-18:
esp32要用NIMBLE，传统蓝牙功耗太大了

FASTSHIFT, 2024-07-24:
二代码表使用 AT32F437 + NRF52832 方案。

Closed 2024-07-24.

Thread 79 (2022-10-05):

码表底部的2个孔,如何与码表支架进行组合

yukiloh, 2022-10-05:
看到作者的码表使用的是洛克兄弟的支架
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
请问连接支架与码表的部分是什么样子的,或者告知其商品名称

另,测量下来2个孔洞的参数如下,如果有误请指正
六角形内切圆半径: 2.7(毫米)
孔距: 21.128
小孔圆半径: 3
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

FASTSHIFT, 2022-10-05:
参考[特殊器件购买链接](https://github.com/FASTSHIFT/X-TRACK/tree/main/Hardware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)中的**码表底座**。

Closed 2022-10-05.

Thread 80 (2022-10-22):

Add external folder to visual studio

obitvn, 2022-10-22:
Sorry if this is not very relevant, but how can you add an external folder to visual studio, specifically here App and HAL folders.

obitvn, 2022-10-22:
i tried to edit the config file of vs, but it can only add files that don't create folder like you and i can't build
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
My folder looks like this
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
It doesn't show up like your folder, I tried searching for solution many times on google but to no avail
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

FASTSHIFT, 2022-10-22:
Use the filter view instead of the folder view.

obitvn, 2022-10-22:
thank you for the response, but it's not a view issue
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
i'm curious how did you add the external folder to the project? Add files one by one by dragging and dropping?

obitvn, 2022-10-22:
after adding the files, it seems that visual studio can't find the .h files due to the path structure
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
i guess this is because visual studio can't find this path in its root, i added it but vs still can't recognize it, how did you make visual studio work?
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

obitvn, 2022-10-24:
After failed experiment with x-track i decided to create a new VS project myself and add the files i needed to it, it worked, simply copy folder, ctrl+v into VS, then exclude Unnecessary files, add the path to that folder at Property>C/C++>Additional Include Directory
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

Closed 2022-10-24.

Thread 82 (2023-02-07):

小bug，中断中提早拉高sc脚导致丢失数据

diqiu114, 2023-02-07:
# 源码中的写法为
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
# 实测时序为，其中sc过早拉高
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
# 查手册指示，需要等待 BSY = 0;
![Uploading image.png…]()
# 修改后写法
        else
        {
            while(SPI_I2S_GetFlagStatus(SPI1, SPI_I2S_FLAG_BUSY)==SET); // 等待spi传输完成
            digitalWrite_HIGH(CONFIG_SCREEN_CS_PIN);
            if(Disp_Callback)
            {
                Disp_Callback();
            }
# 修改后实测时序：
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

AlexZhang087, 2024-02-25:
显示SPI_I2S_GetFlagStatus未定义

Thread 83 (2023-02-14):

关于添加新控件的问题

LNqueen, 2023-02-14:
我想在这页面管理框架的基础上再新增一个页面，这个页面中有一些其他的控件，比如btn和switch控件，但是实际显示出来时发现这些控件的位置上是空白的，请问这个是什么原因呢？

FASTSHIFT, 2023-02-14:
为了节省FLASH和RAM空间，所以关闭了`LV_USE_THEME_DEFAULT`，所有组件的样式都要手动设置。

LNqueen, 2023-02-15:
懂了，感谢你的回复

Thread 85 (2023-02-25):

对于mvp模式的一个小问题

LNqueen, 2023-02-25:
我移植这个框架有一个小问题，我理解的这个框架大概的流程就是数据和显示是分开的，当新数据到达时并不会直接交给界面去显示，而是将数据集中存放在一起（center），当view到达定时器设置的时间后开始更新界面的数据的信息，那如果我想使用一个弹窗来实时显示新到的数据，应该怎么做呢？如果按照mvp的思路走是不是只能等定时器计数完显示最新的数据呢？

FASTSHIFT, 2023-02-25:
可以在Model层做一个回调到Presenter层，当收到数据更新事件时Persenter触发View更新

LNqueen, 2023-02-25:
大概懂了，我等下试一下，感谢大佬😄

Closed 2023-10-24.

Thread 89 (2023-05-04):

请问作者如何实现测量剩余电量

yukiloh, 2023-05-04:
看到状态管脚STAT直接接入MCU的31引脚,应该是为了显示充电动画
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

而BAT_IN→VBAT直接接入MCU的供电引脚,也没有发现连接其他管脚进行电压测量
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

查阅代码看到有使用Hysteresis + MedianQueue,具体代码不太看得清,是通过软件算法实现电量计算的吗?

FASTSHIFT, 2023-05-04:
PA1是接电量检测引脚，电量测量是直接通过电压换算的，然后过了一个滞回滤波和中值滤波。

yukiloh, 2023-05-04:
> PA1是接电量检测引脚，电量测量是直接通过电压换算的，然后过了一个滞回滤波和中值滤波。

有用,不好意思看漏了分压电路...

Closed 2023-05-04.

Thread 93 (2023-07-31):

编译的时候出现14个error

abcdeaaa123, 2023-07-31:
新手，用的5.38版本的keil，具体截图如下
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

代码完全没有修改，也没有动过配置文件，编译的时候报错大多数在sd卡附近，所有编译报错如下：

Build started: Project: proj
*** Using Compiler 'V5.05 update 1 (build 106)', folder: 'D:\Keil_v5\ARM\ARMCC\Bin'
Build target 'X-Track'
compiling DP_IMU.cpp...
..\USER\App\Common\DataProc\DP_IMU.cpp(6): error:  #2958: the body of a value-returning lambda with no explicit return type must be a single return statement
      HAL::IMU_SetCommitCallback([](void* info, void* userData){
..\USER\App\Common\DataProc\DP_IMU.cpp: 0 warnings, 1 error
compiling DP_MAG.cpp...
..\USER\App\Common\DataProc\DP_MAG.cpp(6): error:  #2958: the body of a value-returning lambda with no explicit return type must be a single return statement
      HAL::MAG_SetCommitCallback([](void* info, void* userData){
..\USER\App\Common\DataProc\DP_MAG.cpp: 0 warnings, 1 error
compiling LIS3MDL.cpp...
..\Libraries\LIS3MDL\LIS3MDL.cpp(55): error:  #19: extra text after expected end of number
              if (sa1 != sa1_low && testReg(LIS3MDL_SA1_HIGH_ADDRESS, WHO_AM_I) == LIS3MDL_WHO_ID)
..\Libraries\LIS3MDL\LIS3MDL.cpp(64): error:  #19: extra text after expected end of number
              else if (sa1 != sa1_high && testReg(LIS3MDL_SA1_LOW_ADDRESS, WHO_AM_I) == LIS3MDL_WHO_ID)
..\Libraries\LIS3MDL\LIS3MDL.cpp(86): error:  #19: extra text after expected end of number
          address = (sa1 == sa1_high) ? LIS3MDL_SA1_HIGH_ADDRESS : LIS3MDL_SA1_LOW_ADDRESS;
..\Libraries\LIS3MDL\LIS3MDL.cpp(86): error:  #19: extra text after expected end of number
          address = (sa1 == sa1_high) ? LIS3MDL_SA1_HIGH_ADDRESS : LIS3MDL_SA1_LOW_ADDRESS;
..\Libraries\LIS3MDL\LIS3MDL.cpp: 0 warnings, 4 errors
compiling rt_sys.cpp...
..\Libraries\SdFat\src\SdFat.h(333): error:  #441: argument list for class template "SdFileSystem" is missing
             SdFileSystem::begin();
..\USER\HAL\rt_sys.cpp: 0 warnings, 1 error
compiling HAL_SD_CARD.cpp...
..\Libraries\SdFat\src\SdFat.h(333): error:  #441: argument list for class template "SdFileSystem" is missing
             SdFileSystem::begin();
..\USER\HAL\HAL_SD_CARD.cpp: 0 warnings, 1 error
compiling HAL.cpp...
..\Libraries\SdFat\src\SdFat.h(333): error:  #441: argument list for class template "SdFileSystem" is missing
             SdFileSystem::begin();
..\USER\HAL\HAL.cpp: 0 warnings, 1 error
compiling lv_port_fs_sdfat.cpp...
..\Libraries\SdFat\src\SdFat.h(333): error:  #441: argument list for class template "SdFileSystem" is missing
             SdFileSystem::begin();
..\USER\lv_port\lv_port_fs_sdfat.cpp: 0 warnings, 1 error
compiling HAL_FaultHandle.cpp...
..\Libraries\SdFat\src\SdFat.h(333): error:  #441: argument list for class template "SdFileSystem" is missing
             SdFileSystem::begin();
..\USER\HAL\HAL_FaultHandle.cpp: 0 warnings, 1 error
compiling DP_Recorder.cpp...
..\Libraries\SdFat\src\SdFat.h(333): error:  #441: argument list for class template "SdFileSystem" is missing
             SdFileSystem::begin();
..\USER\App\Common\DataProc\DP_Recorder.cpp: 0 warnings, 1 error
compiling SystemInfos.cpp...
..\Libraries\SdFat\src\SdFat.h(333): error:  #441: argument list for class template "SdFileSystem" is missing
             SdFileSystem::begin();
..\USER\App\Pages\SystemInfos\SystemInfos.cpp: 0 warnings, 1 error
compiling StartupView.cpp...
..\Libraries\SdFat\src\SdFat.h(333): error:  #441: argument list for class template "SdFileSystem" is missing
             SdFileSystem::begin();
..\USER\App\Pages\Startup\StartupView.cpp: 0 warnings, 1 error
".\Objects\X-Track.axf" - 14 Error(s), 0 Warning(s).
Target not created.
Build Time Elapsed:  00:00:06

求大佬们能给一点指导，谢谢了！

abcdeaaa123, 2023-07-31:
补充一下尝试过的措施。。查了一下有说在配置里加上--cpp11参数的，加完变成700多error了。。。

FASTSHIFT, 2023-07-31:
编译环境问题，尝试用Keil v5.36试试。

w6c6x6, 2024-10-22:
我换了5.36的版本还是报错除了换版本还做了什么操作吗

Closed 2023-07-31.

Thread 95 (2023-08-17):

可以正常开机和充电，但是按钮一松手就断电

abcdeaaa123, 2023-08-17:
RT，充电似乎没有问题，但是无法保持开机电源，开机后侧边按钮只要一松就会断电，大佬有什么排查的方向吗，新手检查了一圈没有找到原因。。

abcdeaaa123, 2023-08-17:
有点怀疑是不是AO3400和AON3400的问题，大佬的链接中AON3400的链接写的是AO3400，所以BOM的两种3400我用了同一种，都是链接里的那款，这两款到底是否是同一款呢，上一个issue里我没有看明白您说的意思
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

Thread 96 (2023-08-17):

无法定位程序输入点'PssCaptureSnapshot' 于动态链接库KERNEL32.dll

tianheyun, 2023-08-17:
win7系统debug调试模式报错（release模式正常）:无法定位程序输入点'PssCaptureSnapshot' 于动态链接库KERNEL32.dll。搜了下'PssCaptureSnapshot函数至少是win8以上的系统才支持.   请问X-TRACE有调用这个函数吗？win7系统怎么解决？谢谢

FASTSHIFT, 2025-09-01:
没有调用，属于环境问题，可以尝试咨询deepwik：https://deepwiki.com/FASTSHIFT/X-TRACK

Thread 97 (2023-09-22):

支持嵌入式linux平台么

justdomyself, 2023-09-22:
如题

FASTSHIFT, 2023-09-22:
支持的，见目录：https://github.com/FASTSHIFT/X-TRACK/tree/main/Software/X-Track/Linux，稍微改改makefile就可以用。

justdomyself, 2023-09-22:
> 支持的，见目录：[Software/X-Track/Linux](https://github.com/FASTSHIFT/X-TRACK/tree/main/Software/X-Track/Linux)，稍微改改makefile就可以用。

编译报错：
ome/alientek/Desktop/cmake/X-TRACK/Software/X-Track/Linux/../Simulator/LVGL.Simulator/lv_drivers/sdl/sdl_common.c:5:
/home/alientek/Desktop/cmake/X-TRACK/Software/X-Track/Linux/../Simulator/LVGL.Simulator/lv_drivers/sdl/sdl_common.h:33:10: error: #include expects "FILENAME" or <FILENAME>
   33 | #include SDL_INCLUDE_PATH
      |          ^~~~~~~~~~~~~~~~
/home/alientek/Desktop/cmake/X-TRACK/Software/X-Track/Linux/../Simulator/LVGL.Simulator/lv_drivers/sdl/sdl_common.h:86:34: error: unknown type name ‘SDL_Event’
   86 | int quit_filter(void * userdata, SDL_Event * event);
      |                                  ^~~~~~~~~
/home/alientek/Desktop/cmake/X-TRACK/Software/X-Track/Linux/../Simulator/LVGL.Simulator/lv_drivers/sdl/sdl_common.h:88:20: error: unknown type name ‘SDL_Event’
   88 | void mouse_handler(SDL_Event * event);
      |                    ^~~~~~~~~
/home/alientek/Desktop/cmake/X-TRACK/Software/X-Track/Linux/../Simulator/LVGL.Simulator/lv_drivers/sdl/sdl_common.h:89:25: error: unknown type name ‘SDL_Event’
   89 | void mousewheel_handler(SDL_Event * event);
      |                         ^~~~~~~~~

FASTSHIFT, 2023-09-22:
已更新，可以拉最新代码试试。

justdomyself, 2023-09-22:
> 已更新，可以拉最新代码试试。
gcc编译没有问题，交叉编译提示nullptr错误：
In file included from /home/alientek/Desktop/cmake/X-TRACK/Software/X-Track/Linux/../USER/App/Pages/AppFactory.h:23:0,
                 from /home/alientek/Desktop/cmake/X-TRACK/Software/X-Track/Linux/../USER/App/App.cpp:26:
/home/alientek/Desktop/cmake/X-TRACK/Software/X-Track/Linux/../USER/App/Utils/PageManager/PageManager.h: At global scope:
/home/alientek/Desktop/cmake/X-TRACK/Software/X-Track/Linux/../USER/App/Utils/PageManager/PageManager.h:105:40: error: 'nullptr' was not declared in this scope
     PageManager(PageFactory* factory = nullptr);
                                        ^
/home/alientek/Desktop/cmake/X-TRACK/Software/X-Track/Linux/../USER/App/Utils/PageManager/PageManager.h:115:69: error: 'nullptr' was not declared in this scope
     bool Replace(const char* name, const PageBase::Stash_t* stash = nullptr);
                                                                     ^
/home/alientek/Desktop/cmake/X-TRACK/Software/X-Track/Linux/../USER/App/Utils/PageManager/PageManager.h:116:66: error: 'nullptr' was not declared in this scope
     bool Push(const char* name, const PageBase::Stash_t* stash = nullptr);
                                                                  ^
/home/alientek/Desktop/cmake/X-TRACK/Software/X-Track/Linux/../USER/App/Utils/PageManager/PageManager.h:172:85: error: 'nullptr' was not declared in this scope
     bool SwitchTo(PageBase* base, bool isEnterAct, const PageBase::Stash_t* stash = nullptr);

FASTSHIFT, 2023-09-22:
make的时候指定一下编译器：
```sh
make CC=<C编译器名字> CXX=<C++编译器名字>
```

justdomyself, 2023-09-25:
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

开了的，现在报这个错：

CC /home/alientek/Desktop/cmake/X-TRACK/Software/X-Track/Linux/../USER/App/Utils/lv_ext/lv_anim_timeline_wrapper.c
In file included from /home/alientek/Desktop/cmake/X-TRACK/Software/X-Track/Linux/../Simulator/LVGL.Simulator/HAL/HAL_Power.cpp:1:
/home/alientek/Desktop/cmake/X-TRACK/Software/X-Track/Linux/../Simulator/LVGL.Simulator/HAL/HAL.h:26:10: fatal error: Common/HAL/HAL.h: No such file or directory
   26 | #include "Common/HAL/HAL.h"
      |          ^~~~~~~~~~~~~~~~~~
In file included from /home/alientek/Desktop/cmake/X-TRACK/Software/X-Track/Linux/../Simulator/LVGL.Simulator/HAL/HAL_Audio.cpp:1:
/home/alientek/Desktop/cmake/X-TRACK/Software/X-Track/Linux/../Simulator/LVGL.Simulator/HAL/HAL.h:26:10: fatal error: Common/HAL/HAL.h: No such file or directory
   26 | #include "Common/HAL/HAL.h"
      |          ^~~~~~~~~~~~~~~~~~
compilation terminated.

FASTSHIFT, 2023-09-25:
试了一下树莓派的工具链编译没有问题，你的编译命令是什么？
```sh
make CC=/opt/cross-pi-gcc/bin/arm-linux-gnueabihf-gcc CXX=/opt/cross-pi-gcc/bin/arm-linux-gnueabihf-g++ -j12
```
这个报错就是头文件引用路径找不到，可以自己先排查一下。

justdomyself, 2023-09-25:
> ```shell
> a
> ```

1、刷新环境变量
 source /opt/fsl-imx-xwayland/5.4-zeus/environment-setup-aarch64-poky-linux

2、查看环境变量
**env | grep CC**

QT_ACCESSIBILITY=1
OE_QMAKE_RCC=/opt/fsl-imx-xwayland/5.4-zeus/sysroots/x86_64-pokysdk-linux/usr/bin/rcc
CLANGCC=aarch64-poky-linux-clang  -mcpu=cortex-a53+crc+crypto -fstack-protector-strong  -D_FORTIFY_SOURCE=2 -Wformat -Wformat-security -Werror=format-security -mlittle-endian --sysroot=/opt/fsl-imx-xwayland/5.4-zeus/sysroots/aarch64-poky-linux
OE_QMAKE_CC=aarch64-poky-linux-gcc  -mcpu=cortex-a53+crc+crypto -fstack-protector-strong  -D_FORTIFY_SOURCE=2 -Wformat -Wformat-security -Werror=format-security --sysroot=/opt/fsl-imx-xwayland/5.4-zeus/sysroots/aarch64-poky-linux
CC=aarch64-poky-linux-gcc  -mcpu=cortex-a53+crc+crypto -fstack-protector-strong  -D_FORTIFY_SOURCE=2 -Wformat -Wformat-security -Werror=format-security --sysroot=/opt/fsl-imx-xwayland/5.4-zeus/sysroots/aarch64-poky-linux

**env | grep CXX**
OE_QMAKE_CXX=aarch64-poky-linux-g++  -mcpu=cortex-a53+crc+crypto -fstack-protector-strong  -D_FORTIFY_SOURCE=2 -Wformat -Wformat-security -Werror=format-security --sysroot=/opt/fsl-imx-xwayland/5.4-zeus/sysroots/aarch64-poky-linux
CXX=aarch64-poky-linux-g++  -mcpu=cortex-a53+crc+crypto -fstack-protector-strong  -D_FORTIFY_SOURCE=2 -Wformat -Wformat-security -Werror=format-security --sysroot=/opt/fsl-imx-xwayland/5.4-zeus/sysroots/aarch64-poky-linux
CXXFLAGS= -O2 -pipe -g -feliminate-unused-debug-types
OE_QMAKE_CXXFLAGS= -O2 -pipe -g -feliminate-unused-debug-types
CLANGCXX=aarch64-poky-linux-clang++  -mcpu=cortex-a53+crc+crypto -fstack-protector-strong  -D_FORTIFY_SOURCE=2 -Wformat -Wformat-security -Werror=format-security -mlittle-endian --sysroot=/opt/fsl-imx-xwayland/5.4-zeus/sysroots/aarch64-poky-linux

3、直接编译，输入make -j4

FASTSHIFT, 2023-09-25:
在makefile加点log看一下`INCLUDE_CFG`变量头文件引用路径有没有问题。

justdomyself, 2023-09-25:
> 在makefile加点log看一下`INCLUDE_CFG`变量头文件引用路径有没有问题。

这是打印的INCLUDE_CFG的值：
-I/home/alientek/Desktop/cmake/X-TRACK/Software/X-Track/Linux/../Simulator/LVGL.Simulator/ -I/home/alientek/Desktop/cmake/X-TRACK/Software/X-Track/Linux/../USER/App -I/home/alientek/Desktop/cmake/X-TRACK/Software/X-Track/Linux/../USER/App/Utils/ArduinoJson/src

FASTSHIFT, 2023-09-25:
引用路径没问题，那应该就是编译环境问题了，自己查一下吧。

justdomyself, 2023-09-26:
> 引用路径没问题，那应该就是编译环境问题了，自己查一下吧。

编译环境都是原厂提供的，编译其他的源码没出现过这种问题呢

Closed 2024-07-24.

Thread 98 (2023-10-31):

页面的自定义出场动画不起作用

LNqueen, 2023-10-31:
我在使用页面管理框架的时候出现了这样的问题，我按照示例代码中的DialplateView文件中的动画时间线的方式创建了动画，大概是这样的
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
但是在设备上却好像没有效果，找了很久但是都没有找到原因，请问下这个大概可能是什么原因呢？
补充：
1.在开机动画之后我使用replace函数跳转到menu页面（我自己创建的页面），
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
在vs模拟器中显示这个出场动画是起作用的，但是在实际的设备中这个动画是不起作用的；
2.在onCustomAttrConfig()，函数中我只写了则一行代码：SetCustomLoadAnimType(PageManager::LOAD_ANIM_NONE);
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
3.我直接使用按钮来触发出场动画好像也不成功；
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
4.lvgl的版本是8.3.9（一开始是8.1.0，后来为了解决这个问题升级到了8.3.9）
5.使用SetCustomLoadAnimType(PageManager::LOAD_ANIM_OVER_TOP)可以看到预设的页面出场动画；

额外：
我还出现了另外一个问题，那就是我是用push函数大概建立了一个三级的菜单页面（即从menu页面使用push函数跳转了两个页面），但是从第三个页面pop到第二个页面的时候画面就卡住了，但是程序是在运行的，不知道发生了什么~

我的问题可能有点多，如果大佬有空的话就抽空解答一下，非常感谢！！

FASTSHIFT, 2023-11-02:
确认下模拟器的lv_conf.h和设备上的是不是一致的。

Closed 2024-05-14.

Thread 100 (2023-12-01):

新版本页面管理器在页面退出动画不连续

zhbi98, 2023-12-01:
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

FASTSHIFT, 2023-12-05:
`onViewDidDisappear`表示页面已经消失了，直接隐藏有什么问题呢，是因为动画最后一帧没有刷到屏幕上吗？可以给出对比视频。

zhbi98, 2023-12-06:
以下是我的测试，测试设备并不是 X-TRACK，而是移植了 X-TRACK 页面管理器的设备，第1张onViewDidDisappear是没有执行隐藏的，第2张是在onViewDidDisappear 执行隐藏的效果
https://github.com/FASTSHIFT/X-TRACK/assets/49710448/cd52de1f-e5ca-4a8c-8574-72da983a92df
https://github.com/FASTSHIFT/X-TRACK/assets/49710448/c647ec26-60b6-421e-9f19-cfe9c246e905

FASTSHIFT, 2023-12-06:
@zhbi98
用的动画类型是`LOAD_ANIM_MOVE_BOTTOM`吗，我本地测了一下是正常的：

zhbi98, 2023-12-06:
我用的动画是 LOAD_ANIM_MOVE_TOP

FASTSHIFT, 2023-12-06:
`onViewDidDisappear`是在此页面动画结束后调用的，不会在`onViewWillDisappear`立即调用。

zhbi98, 2023-12-06:
看到你的视频没有问题我感到好奇，所以想问一个我的疑问，为什么在上一个页面对象的 onViewWillDisappear 创建动画后，立即执行到上一个页面对象的 onViewDidDisappear 去隐藏上一个页面，在你这边不会导致上一个页面立即隐藏。因为动画需要一定时间，但是在递归的作用下 onViewWillDisappear ->onViewDidDisappear 是瞬间时间的事情。

zhbi98, 2023-12-06:
> `onViewDidDisappear`是在此页面动画结束后调用的，不会在`onViewWillDisappear`执行后立即调用。

但是我似乎没有在动画结束函数看到调用 onViewDidDisappear 函数

zhbi98, 2023-12-06:
看到了，看到了
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

FASTSHIFT, 2023-12-06:
LVGL版本是多少？有修改过页面切换动画相关参数吗？可以在模拟器上复现吗？

zhbi98, 2023-12-06:
看见了，是我的改造出现问题了
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

zhbi98, 2023-12-06:
不错，是我对代码稍作了一些修改，在状态机中多加了 StateUpdate 函数递归

FASTSHIFT, 2023-12-06:
> 不错，是我对代码稍作了一些修改，在状态机中多加了 StateUpdate 函数递归

OK，还有做哪些修改吗？

zhbi98, 2023-12-06:
其他没有，由于看到状态机的返回值为 下一个状态，所以顺手加了一个

zhbi98, 2023-12-06:
不好意思是我疏忽了，为此我还给你 pull request 了一个修改，现在我去关闭它

FASTSHIFT, 2023-12-06:
> 不好意思是我疏忽了，为此我还给你 pull request 了一个修改，现在我去关闭它

没关系，发现问题欢迎讨论~

zhbi98, 2023-12-06:
你的页面生命周期管理模块，和消息订阅框架太好用了，很感谢你的分享

Closed 2023-12-06.

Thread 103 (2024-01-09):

无法获取手势动作

Ccuso4, 2024-01-09:
大佬打扰了，我是在PC上运行稍微修改了下代码想适配触摸屏的手势动作，但是每次都只返回`LV_EVENT_PRESSED`，以下是修改的code。
```
void Dialplate::onViewLoad()
{
    Model.Init();
    View.Create(_root);
    AttachEvent(_root);
    AttachEvent(View.ui.topInfo.cont);
    //AttachEvent(View.ui.btnCont.btnRec);
    //AttachEvent(View.ui.btnCont.btnMenu);
}
......
......
void Dialplate::onEvent(lv_event_t* event)
{
    if (code == LV_EVENT_GESTURE)
    {
        printf("GESTURE %d", code);

        if (lv_indev_get_gesture_dir(lv_indev_get_act()) == LV_DIR_LEFT) {
            instance->_Manager->Push("Pages/SystemInfos");
        }
    }
    if (code == LV_EVENT_PRESSED)
    {
        printf("LV_EVENT_PRESSED %d \n", code);
    }
}
```
打印值：
```
[PM][Warn] Page PagePrev(Pages/Startup) is busy
LV_EVENT_PRESSED 1
LV_EVENT_PRESSED 1
LV_EVENT_PRESSED 1
LV_EVENT_PRESSED 1
LV_EVENT_PRESSED 1
LV_EVENT_PRESSED 1
```
感谢

FASTSHIFT, 2024-01-09:
@Ccuso4
可以看一下lvgl的手势识别的代码实现，见`lvgl\src\core\lv_indev.c`中的`indev_gesture`函数，里面计算的得出的`gesture_obj`为什么不是想要的那个。

Ccuso4, 2024-01-10:
> @Ccuso4 可以看一下lvgl的手势识别的代码实现，见`lvgl\src\core\lv_indev.c`中的`indev_gesture`函数，里面计算的得出的`gesture_obj`为什么不是想要的那个。

感谢你的回复，我在`lvgl\src\core\lv_indev.c`里加了一些log，发现手势识别是没有问题的，只是传过去的对象不一致，不太明白为啥。以下是修改代码和log
```
void indev_gesture(_lv_indev_proc_t * proc)
{

    if(proc->types.pointer.scroll_obj) return;
    if(proc->types.pointer.gesture_sent) return;

    lv_obj_t * gesture_obj = proc->types.pointer.act_obj;

    /*If gesture parent is active check recursively the gesture attribute*/
    while(gesture_obj && lv_obj_has_flag(gesture_obj, LV_OBJ_FLAG_GESTURE_BUBBLE)) {
        gesture_obj = lv_obj_get_parent(gesture_obj);
    }
    if(gesture_obj == NULL) return;
    if((LV_ABS(proc->types.pointer.vect.x) < indev_act->driver->gesture_min_velocity) &&
       (LV_ABS(proc->types.pointer.vect.y) < indev_act->driver->gesture_min_velocity)) {
        proc->types.pointer.gesture_sum.x = 0;
        proc->types.pointer.gesture_sum.y = 0;
    }

    /*Count the movement by gesture*/
    proc->types.pointer.gesture_sum.x += proc->types.pointer.vect.x;
    proc->types.pointer.gesture_sum.y += proc->types.pointer.vect.y;

    if((LV_ABS(proc->types.pointer.gesture_sum.x) > indev_act->driver->gesture_limit) ||
       (LV_ABS(proc->types.pointer.gesture_sum.y) > indev_act->driver->gesture_limit)) {

        proc->types.pointer.gesture_sent = 1;

        if(LV_ABS(proc->types.pointer.gesture_sum.x) > LV_ABS(proc->types.pointer.gesture_sum.y)) {
            if (proc->types.pointer.gesture_sum.x > 0)
            {
                proc->types.pointer.gesture_dir = LV_DIR_RIGHT;
                LV_LOG_USER("LV_DIR_RIGHT !!!!!!");
            }
            else
            {
                proc->types.pointer.gesture_dir = LV_DIR_LEFT;
                LV_LOG_USER("LV_DIR_LEFT !!!!!!");
            }
        }
        else {
            if(proc->types.pointer.gesture_sum.y > 0)
            {
                proc->types.pointer.gesture_dir = LV_DIR_BOTTOM;
                LV_LOG_USER("LV_DIR_BOTTOM !!!!!!");
            }
            else
            {
                proc->types.pointer.gesture_dir = LV_DIR_TOP;
                LV_LOG_USER("LV_DIR_TOP !!!!!!");
            }
        }

        lv_event_send(gesture_obj, LV_EVENT_GESTURE, indev_act);
        LV_LOG_USER("gesture_obj:%d,  LV_EVENT_GESTURE:%d", gesture_obj, LV_EVENT_GESTURE);
        if(indev_reset_check(proc)) return;
    }
```
log
```
[User]  (1275390.365, +7538)     onEvent: obj:-1322611424 LV_EVENT_PRESSED:1   (in Dialplate.cpp line #249)
[User]  (1275390.458, +93)       indev_gesture: LV_DIR_LEFT !!!!!!      (in lv_indev.c line #1149)
[User]  (1275390.459, +1)        indev_gesture: gesture_obj:-1322644160,  LV_EVENT_GESTURE:12   (in lv_indev.c line #1166)
```
感谢

Ccuso4, 2024-01-10:
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

我发现将手势对象传递给父对象的flag禁掉后就可以了`lv_obj_clear_flag(cont, LV_OBJ_FLAG_GESTURE_BUBBLE);`

FASTSHIFT, 2024-01-10:
Good!

Closed 2024-01-10.

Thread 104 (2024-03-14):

需要提前将GPX文件准备好吗？那么如果第一次去某个地方，没有GPX文件，如何处理？

Doing-code, 2024-03-14:
代码路径：`X-Track\Simulator\LVGL.Simulator\HAL\HAL_GPS.cpp`

```c++
static bool Parser_Init(GPX_Parser* parser, FileInfo_t* info) {
...
    lv_fs_res_t res = lv_fs_open(&info->file, CONFIG_TRACK_VIRTUAL_GPX_FILE_PATH, LV_FS_MODE_RD);
...
}
```
如果是第一次骑行，如何准备GPX文件？如果去GPX没有覆盖的地方，程序还会正常记录速度、耗时等数据信息吗？

如果第一次没有GPX文件，运动记录操作跑不起来，这种情况如何解决？？一定要实现准备GPX吗？

Doing-code, 2024-03-14:
```txt
onRecord: GPS has not ready, can't start record
```
如果没有GPX文件，会出现如上错误，一定要事先准备.GPX，才能启动开始按钮吗 ？

FASTSHIFT, 2024-03-14:
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

这个是PC模拟器的逻辑。因为PC上没有真实的GPS设备来产生坐标数据，所以通过回放GPX文件的方式来模拟GPS数据。
在真实设备上，GPS数据取自GPS模块，见代码文件[HAL_GPS.cpp](https://github.com/FASTSHIFT/X-TRACK/blob/main/Software/X-Track/USER/HAL/HAL_GPS.cpp)，不需要准备GPX文件。

FASTSHIFT, 2024-03-14:
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

这个报错的含义是，要求GPS要先定位上（有坐标数据产生），才能开始进行轨迹记录，轨迹记录器不关心实际的GPS数据源。PC模拟器需要导入GPX文件才能产生GPS数据，在真实设备上是GPS连接成功就能产生GPS数据。

Closed 2024-05-14.

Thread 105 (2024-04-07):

这个页面管理框架会有内存泄漏的现象吗?

AresXiaoHui, 2024-04-07:
我移植了这个框架,当我切换界面再返回时,内存消耗会增加大约不到100B,每一次切换再返回都是如此,请问有人遇到过吗?

FASTSHIFT, 2024-04-07:
可以尝试用VS的VLD工具或者GCC的LeakSanitizer进行定位，看一下是框架泄露还是用户程序泄露。码表上还未发现泄露现象。

AresXiaoHui, 2024-04-07:
> 可以尝试用VS的VLD工具或者GCC的LeakSanitizer进行定位，看一下是框架泄露还是用户程序泄露。码表上还未发现泄露现象。

谢谢指点!看来大概率是我自己的问题!

Closed 2024-05-14.

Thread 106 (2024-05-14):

gpxsee查看历史轨迹的时候使用高德瓦片地图显示位置偏移

magic-zjk, 2024-05-14:
下载的高德瓦片地图在码表中显示正常。

导出历史轨迹通过gpxsee查看时，选择了自定义的瓦片服务器（使用该高德瓦片地图）显示位置发生偏移。但是使用gpxsee自带的Open Topo Map地图能正常显示。

不知道作者有没有遇到过这种情况？

FASTSHIFT, 2024-05-14:
地图偏移是因为gpxsee只支持标准的WGS84坐标系统，而国内的地图使用的是GCJ02坐标系统，是坐标系统不一致导致发生了偏移。
gpxsee的自带地图显示正常是因为使用了国外的地图源，国外的地图源都是WGS84坐标系统。
码表显示正确是因为做了坐标转换。

magic-zjk, 2024-05-17:
> 地图偏移是因为gpxsee只支持标准的WGS84坐标系统，而国内的地图使用的是GCJ02坐标系统，是坐标系统不一致导致发生了偏移。 gpxsee的自带地图显示正常是因为使用了国外的地图源，国外的地图源都是WGS84坐标系统。 码表显示正确是因为做了坐标转换。

@FASTSHIFT
在没有梯子的情况下Open Topo Map地图勉强能显示。请教一下有没有其他办法使用自定义的瓦片服务器也能正常显示呢？

FASTSHIFT, 2024-05-17:
> > 地图偏移是因为gpxsee只支持标准的WGS84坐标系统，而国内的地图使用的是GCJ02坐标系统，是坐标系统不一致导致发生了偏移。 gpxsee的自带地图显示正常是因为使用了国外的地图源，国外的地图源都是WGS84坐标系统。 码表显示正确是因为做了坐标转换。
>
> @FASTSHIFT 在没有梯子的情况下Open Topo Map地图勉强能显示。请教一下有没有其他办法使用自定义的瓦片服务器也能正常显示呢？

没了解过，可以在gpxsee上发个issue问问。

Reskip, 2024-08-19:
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

导入前可以先进行一次坐标转换，开源的函数很多
网页端工具也有，可以参考 https://mp.weixin.qq.com/s/4jLedSmkjJNsDhx-zDxwWg

Closed 2024-07-24.

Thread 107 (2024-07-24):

关于复刻问题

monkeywq, 2024-07-24:
你好，首先非常感谢开源这么棒的项目，我近期复刻过程中遇到几个问题，万望解答：
1.手工焊接的磁场传感器LIS3MDL焊坏了，没有这个芯片可以测速吗？
2.主菜单选择开始，提示失败音，是因为没有插内存卡吗？

FASTSHIFT, 2024-07-24:
> 1.手工焊接的磁场传感器LIS3MDL焊坏了，没有这个芯片可以测速吗？

速度信息来自GPS模块，所以不影响测速。

> 2.主菜单选择开始，提示失败音，是因为没有插内存卡吗？

因为没定位成功，无法开始轨迹记录。

monkeywq, 2024-07-24:
ok,刚刚焊接了GPS模块，使用的是ATGM336H，从菜单看读取的数据全是0，要对GPS模块做一些设置吗

FASTSHIFT, 2024-07-24:
见常见故障排查： https://github.com/FASTSHIFT/X-TRACK/tree/main/Hardware

monkeywq, 2024-07-25:
感谢解答，关于GPS又查看了板子上的串口接收口Rx,发现此IO持续3.3V,如果不是软件配置上拉输入，是不是可以说明焊接问题？
另外请问 磁场传感器和加速度计作用是什么？

Closed 2024-07-26.

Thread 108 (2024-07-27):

有机会更新sdfat支持exfat嘛？

magpte, 2024-07-27:
菜鸟，stlink还没到，看到sdfat v2支持exfat了，有机会可以更新的嘛？
https://github.com/greiman/SdFat

FASTSHIFT, 2024-07-27:
你可以试试，如果可以的话发一个PR~

magpte, 2024-07-27:
等小弟估计很久了，真的就是业余中的业余，平时生活很忙

FASTSHIFT, 2024-07-27:
没事，等有空了再搞也行

magpte, 2024-07-29:
哈哈哈哈，gg，发现自己不是这块料，连最简单的tinygps的更新到1.1.1beta都不会，关了关了关了

Closed 2024-07-29.

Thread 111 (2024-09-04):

程序烧进去了但是蓝屏

lucksonzhen, 2024-09-04:
使用原工程代码编译出来的785K的hex可以正常运行。我自己增加了一个含有动图和其他图片的页面，出来的hex有1294K，能烧写进去，但是开机就蓝屏，和作者给出来的蓝屏页面是一样的。请问是哪里出了问题呢，是我的hex太大了？还能救一下吗，做出来想送人的，跪求帮助！

FASTSHIFT, 2024-09-27:
@lucksonzhen 模拟器能复现吗？在模拟器上单步调试一下。
另外蓝屏的时候串口会打印backtrace（函数调用栈信息），看一下是哪个函数挂掉的，具体方法见：https://github.com/armink/CmBacktrace/blob/master/README_ZH.md

Closed 2025-04-16.

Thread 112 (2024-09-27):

bool PageBase::StashPop(void* ptr, uint32_t size)返回值错误

smalixing, 2024-09-27:
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

FASTSHIFT, 2024-09-27:
感谢指出，已修复：https://github.com/FASTSHIFT/X-TRACK/commit/e394e50a9cc82307e17dac798bd8f6ec335d124f

Closed 2024-09-27.

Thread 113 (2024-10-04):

内存泄漏问题

0422-fwj, 2024-10-04:
void StartupView::Delete() 里没有显式释放ui.cont,，不会导致内存泄漏吗

FASTSHIFT, 2024-10-04:
> void StartupView::Delete() 里没有显式释放ui.cont,，不会导致内存泄漏吗

`ui.cont`是挂在`root`节点上的，lvgl会在删除`root`节点的时候会自动销毁所有子对象（包括`ui.cont`）。
root删除处理代码位于：https://github.com/FASTSHIFT/X-TRACK/blob/main/Software/X-Track/USER/App/Utils/PageManager/PM_State.cpp#L228 在页面退出后会执行`StateUnloadExecute`

Closed 2024-10-04.

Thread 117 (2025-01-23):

疑问： 请问这个项目 可以更换更高频率的GPS模块如25HZ的吗  想制作用于赛道计时器

Power-Gloves, 2025-01-23:
这个项目 可以更换更高频率的GPS模块如25HZ的吗  想制作用于赛道计时器，通常市面上的计时器都很贵 200刀左右，看到这个项目 感觉原理类似。。。也不是很懂 所以询问一下~~

FASTSHIFT, 2025-01-23:
可以试试，可调整`CONFIG_GPS_REFR_PERIOD`配置项来提升GPS读取频率。

nasaboy, 2025-04-15:
> 可以试试，可调整`CONFIG_GPS_REFR_PERIOD`配置项来提升GPS读取频率。

GPS模块那边需要调吗？

FASTSHIFT, 2025-04-16:
> > 可以试试，可调整`CONFIG_GPS_REFR_PERIOD`配置项来提升GPS读取频率。
>
> GPS模块那边需要调吗？

参考GPS手册，手动调节GPS更新频率。

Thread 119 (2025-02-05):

地图瓦片下载器的百度网盘地址失效无法下载，能否再分享一下，谢谢。

justdomyself, 2025-02-05:
https://github.com/FASTSHIFT/X-TRACK/tree/main/Tools

这个地址给的百度网盘无效。

Rnfrraacth, 2025-03-10:
新的可以在gitee上的原项目找到。搜Crimson即可，去找“Crimson/地图下载器”这个项目

justdomyself, 2025-03-11:
谢谢！

---原始邮件---
发件人: ***@***.***&gt;
发送时间: 2025年3月10日(周一) 下午5:34
收件人: ***@***.***&gt;;
抄送: ***@***.******@***.***&gt;;
主题: Re: [FASTSHIFT/X-TRACK] 地图瓦片下载器的百度网盘地址失效无法下载，能否再分享一下，谢谢。 (Issue #119)

新的可以在gitee上的原项目找到。搜Crimson即可，去找“Crimson/地图下载器”这个项目

—
Reply to this email directly, view it on GitHub, or unsubscribe.
You are receiving this because you authored the thread.Message ID: ***@***.***&gt;
  Rnfrraacth left a comment (FASTSHIFT/X-TRACK#119)

新的可以在gitee上的原项目找到。搜Crimson即可，去找“Crimson/地图下载器”这个项目

—
Reply to this email directly, view it on GitHub, or unsubscribe.
You are receiving this because you authored the thread.Message ID: ***@***.***&gt;

Closed 2025-04-16.

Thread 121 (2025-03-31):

我的屏幕是320*240的，怎样适配下载的256*256的瓦片地图？

justdomyself, 2025-03-31:
如果需要全屏显示地图，是不是要修改瓦片下载工具，让下载的地图也是320*240的  ？

谢谢！

FASTSHIFT, 2025-03-31:
@justdomyself
不需要，[TileConv](https://github.com/FASTSHIFT/X-TRACK/tree/main/Software/X-Track/USER/App/Utils/TileConv)会自动适应屏幕分辨率加载屏幕范围内可以显示的地图瓦片，完成任意尺寸的地图显示。

Closed 2025-04-16.

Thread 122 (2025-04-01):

求助：关不了机是什么情况

yikuihan, 2025-04-01:

FASTSHIFT, 2025-04-02:
见文档: [常见故障排查](https://github.com/FASTSHIFT/X-TRACK/tree/main/Hardware#%E5%B8%B8%E8%A7%81%E6%95%85%E9%9A%9C%E6%8E%92%E6%9F%A5)

yikuihan, 2025-04-02:
请问长摁编码器嘟嘟两声应该是哪个地方有问题？

FASTSHIFT, 2025-04-15:
> 请问长摁编码器嘟嘟两声应该是哪个地方有问题？

已更新在文档中。

Closed 2025-04-16.

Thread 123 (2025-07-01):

旋转编码器消抖策略的优化思路

Reskip, 2025-07-01:
背景：
- version 1: 未做代码修改，直接复刻本项目。发现在使用编码器时，时常会出现滚动方向判断错误的情况。
- version 2: 尝试基于 esp32 自制了一版码表，使用相同旋转编码器，也会出现类似的输入错判问题。

排查：
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
- 编码器输入波形正常，偶有毛刺，但不是方向误判的主要原因。

解决思路：
- https://www.faulhaber.com/fileadmin/Import/Media/AN147_EN.pdf 文档中介绍，可以使用四步法解析正交编码器的输出，该方法能有效避免毛刺和采样错误导致的误判。
- 尝试在我的 ESP32 项目中实现该方法，测试证明修改后几乎不再出现误码情况
https://github.com/Reskip/ESP32TrackRecorder/blob/main/main/status/encoder_state.cpp#L52

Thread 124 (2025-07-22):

长时间记录后（超过3小时）会自动崩溃关机，大佬有兴趣修复下嘛？

magpte, 2025-07-22:
根据使用，觉得比较可能原因是记录轨迹因为没有写入TF卡，导致崩溃，自己是小白，问了Deepseek，想看看大佬会考虑修复这个问题嘛？

https://metaso.cn/s/HnQ4azu

万分感谢。

magpte, 2025-07-23:
哈哈哈，买的成本机器，只有+3.3，GND，CLK和DIO。不知道这种怎么调试，有什么教程的嘛？

magpte, 2025-09-06:
https://deepwiki.com/search/_3f39c694-4203-4cc5-b7f3-aac54872c3d4

搞了个定时保存到TF，不过我repo了大佬的下来，自己做了个人定制，每30个点写入一次存储卡

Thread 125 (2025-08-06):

Unable to see map in ubuntu environment

Prajyot01, 2025-08-06:
Hello ,
I have run the X-Track linuxSDL2 but i am not able to see map. i have created Map folder in root directory and put there png files . Also the Systemsave.json and other files are not generated automatically. kindly help us to resolve this issue.

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

FASTSHIFT, 2025-08-12:
You can try modifying the default longitude and latitude in [Config.h](https://github.com/FASTSHIFT/X-TRACK/blob/main/Software/X-Track/USER/App/Config/Config.h#L44) and set them to the location where you want to display the map.

Prajyot01, 2025-08-12:
the Systemsave.json and other files are not generated

Closed 2025-09-01.

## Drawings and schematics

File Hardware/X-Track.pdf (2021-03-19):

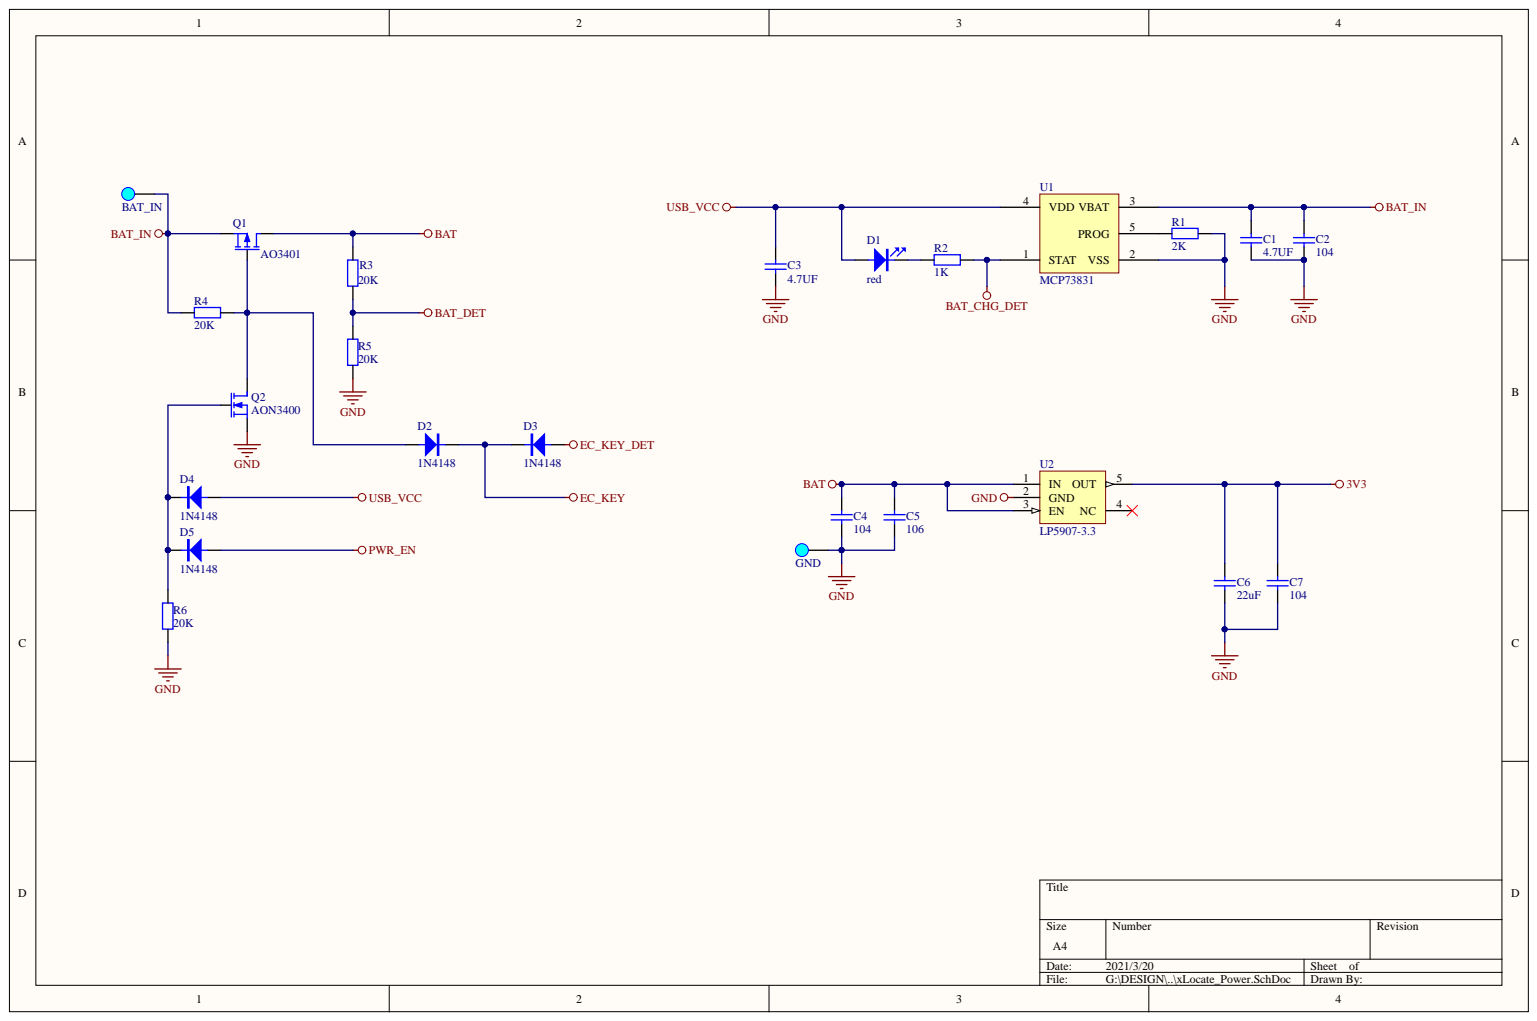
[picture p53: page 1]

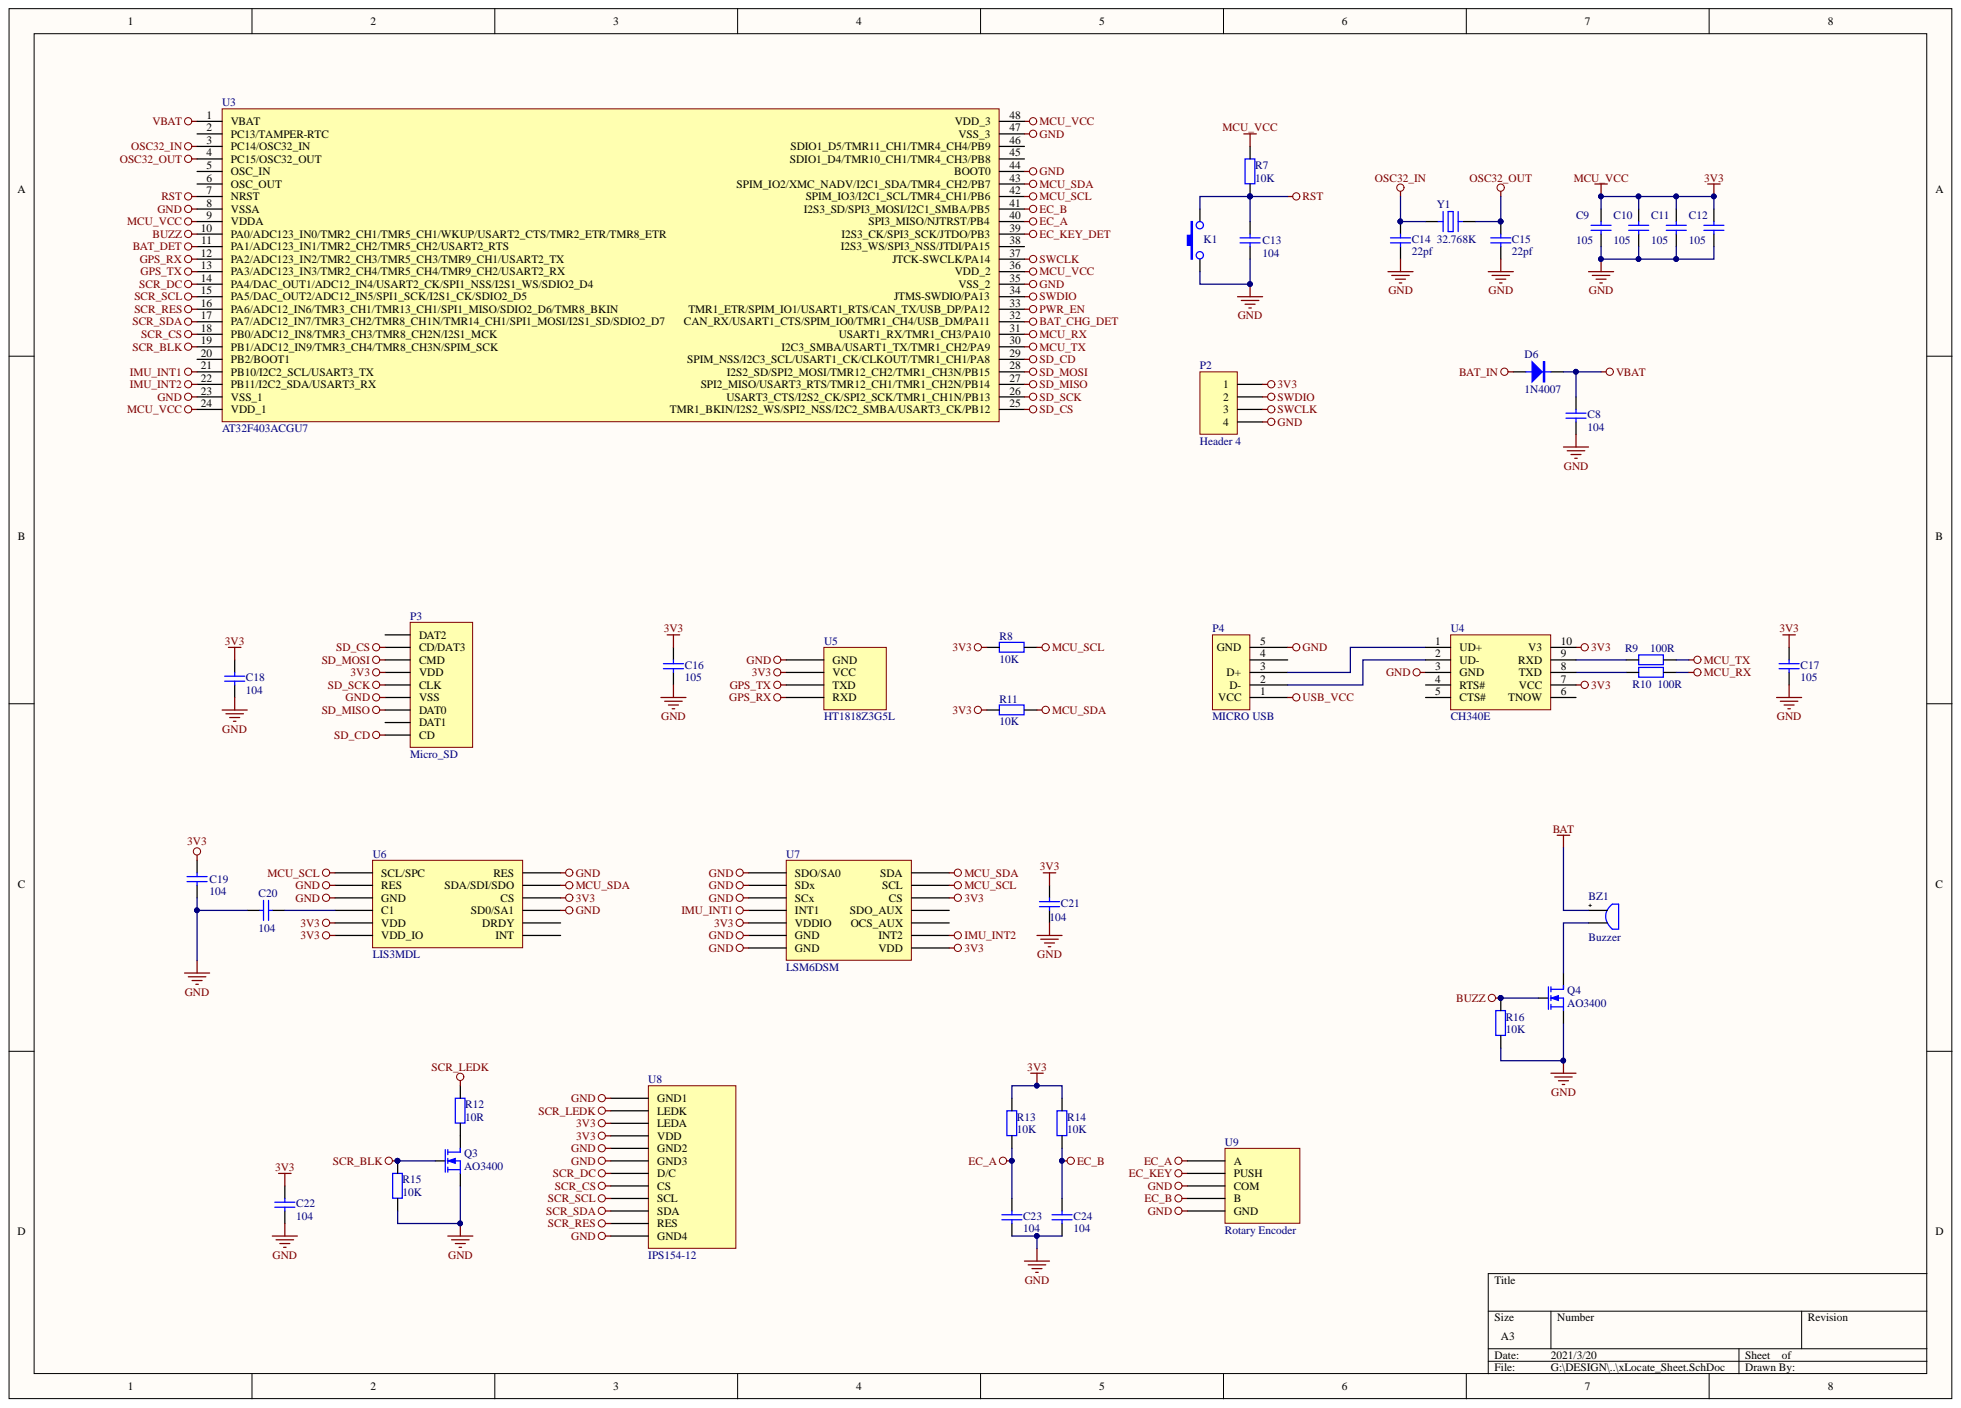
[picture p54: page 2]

Bill of Materials | <Parameter Title not found>
Source Data From: | xLocate.PrjPcb
Project: | | xLocate.PrjPcb
Variant: | | None
Creation Date: 2021/3/20 | 1:02:46
Print Date: | 20-Mar-21 | 1:03:00 AM
Footprint | Comment | LibRef | Designator | Description | Quantity
Pad_B | BAT_IN | Pad | BAT+ | | 1
Pad_B | GND | Pad | BAT- | | 1
蜂鸣器 _SMD5020 | Buzzer | BZ | BZ1 | | 1
电容_C0805 | 4.7UF | cap | C1, C3 | | 2
电容_C0603 | 104 | cap | C2, C4, C7, C8, C13, C18, C19, C20,
| | | C21, C22, C23, C24 | | 12
电容_C0603 | 106 | cap | C5 | | 1
电容_C1206 | 22uF | cap | C6 | | 1
电容_C0603 | 105 | cap | C9, C10, C11, C12, C16, C17 | | 6
电容_C0603 | 22pf | cap | C14, C15 | | 2
LED_0603 | red | LED | D1 | | 1

### 二极管_SOD-

323 | 1N4148 | Diode | D2, D3, D4, D5 | | 4

### 二极管_SOD-

323 | 1N4007 | Diode | D6 | | 1
开关按键 _SKRP | SKRP | SW-PB | K1 | | 1
HDR1X4H | Header 4 | Header 4 | P2 | Header, 4-Pin | 1
接插件 _Micro_SD | Micro_SD | Micro_SD | P3 | | 1
接插件 _MICRO 牛角 插座 USB 直 边 | MICRO USB | MICRO USB
| | 5PIN | P4 | | 1
MOS_SOT-23 | AO3401 | MOSFET-P | Q1 | | 1
MOS_SOT-23 | AON3400 | MOSFET-N | Q2 | | 1
MOS_SOT-23 | AO3400 | MOSFET-N | Q3, Q4 | | 2
电阻_R0603 | 2K | Res | R1 | | 1
电阻_R0603 | 1K | Res | R2 | | 1
电阻_R0603 | 20K | Res | R3, R4, R5, R6 | | 4
电阻_R0603 | 10K | Res | R7, R8, R11, R13, R14, R15, R16 | | 7
电阻_R0603 | 100R | Res | R9, R10 | | 2
电阻_R0603 | 10R | Res | R12 | | 1
SOT23-5 | MCP73831 | MCP73831 | U1 | 线性充电管理控制器 | 1
SOT23-5 | LP5907-3.3 | LP5907 | U2 | LDO | 1
AT主控 _QFN48(6X6) | AT32F403ACGU
| 7 | AT32F403CGU6 | U3 | | 1
串口 _MSOP10 | CH340E | CH340E | U4 | | 1
GPS-HTZN | HT1818Z3G5L | HT1818Z3G5L | U5 | | 1
LGA- 12_L2.0- W2.0-P0.50- BL | LIS3MDL | LIS3DMDL | U6 | | 1

### LGA-

14_L3.0-
W2.5-P0.50-
BL
LSM6DSM | LSM6DSM | U7 | 1

### ZJY154T-PG04 FPC

0.7mm

IPS154-12 | IPS154-12 | U8 | 1
SIQ-02FVS3 | Rotary Encoder | Rotary Encoder | U9 | 1
晶振_3215 | 32.768K | XTAL_A | Y1 | 1
| | | | 67
Approved | | Notes

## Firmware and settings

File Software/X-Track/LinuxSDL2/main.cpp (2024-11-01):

#define _DEFAULT_SOURCE /* needed for usleep() */
#include <stdlib.h>
#include <unistd.h>
#define SDL_MAIN_HANDLED /*To fix SDL's "undefined reference to WinMain" issue*/
#include <SDL2/SDL.h>
#include "lvgl/lvgl.h"
#include <pthread.h>
#include <time.h>
#include <sys/time.h>
#include <stdlib.h>
#include <stdio.h>
#include "lv_drivers/sdl/sdl.h"

#include "App.h"
#include "Common/HAL/HAL.h"
#include "lv_fs_if/lv_fs_if.h"

extern "C" {
    LV_IMG_DECLARE(mouse_cursor_icon); /*Declare the image file.*/
}

static void hal_init(const char* evdev_path)
{
    /* Use the 'monitor' driver which creates window on PC's monitor to simulate a display*/
    sdl_init();

    /*Create a display buffer*/
    const uint32_t disp_buf_size = LV_HOR_RES * LV_VER_RES;
    lv_color_t* buf = (lv_color_t*)malloc(disp_buf_size * sizeof(lv_color_t));

    /*Initialize a descriptor for the buffer*/
    static lv_disp_draw_buf_t disp_buf;
    lv_disp_draw_buf_init(&disp_buf, buf, NULL, disp_buf_size);

    /*Initialize and register a display driver*/
    static lv_disp_drv_t disp_drv;
    lv_disp_drv_init(&disp_drv);
    disp_drv.draw_buf   = &disp_buf;
    disp_drv.flush_cb   = sdl_display_flush;
    disp_drv.hor_res    = LV_HOR_RES;
    disp_drv.ver_res    = LV_VER_RES;
    lv_disp_drv_register(&disp_drv);

    lv_group_t * g = lv_group_create();
    lv_group_set_default(g);

    /* Add the mouse as input device
    * Use the 'mouse' driver which reads the PC's mouse*/
   static lv_indev_drv_t indev_drv_1;
   lv_indev_drv_init(&indev_drv_1); /*Basic initialization*/
   indev_drv_1.type = LV_INDEV_TYPE_POINTER;

   /*This function will be called periodically (by the library) to get the mouse position and state*/
   indev_drv_1.read_cb = sdl_mouse_read;
   lv_indev_t *mouse_indev = lv_indev_drv_register(&indev_drv_1);

   static lv_indev_drv_t indev_drv_2;
   lv_indev_drv_init(&indev_drv_2); /*Basic initialization*/
   indev_drv_2.type = LV_INDEV_TYPE_KEYPAD;
   indev_drv_2.read_cb = sdl_keyboard_read;
   lv_indev_t *kb_indev = lv_indev_drv_register(&indev_drv_2);
   lv_indev_set_group(kb_indev, g);

   static lv_indev_drv_t indev_drv_3;
   lv_indev_drv_init(&indev_drv_3); /*Basic initialization*/
   indev_drv_3.type = LV_INDEV_TYPE_ENCODER;
   indev_drv_3.read_cb = sdl_mousewheel_read;
   lv_indev_t * enc_indev = lv_indev_drv_register(&indev_drv_3);
   lv_indev_set_group(enc_indev, g);

   /*Set a cursor for the mouse*/
   LV_IMG_DECLARE(mouse_cursor_icon); /*Declare the image file.*/
   lv_obj_t * cursor_obj = lv_img_create(lv_scr_act()); /*Create an image object for the cursor */
   lv_img_set_src(cursor_obj, &mouse_cursor_icon);           /*Set the image source*/
   lv_indev_set_cursor(mouse_indev, cursor_obj);             /*Connect the image  object to the driver*/         /*Connect the image  object to the driver*/
}

int main(int argc, const char* argv[])
{
    /*LittlevGL init*/
    lv_init();

    lv_fs_if_init();

    hal_init(argv[1]);

    HAL::HAL_Init();

    App_Init();

    /*Handle LitlevGL tasks (tickless mode)*/
    while(1) {
        lv_task_handler();
        HAL::HAL_Update();
        usleep(1000);
    }

    App_Uninit();

    return 0;
}

/*Set in lv_conf.h as `LV_TICK_CUSTOM_SYS_TIME_EXPR`*/
extern "C" uint32_t custom_tick_get(void)
{
    static uint64_t start_ms = 0;
    if(start_ms == 0) {
        struct timeval tv_start;
        gettimeofday(&tv_start, NULL);
        start_ms = (tv_start.tv_sec * 1000000 + tv_start.tv_usec) / 1000;
    }

    struct timeval tv_now;
    gettimeofday(&tv_now, NULL);
    uint64_t now_ms;
    now_ms = (tv_now.tv_sec * 1000000 + tv_now.tv_usec) / 1000;

    uint32_t time_ms = now_ms - start_ms;
    return time_ms;
}

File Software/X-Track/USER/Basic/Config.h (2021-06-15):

/*
 * MIT License
 * Copyright (c) 2021 _VIFEXTech
 *
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
 * THE SOFTWARE IS PROVIDED "AS IS", WITHOUT WARRANTY OF ANY KIND, EXPRESS OR
 * IMPLIED, INCLUDING BUT NOT LIMITED TO THE WARRANTIES OF MERCHANTABILITY,
 * FITNESS FOR A PARTICULAR PURPOSE AND NONINFRINGEMENT. IN NO EVENT SHALL THE
 * AUTHORS OR COPYRIGHT HOLDERS BE LIABLE FOR ANY CLAIM, DAMAGES OR OTHER
 * LIABILITY, WHETHER IN AN ACTION OF CONTRACT, TORT OR OTHERWISE, ARISING FROM,
 * OUT OF OR IN CONNECTION WITH THE SOFTWARE OR THE USE OR OTHER DEALINGS IN THE
 * SOFTWARE.
 */
#ifndef __CONFIG_H
#define __CONFIG_H

#define NULL_PIN                PD0

/* Screen */
#define CONFIG_SCREEN_CS_PIN    PB0
#define CONFIG_SCREEN_DC_PIN    PA4
#define CONFIG_SCREEN_RST_PIN   PA6
#define CONFIG_SCREEN_SCK_PIN   PA5
#define CONFIG_SCREEN_MOSI_PIN  PA7
#define CONFIG_SCREEN_BLK_PIN   PB1  // TIM3

/* Battery */
#define CONFIG_BAT_DET_PIN      PA1
#define CONFIG_BAT_CHG_DET_PIN  PA11

/* Buzzer */
#define CONFIG_BUZZ_PIN         PA0  // TIM2

/* GPS */
#define CONFIG_GPS_TX_PIN       PA3
#define CONFIG_GPS_RX_PIN       PA2

/* IMU */
#define CONFIG_IMU_INT1_PIN     PB10
#define CONFIG_IMU_INT2_PIN     PB11

/* I2C */
#define CONFIG_MCU_SDA_PIN      PB7
#define CONFIG_MCU_SDL_PIN      PB6

/* Encoder */
#define CONFIG_ENCODER_B_PIN    PB5
#define CONFIG_ENCODER_A_PIN    PB4
#define CONFIG_ENCODER_PUSH_PIN PB3

/* Power */
#define CONFIG_POWER_EN_PIN     PA12

/* USART */
#define CONFIG_MCU_RX_PIN       PA10
#define CONFIG_MCU_TX_PIN       PA9

/* SD CARD */
#define CONFIG_SD_CD_PIN        PA8
#define CONFIG_SD_MOSI_PIN      PB15
#define CONFIG_SD_MISO_PIN      PB14
#define CONFIG_SD_SCK_PIN       PB13
#define CONFIG_SD_CS_PIN        PB12

#define CONFIG_HAL_UPDATE_TIM   TIM4

#endif

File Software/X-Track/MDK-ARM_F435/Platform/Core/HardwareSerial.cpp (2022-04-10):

/*
 * MIT License
 * Copyright (c) 2017 - 2022 _VIFEXTech
 *
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
 * THE SOFTWARE IS PROVIDED "AS IS", WITHOUT WARRANTY OF ANY KIND, EXPRESS OR
 * IMPLIED, INCLUDING BUT NOT LIMITED TO THE WARRANTIES OF MERCHANTABILITY,
 * FITNESS FOR A PARTICULAR PURPOSE AND NONINFRINGEMENT. IN NO EVENT SHALL THE
 * AUTHORS OR COPYRIGHT HOLDERS BE LIABLE FOR ANY CLAIM, DAMAGES OR OTHER
 * LIABILITY, WHETHER IN AN ACTION OF CONTRACT, TORT OR OTHERWISE, ARISING FROM,
 * OUT OF OR IN CONNECTION WITH THE SOFTWARE OR THE USE OR OTHER DEALINGS IN THE
 * SOFTWARE.
 */
#include "HardwareSerial.h"

typedef struct
{
    usart_data_bit_num_type data_bit;
    usart_parity_selection_type parity_selection;
    usart_stop_bit_num_type stop_bit;
} SERIAL_ConfigGrp_t;

static const SERIAL_ConfigGrp_t SERIAL_ConfigGrp[] =
{
    {USART_DATA_7BITS, USART_PARITY_NONE, USART_STOP_1_BIT},   // SERIAL_7N1
    {USART_DATA_7BITS, USART_PARITY_NONE, USART_STOP_2_BIT},   // SERIAL_7N2
    {USART_DATA_7BITS, USART_PARITY_EVEN, USART_STOP_1_BIT},   // SERIAL_7E1
    {USART_DATA_7BITS, USART_PARITY_EVEN, USART_STOP_2_BIT},   // SERIAL_7E2
    {USART_DATA_7BITS, USART_PARITY_ODD,  USART_STOP_1_BIT},   // SERIAL_7O1
    {USART_DATA_7BITS, USART_PARITY_ODD,  USART_STOP_2_BIT},   // SERIAL_7O2
    {USART_DATA_7BITS, USART_PARITY_NONE, USART_STOP_0_5_BIT}, // SERIAL_7N0_5
    {USART_DATA_7BITS, USART_PARITY_NONE, USART_STOP_1_5_BIT}, // SERIAL_7N1_5
    {USART_DATA_7BITS, USART_PARITY_EVEN, USART_STOP_0_5_BIT}, // SERIAL_7E0_5
    {USART_DATA_7BITS, USART_PARITY_EVEN, USART_STOP_1_5_BIT}, // SERIAL_7E1_5
    {USART_DATA_7BITS, USART_PARITY_ODD,  USART_STOP_0_5_BIT}, // SERIAL_7O0_5
    {USART_DATA_7BITS, USART_PARITY_ODD,  USART_STOP_1_5_BIT}, // SERIAL_7O1_5

    {USART_DATA_8BITS, USART_PARITY_NONE, USART_STOP_1_BIT},   // SERIAL_8N1
    {USART_DATA_8BITS, USART_PARITY_NONE, USART_STOP_2_BIT},   // SERIAL_8N2
    {USART_DATA_8BITS, USART_PARITY_EVEN, USART_STOP_1_BIT},   // SERIAL_8E1
    {USART_DATA_8BITS, USART_PARITY_EVEN, USART_STOP_2_BIT},   // SERIAL_8E2
    {USART_DATA_8BITS, USART_PARITY_ODD,  USART_STOP_1_BIT},   // SERIAL_8O1
    {USART_DATA_8BITS, USART_PARITY_ODD,  USART_STOP_2_BIT},   // SERIAL_8O2
    {USART_DATA_8BITS, USART_PARITY_NONE, USART_STOP_0_5_BIT}, // SERIAL_8N0_5
    {USART_DATA_8BITS, USART_PARITY_NONE, USART_STOP_1_5_BIT}, // SERIAL_8N1_5
    {USART_DATA_8BITS, USART_PARITY_EVEN, USART_STOP_0_5_BIT}, // SERIAL_8E0_5
    {USART_DATA_8BITS, USART_PARITY_EVEN, USART_STOP_1_5_BIT}, // SERIAL_8E1_5
    {USART_DATA_8BITS, USART_PARITY_ODD,  USART_STOP_0_5_BIT}, // SERIAL_8O0_5
    {USART_DATA_8BITS, USART_PARITY_ODD,  USART_STOP_1_5_BIT}, // SERIAL_8O1_5

    {USART_DATA_9BITS, USART_PARITY_NONE, USART_STOP_1_BIT},   // SERIAL_9N1
    {USART_DATA_9BITS, USART_PARITY_NONE, USART_STOP_2_BIT},   // SERIAL_9N2
    {USART_DATA_9BITS, USART_PARITY_EVEN, USART_STOP_1_BIT},   // SERIAL_9E1
    {USART_DATA_9BITS, USART_PARITY_EVEN, USART_STOP_2_BIT},   // SERIAL_9E2
    {USART_DATA_9BITS, USART_PARITY_ODD,  USART_STOP_1_BIT},   // SERIAL_9O1
    {USART_DATA_9BITS, USART_PARITY_ODD,  USART_STOP_2_BIT},   // SERIAL_9O2
    {USART_DATA_9BITS, USART_PARITY_NONE, USART_STOP_0_5_BIT}, // SERIAL_9N0_5
    {USART_DATA_9BITS, USART_PARITY_NONE, USART_STOP_1_5_BIT}, // SERIAL_9N1_5
    {USART_DATA_9BITS, USART_PARITY_EVEN, USART_STOP_0_5_BIT}, // SERIAL_9E0_5
    {USART_DATA_9BITS, USART_PARITY_EVEN, USART_STOP_1_5_BIT}, // SERIAL_9E1_5
    {USART_DATA_9BITS, USART_PARITY_ODD,  USART_STOP_0_5_BIT}, // SERIAL_9O0_5
    {USART_DATA_9BITS, USART_PARITY_ODD,  USART_STOP_1_5_BIT}, // SERIAL_9O1_5
};

/**
  * @brief  串口对象构造函数
  * @param  串口外设地址
  * @retval 无
  */
HardwareSerial::HardwareSerial(usart_type* usart)
    : _USARTx(usart)
    , _callbackFunction(NULL)
    , _rxBufferHead(0)
    , _rxBufferTail(0)
{
    memset(_rxBuffer, 0, sizeof(_rxBuffer));
}

/**
  * @brief  串口中断入口
  * @param  无
  * @retval 无
  */
void HardwareSerial::IRQHandler()
{
    if(usart_flag_get(_USARTx, USART_RDBF_FLAG) != RESET)
    {
        uint8_t c = usart_data_receive(_USARTx);
        uint16_t i = (uint16_t)(_rxBufferHead + 1) % SERIAL_RX_BUFFER_SIZE;
        if (i != _rxBufferTail)
        {
            _rxBuffer[_rxBufferHead] = c;
            _rxBufferHead = i;
        }

        if(_callbackFunction)
        {
            _callbackFunction(this);
        }
        usart_flag_clear(_USARTx, USART_RDBF_FLAG);
    }
}

/**
  * @brief  串口初始化
  * @param  BaudRate: 波特率
  * @param  Config: 配置参数
  * @param  PreemptionPriority: 抢占优先级
  * @param  SubPriority: 从优先级
  * @retval 无
  */
void HardwareSerial::begin(
    uint32_t baudRate,
    SERIAL_Config_t config,
    uint8_t preemptionPriority,
    uint8_t subPriority
)
{
    gpio_type *GPIOx;
    gpio_init_type gpio_init_struct;
    uint16_t Tx_Pin, Rx_Pin;
    IRQn_Type USARTx_IRQn;

    if(_USARTx == USART1)
    {
        GPIOx = GPIOA;
        Tx_Pin = GPIO_Pin_9;
        Rx_Pin = GPIO_Pin_10;
        USARTx_IRQn = USART1_IRQn;

        crm_periph_clock_enable(CRM_GPIOA_PERIPH_CLOCK, TRUE);
        crm_periph_clock_enable(CRM_USART1_PERIPH_CLOCK, TRUE);
    }
    else if(_USARTx == USART2)
    {
        GPIOx = GPIOA;
        Tx_Pin = GPIO_Pin_2;
        Rx_Pin = GPIO_Pin_3;
        USARTx_IRQn = USART2_IRQn;

        crm_periph_clock_enable(CRM_GPIOA_PERIPH_CLOCK, TRUE);
        crm_periph_clock_enable(CRM_USART2_PERIPH_CLOCK, TRUE);
    }
    else if(_USARTx == USART3)
    {
        GPIOx = GPIOB;
        Tx_Pin = GPIO_Pin_10;
        Rx_Pin = GPIO_Pin_11;
        USARTx_IRQn = USART3_IRQn;

        crm_periph_clock_enable(CRM_GPIOB_PERIPH_CLOCK, TRUE);
        crm_periph_clock_enable(CRM_USART3_PERIPH_CLOCK, TRUE);
    }
    else
    {
        return;
    }

    gpio_default_para_init(&gpio_init_struct);
    gpio_init_struct.gpio_pins =  Tx_Pin | Rx_Pin;
    gpio_init_struct.gpio_drive_strength = GPIO_DRIVE_STRENGTH_STRONGER;
    gpio_init_struct.gpio_mode = GPIO_MODE_MUX;
    gpio_init_struct.gpio_pull = GPIO_PULL_NONE;
    gpio_init_struct.gpio_out_type  = GPIO_OUTPUT_PUSH_PULL;
    gpio_init(GPIOx, &gpio_init_struct);

    gpio_pin_mux_config(GPIOx, GPIO_GetPinSource(Tx_Pin), GPIO_MUX_7);
    gpio_pin_mux_config(GPIOx, GPIO_GetPinSource(Rx_Pin), GPIO_MUX_7);

    usart_init(_USARTx, baudRate, SERIAL_ConfigGrp[config].data_bit, SERIAL_ConfigGrp[config].stop_bit);
    usart_parity_selection_config(_USARTx, SERIAL_ConfigGrp[config].parity_selection);
    usart_transmitter_enable(_USARTx, TRUE);
    usart_receiver_enable(_USARTx, TRUE);

    nvic_irq_enable(USARTx_IRQn, preemptionPriority, subPriority);
    usart_interrupt_enable(_USARTx, USART_RDBF_INT, TRUE);

    usart_enable(_USARTx, TRUE);
}

/**
  * @brief  关闭串口
  * @param  无
  * @retval 无
  */
void HardwareSerial::end(void)
{
    usart_interrupt_enable(_USARTx, USART_RDBF_INT, FALSE);
    usart_enable(_USARTx, FALSE);
}
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

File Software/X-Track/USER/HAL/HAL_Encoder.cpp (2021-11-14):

#include "HAL.h"
#include "ButtonEvent/ButtonEvent.h"

static ButtonEvent EncoderPush(CONFIG_POWER_SHUTDOWM_DELAY);

static bool EncoderEnable = true;
static volatile int32_t EncoderDiff = 0;
static bool EncoderDiffDisable = false;

static void Buzz_Handler(int dir)
{
    static const uint16_t freqStart = 2000;
    static uint16_t freq = freqStart;
    static uint32_t lastRotateTime;

    if(millis() - lastRotateTime > 1000)
    {
        freq = freqStart;
    }
    else
    {
        if(dir > 0)
        {
            freq += 100;
        }

        if(dir < 0)
        {
            freq -= 100;
        }

        freq = constrain(freq, 100, 20 * 1000);
    }

    lastRotateTime = millis();
    HAL::Buzz_Tone(freq, 5);
}

static void Encoder_EventHandler()
{
    if(!EncoderEnable || EncoderDiffDisable)
    {
        return;
    }

    int dir = (digitalRead(CONFIG_ENCODER_B_PIN) == LOW ? -1 : +1);
    EncoderDiff += dir;
    Buzz_Handler(dir);
}

static void Encoder_PushHandler(ButtonEvent* btn, int event)
{
    if(event == ButtonEvent::EVENT_PRESSED)
    {
        EncoderDiffDisable = true;
    }
    else if(event == ButtonEvent::EVENT_RELEASED)
    {
        EncoderDiffDisable = false;
    }
    else if(event == ButtonEvent::EVENT_LONG_PRESSED)
    {
        HAL::Power_Shutdown();
        HAL::Audio_PlayMusic("Shutdown");
    }
}

void HAL::Encoder_Init()
{
    pinMode(CONFIG_ENCODER_A_PIN, INPUT_PULLUP);
    pinMode(CONFIG_ENCODER_B_PIN, INPUT_PULLUP);
    pinMode(CONFIG_ENCODER_PUSH_PIN, INPUT_PULLUP);

    attachInterrupt(CONFIG_ENCODER_A_PIN, Encoder_EventHandler, FALLING);

    EncoderPush.EventAttach(Encoder_PushHandler);
}

void HAL::Encoder_Update()
{
    EncoderPush.EventMonitor(Encoder_GetIsPush());
}

int32_t HAL::Encoder_GetDiff()
{
    int32_t diff = EncoderDiff;
    EncoderDiff = 0;
    return diff;
}

bool HAL::Encoder_GetIsPush()
{
    if(!EncoderEnable)
    {
        return false;
    }
    
    return (digitalRead(CONFIG_ENCODER_PUSH_PIN) == LOW);
}

void HAL::Encoder_SetEnable(bool en)
{
    EncoderEnable = en;
}

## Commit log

2021-03-19 首次上传
    [X-Track Box.STL, X-Track_Power.SchDoc, X-Track_Sheet.SchDoc]
2021-03-26 更新 v0.1
    ## [v0.1] - 2021-3-21
    * 1.框架搭建完成，全新系统架构
    * 2.更新3D Model，门板完美安装
    * 3.修复串口缓冲队列过载导致GPS解析连续失败的BUG
    * 4.添加长按开机功能
    * 5.添加计步显示
    * 6.速度显示使用kph为单位
    * 7.添加新的ButtonEvent库
    * 8.添加Filters数字滤波器库
    * 9.添加新的TonePlayer库
    * 10.格式化LIS3DMDL库的代码
    * 11.格式化LISM6DSM库的代码
    * 12.添加新的简易表盘页面
    * 13.为LiveMap页面添加group，优化Encoder交互
    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
    [X-Track Box.STL]
2021-04-19 更新 v0.2
    ## [v0.2] - 2021-4-19
    * 1.添加ArtDesign工程，使用Adobe Illustrator
    * 2.添加异步无锁Buffer库：PingPongBuffer
    * 3.删除离线图片和字体转换工具
    * 4.修改页面ID格式：DialplatePage->Pages/Dialplate
    * 5.添加消息发布订阅框架：DataCenter
    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
2021-05-12 更新 v0.3
    ## [v0.3] - 2021-5-12
    * 1.lvgl迁移至v8.0.0
    * 2.PingPongBuffer转移至App/Utils/DataCenter，以提供无锁的线程安全的数据块访问，添加volatile关键字
    * 3.VS工程在Debug下启用AddressSanitizer，捕获异常的内存操作
    * 4.Heap和Stack调整
    * 5.更新ButtonEvent库
    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
2021-05-16 更新 v0.4
    ## [v0.4] - 2021-5-16
    * 1.lvgl更新
    * 2.支持导出GPX格式的轨迹记录文件，推荐使用[GPXSee](https://github.com/tumic0/GPXSee)查看轨迹
    * 3.Clock_info_t结构体成员单词全拼
    * 4.LiveMap页面更新，改进的操作方式与显示特效
    * 5.去除MAP数据映射宏，使用lv_map替代
    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
2021-05-23 更新 v0.5
    ## [v0.5] - 2021-5-23
    * 1.添加SystemInfos页面
    * 2.添加IMU和地磁MAG数据处理节点
    * 3.修改轨迹记录默认文件名
    * 4.规范lv_event成员参数获取方式
    * 5.修复DataCenter缓冲区读取释放BUG
    * 6.添加Version.h存放版本信息
    * 7.HAL::GPS_Info_t添加hour_utc成员
    [Config.h, HAL.cpp, HAL_Power.cpp]
2021-05-31 更新 v0.6
    ## [v0.6] - 2021-5-31
    * 1.更新lvgl
    * 2.添加App_Uninit()，绑定关机事件
    * 3.添加DP_LIST.inc，更优雅的数据处理节点注册方式
    * 4.添加IMU/MAG_Commit，向数据中心提交数据
    * 5.添加StorageService数据储存服务，使用JSON格式储存数据
    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
2021-06-05 更新 v0.7
    ## [v0.7] - 2021-6-5
    * 1.更新拆分STL模型文件
    * 2.TonePlayer转移至App/Utils
    * 3.在关机时自动保存正在记录的轨迹文件
    * 4.优化轨迹记录操作体验
    * 5.DataCenter合并定时器回调到AccountEvent
    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
    [X-Track Box.STL, 外壳-主体.STL, 外壳-侧盖.STL]
2021-06-05 上传实物图片
2021-06-07 增加操作视频
2021-06-07 更新README
2021-06-15 更新 v0.8
    ## [v0.8] - 2021-6-15
    * 1.格式化所有代码
    * 2.APP_Init添加ACCOUNT_SEND_CMD，简化Account通知调用
    * 3.dataCenter("Bilibili") -> dataCenter("CENTER")
    * 4.添加SysConfig节点，用于保存系统设置
    * 5.Power节点使用Account通知方式调用MusicPlayer，而不使用HAL::Audio_PlayMusic
    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
2021-06-24 更新 v0.9
    ## [v0.9] - 2021-6-24
    * 1.更新ButtonEvent，支持EVENT_LONG_PRESSED_RELEASED
    * 2.调整lvgl内存池，32KB -> 64KB
    * 3.HAL_GPS支持读取csv格式的文件，在PC上模拟位置变化
    * 4.更新LiveMap页面，支持实时绘制运动轨迹，支持自适应分辨率动态加载地图
    * 5.更新StartUp页面，移除默认样式，并在开机动画过程中屏蔽Encoder事件
    * 6.修复SystemInfos页面因为忘记释放style.focus导致的内存泄漏
    * 7.优化DataCenter的Account的cache申请失败判断逻辑
    * 8.添加lv_allocator，使用lvgl接管std::vector内存管理实现
    * 9.更新MapConv，MapKeyRootName -> MapFilePath，ConvertMapTile() -> ConvertPosToTile()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
    [HAL_Encoder.cpp]
2021-07-01 更新 v1.0
    ## [v1.0] - 2021-7-1
    * 1.更新lvgl v8.1.0 dev
    * 2.添加TrackFilter数据处理节点，储存过滤后的拐点坐标
    * 3.优化DP_Clock RTC自动校准
    * 4.优化DP_GPS提示音播放，添加cache，使用Publish向订阅者推送数据，减少定时轮询拉取
    * 5.添加GPX_Parser，支持直接解析GPX数据还原轨迹
    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
2021-07-02 Config.h 整理
2021-07-07 更新 v1.1
    ## [v1.1] - 2021-7-7
    * 1.支持在GPX中记录海拔和时间，可在GPXSee查看爬升和速度统计
    * 2.更新StartUp页面，使用匿名函数回调
    * 3.更新SystemInfos页面，添加Author署名和Build时间，电池状态 State -> Status
    * 4.更新lvgl
    * 5.更新GPX生成库，添加遗漏的time_成员
    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
2021-07-11 更新 v1.2
    ## [v1.2] - 2021-7-11
    * 1.添加StackInfo库，支持在裸机环境下测量栈使用情况
    * 2.Stack_Size 0x2500 -> 0x1000
    * 3.更新DP_Storage数据储存节点，支持拉取储存器使用情况
    * 4.更新Config.h，添加显示器分辨率和缓冲区配置
    * 5.添加触控逻辑
    * 6.修复StatusBar充电动画闪烁的BUG，添加SD卡图标
    * 7.SystemInfos页面添加SD卡状态监测显示
    [Config.h]
2021-07-14 更新 Tools
    * 1.更新文件批量重命名工具，支持自定义扩展名
    * 2.添加RenameBin_PNG.bat
2021-07-17 更新 外壳-主体.STL
    [外壳-主体.STL, 外壳-主体fix1.stl]
2021-07-18 更新 v1.3
    ## [v1.3] - 2021-7-18
    * 1.Config.h添加传感器使能配置选项
    * 2.DataCenter添加cache自动初始化置0
    * 3.添加Microsoft官方TileSystem解析库，供mapConv调用
2021-07-23 Add files via upload
    主控封装改为48PIN-LQFP
    [X-Track_Power.SchDoc, X-Track_Sheet.SchDoc, X_TRACK.PrjPcb]
2021-07-23 更新 v1.4
    ## [v1.4] - 2021-7-24
    * 2.更新MapConv，统一使用GPS_Transform校准坐标
    * 3.更新HAL::GPS模拟，支持航向和速度模拟
    * 4.修改HAL::GPS_Info_t的 compass -> course
    * 5.使用合入lvgl主线的lv_anim_timeline，使用lv_anim_timeline_wrapper封装动画组
    * 6.更新StartUp页面，新的开机动画
    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
2021-07-24 Update HAL.cpp
    添加启动版本信息
2021-07-24 Update X-Track.hex
    更新HEX
2021-07-26 删除tb链接中追踪用途的参数
2021-07-27 更新 README.md
2021-08-01 更新 v1.5
    * 2.调整Stack size: 0x1500 -> 0x2000，处理更大的JSON文件
    * 3.更新Storage节点，支持获取SD卡容量，支持自动获取地图缩放等级(OSM)
    * 4.优化GPS节点，减少在GPS信号不稳定时频繁的提示音
    * 5.优化SportStatus节点，支持在JSON文件中配置体重
    * 6.优化SysConfig节点，支持在JSON配置默认经纬度，地图源(Bing/OSM)，soundDisable -> soundEnable
    * 7.重构MapConv地图坐标转换器，支持动态配置地图源，地图坐标数据类型uint32_t -> int32_t，合并TileSystem和GPS_Transform
    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
2021-08-03 添加了新的地图转换工具
2021-08-05 Update HAL_Power.cpp
    更改95行 把BAT_CHG_DET_PIN配置为上拉 203行更改了充电检测条件
2021-08-05 添加焊接指北
2021-08-07 更新 v1.6
    ## [v1.6] - 2021-8-7
    * 1.更新ArtDesign，新的导航箭头设计
    * 2.更新lv_drivers，去除坐标超界警告
    * 3.去除lv_examples，减少工程体积
    * 4.调整模拟器的LV_FS_PC_PATH定义，指定到Software所在目录，方便读取地图
    * 5.开机页面重命名: StartUp -> Startup
    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
2021-08-07 更新 Tools
2021-08-08 删除MapConv_WGS84
2021-08-08 转移批量重命名工具
2021-09-03 更新 v1.7
    ## [v1.7] - 2021-9-3
    * 1.调整Heap_Size 0x00002000 -> 0x00000200
    * 2.调整lvgl内存池大小，LV_MEM_SIZE 72K -> 80K
    * 3.更新lv_drivers
    * 5.DataCneter使用lvgl内存池
    * 6.使用std::abs()替代宏实现的ABS()
    * 7.更新DP_Storage
    * 8.更新DP_SysConfig，调整结构体成员，添加timeZone和mapExtName，在关机时保存位置
    * 9.更新DP_TrackFilter，使用地图上的Point格式替代旧的经纬度
    * 10.更新DP_TzConv，GMT_OffsetHours -> sysCfg.timeZone
    * 11.更新HAL.h，添加Memory_DumpInfo()堆栈使用统计
    * 12.更新HAL_GPS模拟，修复diffTime = 0导致的gpsInfo.speed = inf
    * 13.更新Config.h，添加LiveMap的Debug模式配置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
    [Config.h, HAL.cpp, main.cpp]
2021-09-04 关闭Debug模式下的ASAN
2021-09-12 添加.gitignore
2021-09-14 更新 v1.8
    ## [v1.8] - 2021-9-14
    * 1.StackInfo库 StackInfo_GetSize -> StackInfo_GetTotalSize
    * 2.移除多余的RTE/Device
    * 3.Common/HAL模拟器实现转移到Simulator\LVGL.Simulator\HAL
    * 4.VS模拟器HAL_GPS适配新的GPX_Parser
    * 5.更新lv_conf.h LV_SHADOW_CACHE_SIZE 8 -> 32, LV_CIRCLE_CACHE_SIZE 8 -> 32
    * 6.更新lv_fs_pc，去除无用代码
    * 7.更新LVGL.Simulator，lv_png_init和lv_monkey_create转移至App_Init初始化
    * 8.更新lvgl主程序
    * 9.更新App初始化，调整Storage和SysConfig的初始化顺序，修复错误的全屏滑动
    * 10.更新DataProc初始化，center实例化转移到函数外部，DP_DEF宏全大写
    * 11.更新DataProc声明，ConvTime -> MakeTime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
    [Config.h, HAL.cpp, HAL_Display.cpp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]
2021-09-21 修复v1.8 crash问题
    撤销LV_SHADOW_CACHE_SIZE更改
2021-10-01 更新 v1.9
    ## [v1.9] - 2021-10-1
    * 1.修复ArduinoAPI中未初始化变量
    * 2.去除lv_fs_pc中未使用的函数
    * 3.去除unistd.h
    * 4.更新lvgl主程序
    * 5.Resource管理器，Resource. -> ResourcePool::
    * 6.添加Utils/PointContainer组件
    * 7.DP_Storage添加地图缩放级别错误检查
    * 8.DP_TackFilter添加PointContainer组件适配，减少75%内存占用，极大提升轨迹录制容量
    * 9.多段线组件lv_multi_line -> lv_poly_line
    * 10.更新ArduinoJson
    * 11.Display_DumpCrashInfo report -> info
    * 12.更新HAL_Power，不使用ADC中断模式
    [HAL_Display.cpp, HAL_Power.cpp, SPI.cpp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]
2021-10-02 添加地图下载教程
2021-11-08 更新 v2.0
2021-11-13 更新
    1.更新lvgl
    2.使用event携带user_data
    3.优化new重载
2021-11-14 发布 v2.0
    ## [v2.0] - 2021-11-14
    * 1.Arduino API底层重构
    * 2.添加MillisTaskManager任务调度器
    * 3.lvgl使用标准memset和memcpy
    * 4.更新lvgl v8.1.0
    * 5.DataCenter错误码枚举 ERROR_XXX -> RES_XXX
    * 6.修改DP节点的结构体初始化方式，不使用默认初始化
    * 7.优化DP_SportStatus在临时信号丢时的数据统计处理
    * 8.修复StorageService文件结尾读取错误导致的crash
    * 9.添加lv_settings，暂未移植
    * 10.添加传感器自动扫描，防止未安装传感器导致的开机卡死
    * 11.使用event携带user_data
    * 12.优化new重载
    * 13.修复HAL_Power错误的关机处理
    [HAL_Power.cpp]
2021-11-18 修复充电检测引脚上拉
2021-12-16 更新 v2.1
    ## [v2.1] - 2021-12-16
    * 1.ArduinoAPI更新
    * 2.将LVGL部分绘图函数放到RAM执行，提升运行效率，不删除.sct文件
    * 3.Adafruit_ST778驱动更新，适配新的SPI库
    * 4.更新lvgl v8.1.1 dev
    * 5.lv_conf.h更新，使用新的缩进
    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
2021-12-21 添加遗漏的.sct文件
2021-12-21 优化IMG和MAG初始化
2021-12-21 修复x64模式下size_t和uint32_t隐式转换的部分warning
2021-12-21 当 I2C_Scan() <= 0 时不初始化sensors
2021-12-30 更新 v2.2
    ## [v2.2] - 2021-12-30
    * 1.添加系统软件架构说明
    * 2.去除弃用的_LIS3MDL
    * 3.修复使用strncpy()遗漏的'\0'结束符
    * 4.添加AT32F435移植
    * 5.LV_DISP_DEF_REFR_PERIOD 20ms -> 16ms
    * 6.LV_MEM_SIZE 78KB -> 70KB
    * 7.默认开启PNG解码器，受限于内存MCU无法使用
    * 8.添加轨迹记录状态指示渐变动画
    * 9.添加文本动画组件lv_anim_label，替换旧的lv_label_anim_effect
    * 10.去除lv_settings
    [Arduino.c, Config.h, HAL_Display.cpp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]
2022-01-30 更新 v2.3
    ## [v2.3] - 2022-1-30
    * 1.Arduino API 更新
    * 2.添加wdg看门狗，系统卡死时自动重启
    * 3.lvgl主程序更新
    * 4.添加低内存开销(<50KB)的PNGdec解码器（暂不启用）
    * 5.更新LiveMap，适配新的PNGdec
    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
2022-01-30 更新 v2.3
    * 6.更新StatusBar，调整字体，新的轨迹记录状态指示渐变动画
    * 7.ResourceManager从PageManager分离
    * 8.lv_anim_label组件从lv_ext分离
    * 9.添加lv_img_png组件
    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
2022-02-27 添加pack
2022-02-27 更新 v2.4
    ## [v2.4] - 2022-2-27
    * 1.添加指定的Pack
    * 2.AT32F435 Pack更新 2.0.0 -> 2.0.6
    * 3.__wfi() -> __WFI()
    * 4.移除lv_demo_conf.h
    * 5.更新lvgl v8.3.0 dev
    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
2022-03-18 更新v2.5
    ## [v2.5] - 2022-3-18
    * 1.更新Adafruit_ST7789，支持颜色大小端切换
    * 2.更新CommonMacro库
    * 3.更新lv_conf.h
    * 4.去除lv_lib_png，使用lvgl内置PNG库
    * 5.DataProc 添加 DATA_PROC_INIT_STRUCT() 结构体初始化
    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
2022-04-10 更新 v2.6
    ## [v2.6] - 2022-4-10
    * 2.整理 Core，统一移动到 MDK-ARM_F4XX/Platform 中
    * 3.更新lvgl主程序
    * 4.LV_SPRINTF_CUSTOM使能，减少FLASH占用
    * 5.account->Pull()操作全部添加返回值检查
    * 6.PageManager更新
    * 7.页面Template添加生命周期LOG
    * 8.DataCenter添加ACCOUNT_DISCARD_READ_DATA
    * 9.__WFI() -> __wfi()
    * 10.main.cpp复用
    * 11.修复[TscanCode](https://github.com/Tencent/TscanCode)静态扫描出来的漏洞
    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
    [Arduino.c, HAL_Display.cpp, HAL_Power.cpp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]
2022-05-20 添加MCU选型
2022-06-03 更新 v2.7
    ## [v2.7] - 2022-6-3
    * 1.Adafruit_ST7789: 添加多分辨率支持; 去除drawRGBBitmap(); 删除Adafruit_ST7789V2
    * 2.AT32F403A: 更新Platform; 更新链接脚本，将lv_tlsf和font_bahnschrift_13载入RAM提升访问性能
    * 3.AT32F435: 更新Platform
    * 4.lv_conf.h: 同步主线配置; 使能LV_COLOR_SCREEN_TRANSP; WIN平台 GetTickCount() -> timeGetTime()
    * 5.lvgl: 同步 commit 941d95b0491a1e78fadeeb5ea8aa552f82669336
    * 6.App.cpp: 自动创建未设置的默认group; 设置scr的透明度和颜色; 添加rootStyle
    * 7.PageManager: 添加PageBase.cpp; 规范成员变量命名; 添加Replace()方法; 支持设置RootDefaultStyle; 修复PM_Drag不生效
    * 8.Pages/_Tempalte: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
    [HAL_Display.cpp, HAL_Power.cpp, main.cpp]
2023-09-22 fix(Pages/_Template): fix warning
    X-TRACK/Software/X-Track/Linux/../USER/App/Pages/_Template/Template.cpp: In member function ‘virtual void Page::Template::onCustomAttrConfig()’:
    X-TRACK/Software/X-Track/Linux/../Simulator/LVGL.Simulator/lvgl/src/misc/lv_log.h:123:102: warning: format not a string literal and no format arguments [-Wformat-security]
    123 | # define LV_LOG_USER(...) _lv_log_add(LV_LOG_LEVEL_USER, __FILE__, __LINE__, __func__, __VA_ARGS__)
    | ^
    X-TRACK/Software/X-Track/Linux/../USER/App/Pages/_Template/Template.cpp:17:5: note: in expansion of macro ‘LV_LOG_USER’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
2023-09-22 fix(Simulator/Linux): fix map loader path error
    [Config.h]
2024-09-27 fix(PageManager): fix StashPop return value error
    See https://github.com/FASTSHIFT/X-TRACK/issues/112
